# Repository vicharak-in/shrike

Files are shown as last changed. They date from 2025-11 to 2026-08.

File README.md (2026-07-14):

# Shrike 



Shrike is a family of low cost affordable FPGA development board along with a host microcontroller. 
Currently the family features these two members -: 

1. Shrike-lite (FPGA with RP2040) 
2. Shrike      (FPGA with RP2350)
3. Shrike-fi   (FPGA with ESP32-S3) 

And a lot version under development.

We usually work on very complex FPGA-based projects built around [Vaaman](https://vicharak.in/vaaman) and its upcoming series. However, Shrike is a passion project at Vicharak, driven by our love for engineering across both embedded microcontrollers and FPGAs.

Our goal is to make FPGAs accessible to everyone by offering robust toolchains, high-quality hardware, and strong ecosystem support. We’re committed to keeping the hardware prices extremely low, and every piece of software for Shrike will be completely open-source.

We at vicharak have kept in mind need of a learner, maker and a hobbyist while designing this art. This dev board will be your stepping stone in the field of FPGA, reconfigurable and heterogenous computing.

We invite contributors from all over the world to join us in this mission. Together, let’s make FPGA technology truly accessible to all. 

### Get the Hardware 

Shrike-lite the RP2040 version of the family is available at our store for worldwide shipping and the Shrike RP2350 version will be available on the crowdsupply soon. You can follow the links below to get both.

#### 1. [Shrike-lite](https://store.vicharak.in/?product=shrike&post_type=product&name=shrike&v=13b5bfe96f3e)

#### 2. [Shrike](https://www.crowdsupply.com/vicharak/shrike)

#### 3. [Shrike-fi](https://store.vicharak.in/?product=v002743)

### Board level Block Diagram

<div align="center">

shrike

</div>

### Key Features : 

| **Feature** | **Shrike** | **Shrike-lite** |**Shrike-fi** |
|:---:|:---:|:---:|:---:|
| FPGA | 1120 × 5-input LUTs | 1120 × 5-input LUTs | 1120 × 5-input LUTs|
| MCU | RP2350 | RP2040 | ESP32-S3 |
| PMOD Compatible Connector | ✅ | ✅ | ✅ |
| Breadboard Compatible | ✅ | ✅ | ✅ |
| FPGA ↔ MCU IO Interface | ✅ | ✅ | ✅ |  
| Flash (QSPI) | 4 MB | 4 MB | 8 MB |
| User LEDs | 2 | 2 | 2 |
| USB Type-C (Power & Programming) | ✅ | ✅ | ✅ |
| WiFi | ❌ | ❌ | ✅ |
| BLE | ❌ | ❌ | ✅ |
| Optional Add-on Features |
| PSRAM (QSPI) ( Optional ) | ❌ | ❌ | Upto 8 MB |
| BMS On Board ( Optional ) | ❌ | ❌ | ✅ | 

#### **Note**

The optional add on for the Shrike-fi are not soldered in the base version , board version with these part soldered will be launched at later date.
However you can solder them yourself in the base version as well read more [here](https://vicharak-in.github.io/shrike/hardware_overview.html#shrike-hardware-overview).

### Check out 
 1. [Documentation](https://vicharak-in.github.io/shrike/index.html)
 2. [Pin_outs](https://vicharak-in.github.io/shrike/shrike_pinouts.html)
 3. [FPGA_CPU_Interconnect](https://vicharak-in.github.io/shrike/shrike_pinouts.html#fpga-rp2040-communication-pin-outs)

## Shrike Projects

Want to see what people have built with Shrike , or show off your own build?

Check out **[shrike_projects](https://github.com/vicharak-in/shrike_projects)**.

The [`examples/`](examples/) folder here is focused on *teaching* , one
concept per example. Built something cool with your Shrike? Add it to the
projects repo , creative scope is unlimited.

Not sure which repo your contribution belongs in? See the
[classification criteria](EXAMPLE_OR_PROJECT.md).

## 📫 Join our communities at :
  
   [](https://discord.com/invite/EhQy97CQ9G)  &nbsp; [](https://x.com/Vicharak_In)  &nbsp; [](https://discuss.vicharak.in/)  &nbsp; [](https://www.linkedin.com/company/vicharak-in)  &nbsp; [](https://www.reddit.com/r/Vicharak/)  &nbsp;

### Note
 
We are building a ecosystem for learners , makers and hobbyist around shrike and the projects that will follow in future, thus we request you contribution in the same. Join our communities across all the platforms, pitch and showcase your ideas with Shrike. 

Thank You 

## Contribution Guideline  

Your contribution to the Shrike project are always welcome.
To contribute fork the project test your changes and create a PR. Few things in to keep in mind for better contribution. 
Please read the Contribution [Guide](./CONTRIBUTING.md) to know them.

### What to contribute ? 

You can contribute the project's and example's that you have designed on Shrike or any utils that you might have designed.

We also have live bounty from time to time check it [here](./bounty.md) 

## LICENSE 

### Software

This project’s software is licensed under the GNU General Public License v2.0 (GPL-2.0).
See the [LICENSE](./LICENSE.md)for details.

### Hardware

This project’s hardware designs (HDL/RTL, schematics, PCB files, constraints, etc.) are licensed under the CERN Open Hardware License v1.2.
See [LICENSE_HW](./LICENSE_HW.md) for details.

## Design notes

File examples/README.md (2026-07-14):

# Shrike Examples — Difficulty Reference

🟢 Beginner &nbsp;&nbsp; 🟡 Intermediate &nbsp;&nbsp; 🔴 Advanced

| # | Example | Folder Name | Category | Difficulty | Why |
|---|---|---|---|---|-----|
| 1 | LED Blink | `led_blink` | Getting Started | 🟢 Beginner | Single output signal, no state |
| 2 | Breathing LED | `breathing_led` | Getting Started | 🟢 Beginner | Simple PWM counter, single module |
| 3 | Button Debouncer | `button_debouncer` | Getting Started | 🟢 Beginner | Basic FSM, introduces synchronous logic |
| 4 | LED PMOD | `pmod_led_blink` | GPIO & I/O | 🟢 Beginner | Direct pin drive, PMOD pinout awareness |
| 5 | Logic Gates | `logic_gates` | Digital Logic | 🟢 Beginner | Pure combinational, no clock needed |
| 6 | 4-Bit Counter | `counter_4bit` | Signal & Timing | 🟢 Beginner | Sequential logic, introduces registers |
| 7 | PMOD Patterns | `pmod_patterns` | GPIO & I/O | 🟡 Intermediate | Sequenced output, simple state machine |
| 8 | GPIO Extender 8-Pin | `gpio_extender_8pin` | GPIO & I/O | 🟡 Intermediate | FPGA-to-RP2040 IO bridge, bus awareness |
| 9 | GPIO Extender 14-Pin | `gpio_extender_14pin` | GPIO & I/O | 🟡 Intermediate | FPGA-to-RP2040 IO bridge, wider bus |
| 10 | I2C LED | `i2c_led` | Communication Protocols | 🟡 Intermediate | I2C state machine, clock stretching awareness |
| 11 | SPI Loopback LED | `spi_loopback_led` | Communication Protocols | 🟡 Intermediate | SPI shift register, MISO/MOSI routing |
| 12 | UART LED | `uart_led` | Communication Protocols | 🟡 Intermediate | UART RX framing, baud clock generation |
| 13 | Morse Blink | `morse_blink` | Communication Protocols | 🟡 Intermediate | UART input, timing/state machine, serial-to-LED translation |
| 14 | UART ALU | `uart_alu` | Communication Protocols | 🟡 Intermediate | UART + datapath, multi-module design |
| 15 | PLL Oscillator | `pll_oscillator` | Signal & Timing | 🟡 Intermediate | PLL primitive instantiation, clock domain |
| 16 | PWM 4-Channel | `pwm_4ch` | Signal & Timing | 🟡 Intermediate | Multi-channel counter, duty cycle control |
| 17 | Ultrasonic Sensor | `ultrasonic_sensor` | Sensors & Peripherals | 🟡 Intermediate | Pulse timing, echo measurement FSM |
| 18 | WS2812 LED | `ws2812_led` | Sensors & Peripherals | 🟡 Intermediate | Precise bit-bang timing, serial protocol |
| 19 | Quadrature Decoder | `quadrature_decoder` | Sensors & Peripherals | 🟡 Intermediate | Quadrature decoding, direction detection, signed position/speed tracking |
| 20 | Protocol Translator | `protocol_translator` | Communication Protocols | 🟡 Intermediate | UART, SPI, and I2C protocol conversion through bridge logic |
| 21 | Stack Processor | `stack_processor` | Processors & CPUs | 🔴 Advanced | Custom ISA, stack-based execution, SPI host |
| 22 | Vector-4 CPU | `vector4_cpu` | Processors & CPUs | 🔴 Advanced | Full 4-bit SAP CPU: ALU, PC, registers, decode |
| 23 | Vector-8 CPU | `vector8_cpu` | Processors & CPUs | 🔴 Advanced | Full 8-bit SAP CPU: wider datapath, more opcodes |
| 24 | PicoRV32 RISC-V | `shrike_picorv32` | Processors & CPUs | 🔴 Advanced | Full RV32I soft CPU, runtime-programmable over SPI; fits the 1K-LUT fabric |

---

## Summary by Difficulty

| Difficulty | Count | Examples |
|---|---|---|
| 🟢 Beginner | 6 | `led_blink`, `breathing_led`, `button_debouncer`, `pmod_led_blink`, `logic_gates`, `counter_4bit` |
| 🟡 Intermediate | 14 | `pmod_patterns`, `gpio_extender_8pin`, `gpio_extender_14pin`, `i2c_led`, `spi_loopback_led`, `uart_led`, `morse_blink`, `uart_alu`, `pll_oscillator`, `pwm_4ch`, `ultrasonic_sensor`, `ws2812_led`, `quadrature_decoder`,`protocol_translator` |
| 🔴 Advanced | 4 |  `stack_processor`, `vector4_cpu`, `vector8_cpu`, `shrike_picorv32` |

---

---

## Looking for the bigger projects?

Application projects built on Shrike (Wi-Fi screen mirror, crypto mining,
spell autocorrector, seven-segment clock, and more) now live in their own
repo — moved with their **full commit history and contributor credit**:

**➡️ https://github.com/vicharak-in/shrike_projects**

This folder contains the curated *teaching examples*. Want a guided path
through them? See the Shrike FPGA Course.

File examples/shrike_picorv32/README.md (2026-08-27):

# shrike_picorv32

**Difficulty:** Advanced
**Uses MCU:** Yes
**External Hardware:** None

## Overview

This example runs Claire Wolf's [PicoRV32](https://github.com/YosysHQ/picorv32)
**RV32I** CPU on the SLG47910 ForgeFPGA of a Shrike-lite board, and makes it
**runtime-programmable**: the host MCU streams a program into the FPGA over SPI
and starts the CPU — no re-synthesis, no new bitstream. Flash the bitstream once,
then load and run any number of programs.

The full 32-register RV32I core fits the 1K-LUT-class fabric with both its
register file and a 32-word instruction memory in on-die BRAM, rewritten at
runtime over SPI. It ships a conformance suite — themed, self-checking programs
that together cover the complete RV32I base ISA — each reporting PASS/FAIL on two
GPIO pins the MCU reads back.

## Expected Output

```
Flashing PicoRV32 bitstream to FPGA...
[shrike_flash] FPGA programming done.
regalu: testing add sub sll srl sra and or xor slt sltu
result = 3 -> PASS  (verified: add sub sll srl sra and or xor slt sltu)
```

## Compatibility

| Board | MCU | Status |
|---|---|---|
| Shrike-lite | RP2040 | Tested and working |
| Shrike | RP2350 | Untested |
| Shrike-fi | ESP32-S3 | Untested |

> The FPGA bitstream is the same across all boards; only the MCU firmware pin
> map differs.

## Hardware Setup

No external hardware required. SPI and the two result pins are already wired
between the FPGA and the RP2040 on the Shrike-lite PCB:

| FPGA pin | Signal | RP2040 pin | Direction |
|---|---|---|---|
| GPIO3  | `spi_sck` | GPIO2  | MCU → FPGA |
| GPIO4  | `spi_ss_n` | GPIO1  | MCU → FPGA |
| GPIO5  | `spi_mosi` | GPIO3  | MCU → FPGA |
| GPIO17 | `result_bit0` | GPIO15 | FPGA → MCU |
| GPIO18 | `result_bit1` | GPIO14 | FPGA → MCU |

The FPGA never drives MISO — results come back on the two GPIO result pins — so
the CPU is reset and run entirely via SPI commands.

## How It Works

```
MCU --SPI--> spi_target --> bootloader --> instruction RAM (BRAM4..7, 32 words)
picorv32 <--mem bus--> instruction RAM      (fetch, 1-cycle wait)
picorv32 <--mem bus--> register file (BRAM0..3, 32 regs)
picorv32 --store 0x4xxxxxxx--> result latch --> GPIO17/18 --> RP2040
```

The MCU streams a program into the 32-word instruction RAM over SPI while the CPU
is held in reset, then releases it to run. Both the register file (BRAM0-3) and
the instruction RAM (BRAM4-7) live in on-die BRAM instead of fabric flip-flops,
which is what lets the full 32-register core fit. A store to any `0x4xxxxxxx`
address latches the low 2 bits onto the result pins (it clears on every reload).
Because the SLG47910 BRAM read is synchronous, the core carries a 1-cycle
read-latency fix (`CF1`) so register and instruction reads return valid data.

Sources: `picorv32.v` (core + `SHRIKE PATCH` size optimisations),
`shrike_picorv32_top.v` (top + SPI bootloader + result latch),
`picorv32_imem_bram.v` (instruction RAM), `picorv32_regs_bram.v` (register file).

## Quick Start (Pre-Built Bitstream)

Copy the bitstream to the board's filesystem and run the driver — with Thonny or
`mpremote`, whichever you prefer (the driver flashes the bitstream into the FPGA
itself at runtime, so the `.bin` just needs to be on the board).

**Thonny (GUI):** use the file panel to copy `bitstream/shrike_picorv32.bin` to
the board, then open `firmware/micropython/shrike_picorv32.py` and Run it.

**mpremote (CLI):** `pip install mpremote` (auto-detects the board):
```bash
mpremote fs cp bitstream/shrike_picorv32.bin :shrike_picorv32.bin
mpremote run firmware/micropython/shrike_picorv32.py
```

Either way, observe `result = 3 -> PASS` over USB serial. To run another part of
the suite, uncomment a different `ACTIVE = ...` line and re-run.

## Running & Editing Programs

Edit `shrike_picorv32.py` and re-run it (in Thonny, or `mpremote run` — which
executes your local copy, so no re-copy needed). Uncomment a different
`ACTIVE = ...` line to switch tests, or add your own program to `TESTS` (below).
To run standalone at boot (no host attached), save the file on the board as
`main.py`.

## Build From Source

### Step 1 — Open in Go Configure

Launch Go Configure Software Hub and open the included `shrike_picorv32.ffpga`
(target chip **SLG47910 (BB)**). It lists every source in order and holds the
complete pinout. From scratch, add the sources with the top module last:
`picorv32_regs_bram.v`, `picorv32.v`, `picorv32_imem_bram.v`, `spi_target.v`,
`shrike_picorv32_top.v`.

### Step 2 — Enable BRAM

The register file uses BRAM0-3 and the instruction RAM uses BRAM4-7, so enable
**both** BRAM banks (North = BRAM0-3, South = BRAM4-7). The BRAM ports and bank
clock feeds must also be pinned — the committed `.ffpga` holds all of these.

### Step 3 — Clock + generate

The fabric runs from the PLL at 25 MHz (the `pll_*` pins program it from fabric
logic, per Renesas AN-003; dividers give `50 MHz × 21 / (1×7×6) = 25 MHz`). Click
**Synthesize** then **Generate Bitstream**, and copy the produced
`FPGA_bitstream_MCU.bin` to `bitstream/shrike_picorv32.bin`.

## The RV32I Conformance Suite

`firmware/micropython/shrike_picorv32.py` holds several themed, self-checking
≤32-word programs in a `TESTS` dictionary. Together they cover the complete RV32I
base ISA — all 37 instructions:

| Program (`ACTIVE`) | Instructions tested |
|---|---|
| `regalu` | add sub sll srl sra and or xor slt sltu |
| `immalu` | addi slli srli srai andi ori xori slti sltiu lui auipc |
| `branch` | beq bne blt bge bltu bgeu (taken **and** not-taken) |
| `jumps`  | jal jalr (transfer **and** link register) |
| `loads`  | lw lh lhu lb lbu (sign/zero-extension) |
| `store_sw` / `store_sh` / `store_sb` | sw / sh / sb |

Pick one with an `ACTIVE = ...` line and run. A pass latches **3** (both bits);
`1` = ran but wrong value, `0` = never reached the store (trap/hang). Each program
was validated so injecting a fault into any instruction it tests makes it stop
returning 3, so a pass confirms those instructions are correct.

To run your own program, add a `name: (description, [words])` entry to `TESTS`,
point `ACTIVE` at it, and re-run — no re-synthesis. Programs are capped at **32
words** (`PC_W = 7` in `picorv32.v`, an area optimisation matching the instruction
RAM depth). The 2 result bits give a readable range of 0-3.

## PicoRV32 Configuration

Locked parameters in `shrike_picorv32_top.v` for a minimal full-RV32I build:

| Parameter | Value | Reason |
|---|---|---|
| `ENABLE_REGS_16_31` | 1 | full RV32I — all 32 registers |
| `ENABLE_REGS_DUALPORT` | 0 | single read port — matches the BRAM regfile |
| `BARREL_SHIFTER` | 0 | serial shift — avoids a 32-bit mux tree |
| `COMPRESSED_ISA` | 0 | no RVC decoder |
| `CATCH_MISALIGN` / `CATCH_ILLINSN` | 0 | no trap logic |
| `ENABLE_MUL` / `DIV` / `IRQ` / `COUNTERS` | 0 | no M-ext / IRQ / CSR counters |

The core in `picorv32.v` also carries the `SHRIKE PATCH` size optimisations (BRAM
register file, shared-adder datapath, 7-bit PC, narrowed memory interface) plus
two correctness fixes (`CF1` read-latency wait-state, `CF2` ECALL/EBREAK halt);
`grep "SHRIKE PATCH"` / `grep "CORRECTNESS FIX"` finds every site.

## Licence

PicoRV32 retains its original ISC licence (header preserved in `picorv32.v`). All
Shrike-specific additions (the `SHRIKE PATCH` optimisations, BRAM register file,
instruction RAM, SPI bootloader, top wrapper, firmware, docs) are GPL-2.0 to match
the rest of this repo.

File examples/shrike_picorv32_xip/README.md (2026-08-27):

# shrike_picorv32_xip

**Difficulty:** Advanced
**Uses MCU:** Yes
**External Hardware:** None

## Overview

A [PicoRV32](https://github.com/YosysHQ/picorv32) **RV32I** CPU on the SLG47910
ForgeFPGA that **executes in place from 64 KB of RAM** — enough to run real
compiled C programs, not just short instruction sequences. The FPGA is the SPI
*master* and fetches every instruction over SPI from a RAM emulated by the
board's own RP2040, so the program is never copied into the FPGA; it runs from
where it lives (**XIP** = eXecute In Place).

This is the large-program companion to the [`shrike_picorv32`](../shrike_picorv32)
example. That one loads ≤32-instruction programs into on-chip BRAM; this one
removes that ceiling — write a C program, run one command, watch it execute on
the FPGA.

## Compatibility

| Board | Firmware | Status |
|---|---|---|
| Shrike-Lite (RP2040) | `firmware/rp2040/` | ✅ Tested |
| Shrike (RP2350) | `firmware/rp2040/` | ⬜ Untested |
| Shrike-fi (ESP32-S3) | — | ⬜ Not supported |

> The FPGA bitstream is the same across boards. The host firmware is **not**
> MicroPython: the RAM emulator is PIO + chained DMA + a dedicated core, so it
> ships as a pico-sdk C program (with a pre-built `.uf2`). ESP32-S3 has no
> equivalent PIO and is not supported.

## Hardware Setup

No external hardware required. The FPGA↔RP2040 SPI bus is already wired on the
board. Note the roles are reversed from most examples: here the **FPGA drives
SCK/CS/MOSI** (it is the master) and the RP2040 answers on MISO with RAM data.

## Quick Start (Pre-Built Bitstream)

The RP2040 both hosts the RAM and configures the FPGA, so setup is a one-time
firmware flash — the FPGA bitstream is embedded in it.

> **This replaces MicroPython** on the RP2040 (unlike other examples, which run
> *on* MicroPython). The board's flash is a single UF2 slot, so this firmware
> takes it over while the example runs. Restoring MicroPython is a normal
> reflash — see below.

1. Put the board in BOOTSEL (hold BOOTSEL, tap RESET) so `RPI-RP2` appears.
2. Copy `firmware/rp2040/shrike_xip.uf2` onto it. The board reboots and
   configures the FPGA automatically.
3. Run a program:
   ```bash
   cd programs
   ./run.py demo.c
   ```
   `run.py` compiles the C, loads it into the emulated RAM, releases the CPU,
   and prints the program's output. See [`programs/README.md`](programs/README.md).

Expected result: the demo prints its self-checks and ends with `ALL OK`.

### Restoring MicroPython

To go back to the stock environment (to run the MicroPython examples again),
put the board in BOOTSEL and copy the standard Shrike MicroPython UF2 onto it —
download the one for your board from the Shrike
[Releases](https://github.com/vicharak-in/shrike/releases/) (also kept in this
repo under `archive/firmware/`). That's the whole process; it overwrites this
firmware and MicroPython is back at the next boot.

## Build From Source

### FPGA (Verilog)
1. Open `shrike_picorv32_xip.ffpga` in Go Configure Software Hub.
2. Synthesize → Generate Bitstream.
3. Copy the produced `FPGA_bitstream_MCU.bin` to
   `bitstream/shrike_picorv32_xip.bin`.

The project runs the fabric from the PLL at 25 MHz (the `pll_*` pins program it
from fabric logic, per Renesas AN-003), and pins all BRAM ports and result
signals — the committed `.ffpga` holds the complete, correct pinout.

### Firmware (pico-sdk C)
Only needed if you change the host code; the pre-built `shrike_xip.uf2` is
committed. With [pico-sdk](https://github.com/raspberrypi/pico-sdk) installed:
```bash
cd firmware/rp2040
mkdir build && cd build
cmake .. && cmake --build .
```
`shrike_xip.uf2` is produced; drag it onto the board in BOOTSEL. CMake embeds
`bitstream/shrike_picorv32_xip.bin` into the firmware automatically.

## How It Works

```
RP2040 (SPI-RAM emulator, 64 KB)  <--SPI-->  FPGA
   PIO + DMA answer read/write frames         spi_xip_master  (SPI master)
                                                    |  picorv32 mem bus
                                              picorv32  (RV32I, PC_W=16)
                                              register file in BRAM0-3
```

- **`spi_xip_master.v`** bridges PicoRV32's memory bus to a SPI master. Every
  instruction fetch and data access becomes a SPI transaction to the external
  RAM (mode 0, command `0x03` read / `0x02` write, 16-bit address). The CPU
  runs slower than from local memory but is limited only by the 64 KB space.
- **`picorv32.v`** is the same core as the `shrike_picorv32` example (register
  file in BRAM0-3, shared-adder datapath) with the program counter widened to
  16 bits (`PC_W = 16`) so it can address the full 64 KB.
- **The RP2040** (`firmware/rp2040/`) plays two roles: at boot it configures the
  FPGA from the embedded bitstream, then it emulates the 64 KB SPI RAM
  (`sram.c` / `sram.pio`, vendored from
  [MichaelBell/spi-ram-emu](https://github.com/MichaelBell/spi-ram-emu)) and
  relays the program's console output to USB. A program signals completion by
  storing to a status word; the CPU's console is bytes stored to `0xF000`.

There is no address decode in the FPGA — the SPI master *is* the bus, and
`mem_addr[15:0]` maps straight to the 64 KB RAM.

## Expected Output

```
XIP compiled-C demo
fib(18)      = 2584
primes<512   = 97
sorted       = yes
checksum     = 167433
chk/7, chk%7 = 23919, 0
ALL OK
```

The demo (`programs/demo.c`) exercises recursion (a real call stack), arrays and
structs in RAM, insertion sort, and software multiply/divide — GCC-compiled code,
not hand-written vectors — in ~2 KB of the 64 KB space.

## Licence

PicoRV32 retains its original ISC licence and the RAM emulator (`sram.c` /
`sram.pio`) its BSD-3 licence (headers preserved in each file). All
Shrike-specific additions (the `SHRIKE PATCH` optimisations, the SPI XIP master,
top wrapper, host firmware, and docs) are GPL-2.0 to match the rest of this repo.

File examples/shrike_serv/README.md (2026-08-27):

# shrike_serv

**Difficulty:** Advanced
**Uses MCU:** Yes
**External Hardware:** None

---

## Overview

This example runs Olof Kindgren's [SERV](https://github.com/olofk/serv) — the
award-winning **bit-serial RV32I** soft CPU, "the world's smallest RISC-V" — on
the SLG47910 ForgeFPGA of a Shrike-lite board, and makes it
**runtime-programmable**: the host MCU streams an RV32I program into the FPGA
over SPI and starts the CPU — **no re-synthesis, no new bitstream**. Flash the
bitstream once, then load and run any number of programs.

SERV runs one bit per clock, so it is slow (~40–80 cycles per instruction) but
tiny. Its register file sits in fabric distributed RAM, which leaves all 8 BRAM
slices free for one unified **4 KB** memory — enough to run real programs, not
just hand-written snippets. The whole example — CPU, memory, and a UART monitor —
fits in **138 of the 140 CLBs**.

**One bitstream, three things to do** — the same bitstream runs whatever you load:

1. **The rv32ui conformance suite** — the official RISC-V per-instruction tests,
   run on silicon (**41/41**), proving the complete RV32I base ISA works.
   → [Quick Start](#quick-start-pre-built-bitstream)
2. **Your own compiled C** — write C, `programs/run.py` builds it and runs it on
   the CPU. → [Writing Your Own Programs (C)](#writing-your-own-programs-c)
3. **An interactive `serv>` monitor** — a shell you drive from your terminal over
   the board's UART: `fib`, `primes`, `calc`, `peek`/`poke` memory, `led`, a
   guessing game, and more. → [Interactive Monitor](#interactive-monitor)

## Expected Output

```
Flashing SERV bitstream to FPGA...
[shrike_flash] FPGA programming done.
  PASS  add
  PASS  addi
  ...
  PASS  xor
  PASS  xori
-------------------------------------------
SERV rv32ui on hardware: PASS=41 FAIL=0 DEAD=0 / 41
ALL RV32UI TESTS PASSED ON HARDWARE
```

---

## Compatibility

| Board | MCU | Status |
|---|---|---|
| Shrike-lite | RP2040 | Tested and working |
| Shrike | RP2350 | Untested |
| Shrike-fi | ESP32-S3 | Untested |

> The FPGA bitstream is the same across all boards; only the MCU firmware pin
> map differs.

---

## Hardware Setup

No external hardware required. Everything is already wired between the FPGA and
the RP2040 on the Shrike-lite PCB:

| FPGA pin | Signal | RP2040 pin | Direction |
|---|---|---|---|
| GPIO3  | `spi_sck` | GPIO2  | MCU → FPGA (program load) |
| GPIO5  | `spi_mosi` | GPIO3  | MCU → FPGA (program load) |
| GPIO4  | `spi_ss` / `uart_tx` | GPIO1  | shared: SPI select while loading, then UART TX (FPGA → MCU) |
| GPIO6  | `uart_rx` | GPIO0  | MCU → FPGA (UART, RP2040 UART0 TX) |
| GPIO17 | `result_bit0` | GPIO15 | FPGA → MCU (suite / C flow) |
| GPIO18 | `result_bit1` | GPIO14 | FPGA → MCU (suite / C flow) |
| GPIO16 | `led` | — | on-board FPGA LED |

The SPI pins match the `shrike_picorv32` example. **Pin sharing (GPIO4):**
program-load needs an SPI chip-select and the interactive monitor needs a UART
TX; they never happen at once (the CPU is held in reset during load). So GPIO4 is
the SPI select while loading, then becomes the UART TX once the core runs
(`o_uart_tx_oe = cpu_run`). The RP2040 mirrors this: GPIO1 is the SPI CS during
load, then its UART0 RX during a monitor session. Both idle high, so the handover
has no bus contention. The conformance suite and C flow simply never use the
UART; the monitor never uses the result pins.

---

## How It Works

```
MCU --SPI--> bootloader --> 4 KB memory (all 8 BRAM slices)
SERV <--wb_mem--> memory            (fetch + load/store)
SERV <--wb_ext--> MMIO              (result latch, UART, LED)  -> GPIO / RP2040
SERV <--dist RAM--> register file
```

The MCU streams a program into the unified 4 KB BRAM over SPI while the CPU is held
in reset, then releases the core to run it. SERV keeps its register file in
distributed RAM, which frees all 8 BRAM slices for that one memory. A small block
of memory-mapped registers at `0x4000_0000` carries the pass/fail result latch (the
suite and C flow report through it, read back on GPIO), a UART (the monitor), and
the LED.

Sources: `shrike_serv_top.v` (top + SPI bootloader + MMIO), `serv_mem_bram.v`
(the 4 KB memory), `serv_rf_ram.v` (register file), `uart_tx.v` / `uart_rx.v`, and
the vendored SERV core (`serv_*.v`, `servile*.v`).

---

## Quick Start (Pre-Built Bitstream)

Copy the bitstream and tests to the board, then run the driver — with Thonny or
`mpremote`, whichever you prefer (the driver flashes the bitstream into the FPGA
itself, so the `.bin` just needs to be on the board).

**Thonny (GUI):** use the file panel to copy `bitstream/shrike_serv.bin`,
`firmware/micropython/shrike_serv.py`, and the `firmware/micropython/serv_tests/`
folder to the board, then open `shrike_serv.py` and Run it.

**mpremote (CLI):** `pip install mpremote` (auto-detects the board):
```bash
mpremote fs cp bitstream/shrike_serv.bin :shrike_serv.bin
mpremote fs cp -r firmware/micropython/serv_tests :
mpremote run firmware/micropython/shrike_serv.py
```

Either way, observe `SERV rv32ui on hardware: PASS=41 FAIL=0 DEAD=0 / 41`. For a
single test, `import shrike_serv` and call `run_test("serv_tests/add.bin")`
(returns `3` for PASS).

---

## Running & Editing the Suite

`shrike_serv.bin`, `shrike_serv.py`, and the `serv_tests/` folder live on the board
filesystem — copy them there once (Thonny's file panel, or `mpremote fs cp`).
Running `shrike_serv.py` flashes the bitstream and sweeps all 41 tests. For a
single test, `import shrike_serv` and call `run_test("serv_tests/add.bin")` (it
returns `3` for PASS). To run at boot with no host attached, copy `shrike_serv.py`
to the board as `main.py`.

---

## The RV32I Conformance Suite

`firmware/micropython/serv_tests/` holds 41 program images — the official
[`riscv-tests`](https://github.com/riscv-software-src/riscv-tests) `rv32ui`
suite, one test per instruction, built for RV32I (`-march=rv32i`) and linked to
this SoC's 4 KB memory map. **Together they cover the complete RV32I base ISA:**

| Group | Tests |
|---|---|
| Register-register ALU | `add` `sub` `and` `or` `xor` `sll` `srl` `sra` `slt` `sltu` |
| Register-immediate ALU | `addi` `andi` `ori` `xori` `slli` `srli` `srai` `slti` `sltiu` |
| Upper immediate | `lui` `auipc` |
| Branches | `beq` `bne` `blt` `bge` `bltu` `bgeu` |
| Jumps | `jal` `jalr` |
| Loads | `lb` `lbu` `lh` `lhu` `lw` |
| Stores | `sb` `sh` `sw` |
| Memory ordering | `ld_st` `st_ld` `fence_i` |
| Sanity | `simple` |

Each upstream test is self-checking: it computes known values, compares against
expected results, and branches to a fail path on any mismatch. This example
replaces the tests' trap-based reporting with a tiny memory-mapped convention —
`RVTEST_PASS` stores `1` to `0x40000000`, `RVTEST_FAIL` stores a non-`1` value —
so the verdict appears on the 2-bit GPIO result latch (**3 = PASS, 1 = FAIL,
0 = DEAD**) with no trap handler or data RAM needed. The test *bodies* are the
unmodified upstream vectors.

---

## Writing Your Own Programs (C)

The 4 KB memory is large enough to run compiled C, so `programs/` provides an
edit-compile-run loop on top of the same bitstream — **no re-synthesis**. Write a
normal C program with `int main(void)` (return `0` for PASS) and:

```bash
cd programs
./run.py demo.c                 # compile, load onto the board, run, report PASS/FAIL
./run.py demo.c --compile-only  # just build the .bin (no board needed)
```

`crt0.S` turns `main()`'s return value into the 2-bit result latch the board
reads back, so structure the program so a wrong answer changes the return value.
The bundled `demo.c` is a self-check covering recursion, an in-place sort, a
prime sieve, and libgcc multiply/divide. See `programs/README.md` for the full
flow, the 4 KB budget, and toolchain requirements.

---

## Interactive Monitor

A `serv>` shell on the CPU that you drive from your terminal. From this example's
directory (`examples/shrike_serv`):

```bash
python3 programs/serv_shell.py
```

Type commands, the CPU answers:

```
serv> fib 20
6765
serv> primes 100
25
serv> calc 6*7
42
serv> led on
led on
serv> guess
1..100, blank to give up
? 50
lower
? 42
correct!
```

UP/DOWN recall recent commands. Exit with `quit`, Ctrl-D, or Ctrl-C. Full command
list: **[programs/COMMANDS.md](programs/COMMANDS.md)**.

Needs Python 3 + `pyserial` (`pip install pyserial`), and a riscv gcc the first
run. To add your own command, edit `programs/monitor.c` and rerun
`programs/run.py monitor.c --shell`.

---

## Build From Source

### Step 1 — Open in Go Configure

Launch Go Configure Software Hub, **New Project**, target chip **SLG47910 (BB)**
— or open the included `shrike_serv.ffpga` directly to skip manual setup. The
project file lists every source in the correct order and holds the complete
pinout; opening it is the reliable path.

If rebuilding from scratch, add the Verilog sources with the top module **last**:
the vendored SERV core (`serv_*.v` and `servile*.v`), then this example's
`serv_mem_bram.v`, `spi_target.v`, `uart_tx.v`, `uart_rx.v`, and finally
`shrike_serv_top.v`.

### Step 2 — Enable BRAM

The unified memory uses all eight BRAM slices, so enable **both** BRAM banks
(North = BRAM0-3, South = BRAM4-7) in the project's BRAM configuration. Enabling
the banks is necessary but **not sufficient** — the BRAM ports and bank clock
feeds must also be pinned (Step 3).

### Step 3 — Pin assignment

Opening the included `shrike_serv.ffpga` gives the complete, correct pinout; this
step describes it for a from-scratch build.

The user-facing pins:

| Signal | Resource |
|---|---|
| `clk` | `PLL_CLK` |
| `clk_en` | `OSC_EN`  |
| `spi_sck`  | `GPIO3` |
| `i_spi_ss` / `o_uart_tx` / `o_uart_tx_oe` (shared pad) | `GPIO4` |
| `spi_mosi` | `GPIO5` |
| `i_uart_rx` | `GPIO6`  |
| `o_led` (+`_oe`) | `GPIO16` |
| `result_bit0` / `result_bit1` (+`_en`) | `GPIO17` / `GPIO18` |

`i_spi_ss`, `o_uart_tx`, and `o_uart_tx_oe` are three ports on the **same** GPIO4
pad (SPI select in while loading, UART TX out while running). Also pin every
`BRAMx_*` port and both bank clock feeds
(`REF_BRAM(0..3)/(4..7)_WRITE_CLK` and `_READ_CLK` → `clk`) so the block RAM is
wired and clocked, and the `pll_*` control pins (27) that program the PLL. The
committed `.ffpga` holds all of these; use it as the reference.

### Step 3b — Clock the fabric at 25 MHz

The fabric runs from the PLL at 25 MHz. The PLL is enabled and programmed from
fabric logic (`pll_en`, `pll_refdiv`, `pll_fbdiv`, `pll_postdiv1`,
`pll_postdiv2` — see `shrike_serv_top.v` and Renesas AN-003); the dividers give
`50 MHz × 21 / (1×7×6) = 25 MHz`.

### Step 4 — Synthesize and generate bitstream

Click **Synthesize** then **Generate Bitstream**. Copy the produced
`FPGA_bitstream_MCU.bin` to `bitstream/shrike_serv.bin`.

---

## SERV Configuration

SERV is instantiated through its `servile` convenience wrapper (core + bus
arbiter + address mux + register-file interface) in `shrike_serv_top.v`:

| Parameter | Value | Reason |
|---|---|---|
| `width` | 1 | **Bit-serial** — one bit per clock, the smallest datapath |
| `with_csr`  | 1 | CSRs present (needed by the `riscv-tests` env) |
| `with_mdu`  | 0 | no M extension (no hardware multiply/divide) |
| `with_c` | 0 | no compressed (RVC) decoder |
| `reset_pc`  | 0 | execution starts at address 0 |
| `sim` | 0 | hardware build — no simulation-only MMIO |

The register file (`serv_rf_ram.v`) is mapped to fabric distributed RAM; the
unified BRAM memory (`serv_mem_bram.v`), the SPI bootloader, the result latch, and
the memory-mapped UART/LED/cycle-counter (`shrike_serv_top.v`) are this example's
additions. The UART is a pair of minimal fixed-8N1 cores (`uart_tx.v` /
`uart_rx.v`) kept small to fit alongside the CPU. The SERV core files are the
unmodified upstream sources with their ISC headers preserved.

---

## Licence

SERV retains its original ISC licence (`ffpga/src/serv_LICENSE`, and the headers
preserved at the top of each `serv_*.v` / `servile*.v` file). All Shrike-specific
additions (the unified BRAM memory, SPI bootloader, top wrapper, firmware, docs)
are GPL-2.0 to match the rest of this repo.

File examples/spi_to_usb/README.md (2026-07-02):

# spi_to_usb

**Difficulty:** Intermediate

**Uses MCU:** Yes

**External Hardware:** Arduino Uno (external SPI master)

## Overview

This example turns the Shrike board into an **SPI-to-USB bridge**. The Arduino Uno acts as an external SPI master, sending bytes to the FPGA. The FPGA captures these bytes as an SPI target and forwards them over a second SPI link to the RP2040, which then sends them to the PC over USB serial.

You will learn how to interface the FPGA with an external SPI master and pass data through the internal RP2040 link to a host PC.

## Compatibility

| Board | Firmware | Status |
| --- | --- | --- |
| Shrike-Lite (RP2040) | `firmware/micropython/` | ✅ Tested |
| Shrike (RP2350) | `firmware/micropython/` | ⚪ Untested |
| Shrike-fi (ESP32-S3) | `firmware/micropython/` | ⚪ Untested |

> FPGA bitstream is the same across all boards.

## Hardware Setup

An Arduino Uno is used as the external SPI master. The Uno is a 5 V device, so the signals driving the FPGA (`ext_sck`, `ext_mosi`, `ext_ss_n`) must be level-shifted from 5 V down to 3.3 V using resistor dividers.

### FPGA Connections (link to RP2040 — FPGA is slave)

| FPGA GPIO Pin | Signal Name | Direction | Description |
| --- | --- | --- | --- |
| 3 | `spi_sck` | Input | SPI clock |
| 4 | `spi_ss_n`  | Input | Chip select (active low) |
| 5 | `spi_mosi`  | Input | MOSI (receive) |
| 6 | `spi_miso`  | Output | MISO (transmit) |
| 16 | `led` | Output | LED (shows last byte) |

### FPGA Connections (link to Arduino — FPGA is slave)

Note: FPGA_IO8 (FPGA GPIO8) is a PMOD Connector Pin
| FPGA GPIO Pin | Signal Name | Direction | Description |
| --- | --- | --- | --- |
| 0 | `ext_sck` | Input | SPI clock from master (via divider) |
| 1 | `ext_mosi` | Input | Master output (via divider) |
| 7 | `ext_ss_n` | Input | Chip select (via divider) |
| 8 | `ext_miso` | Output | Master input (no divider needed) |

### RP2040 Connections

| RP2040 Pin | Signal Name | Direction | Description |
| --- | --- | --- | --- |
| 2 | SCK | Output | SPI clock |
| 1 | CS | Output | Chip select |
| 3 | MOSI | Output | Master output |
| 0 | MISO | Input | Master input  |

### Arduino Uno Connections (external master)

| Arduino Pin | Signal Name | Direction | Connects to FPGA |
| --- | --- | --- | --- |
| D13 | SCK | Output | `ext_sck` (GPIO 0)  |
| D11 | MOSI | Output | `ext_mosi` (GPIO 1) |
| D12 | MISO | Input | `ext_miso` (GPIO 8) |
| D10 | SS | Output | `ext_ss_n` (GPIO 7) |
| GND | GND | — | Common ground |

### Level Shifting

The Arduino Uno drives SCK, MOSI, and SS at 5 V. Use a resistor divider (e.g. 1.8 kΩ series / 3.3 kΩ to ground) on each of these lines before they reach the 3.3 V FPGA inputs. The FPGA output (`ext_miso`) at 3.3 V is read fine by the Uno.

## Quick Start (Pre-Built Bitstream)

1. Connect the Shrike board via USB.
2. Open `firmware/arduino-ide/spi_to_usb.ino` in the Arduino IDE, upload it to the Uno, and open its Serial Monitor at 115200 baud.
3. Open `firmware/micropython/spi_to_usb.py` in Thonny and run it on the RP2040. This will automatically flash `bitstream/spi_to_usb.bin`.
4. Expected result: the bytes sent from the Arduino appear on the Thonny console, confirming the data path: Arduino → FPGA → RP2040 → PC.

## Build From Source

### FPGA (Verilog)

1. Open the project in Go Configure Software Hub.
2. Ensure `top_arduino_master.v` and `spi_target.v` from `ffpga/src/` are included.
3. Configure the I/O mapping as listed in the tables above.
4. Generate the bitstream.

## How It Works

The data path is: **Arduino (SPI master) → FPGA → RP2040 → PC USB**.

1. **`top_arduino_master.v`**: Contains two `spi_target` instances. One receives bytes from the Arduino, the other serves the last received byte to the RP2040.
2. **`spi_target.v`**: A robust SPI slave implementation that synchronizes asynchronous SPI signals (SCK, SS) into the system clock domain.

## Expected Output

- The Arduino Serial Monitor will show the sent bytes.
- The Thonny console connected to the RP2040 will show the received bytes matching the sent bytes.

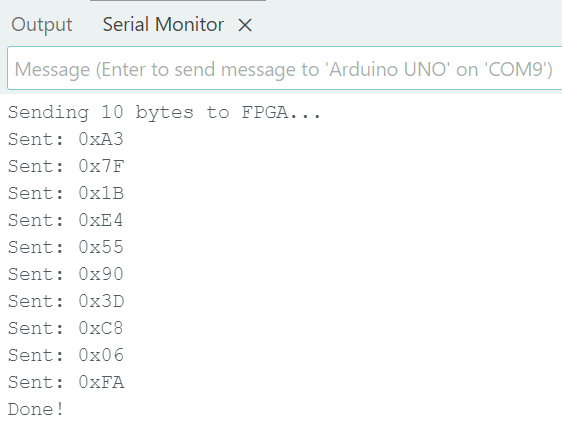
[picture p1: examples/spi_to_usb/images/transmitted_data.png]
Transmitted data


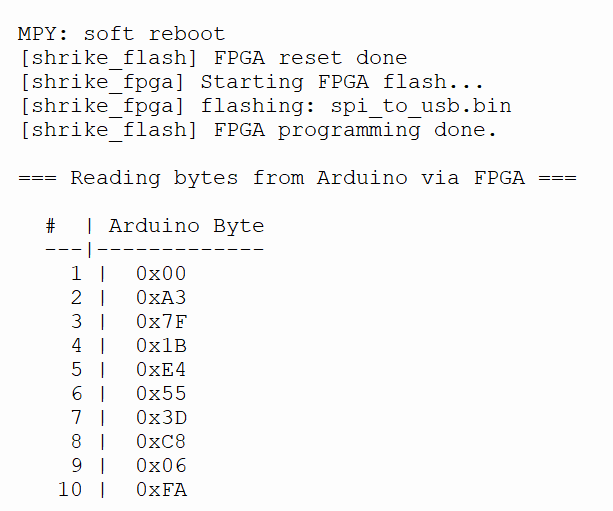
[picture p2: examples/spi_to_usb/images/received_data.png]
Received data


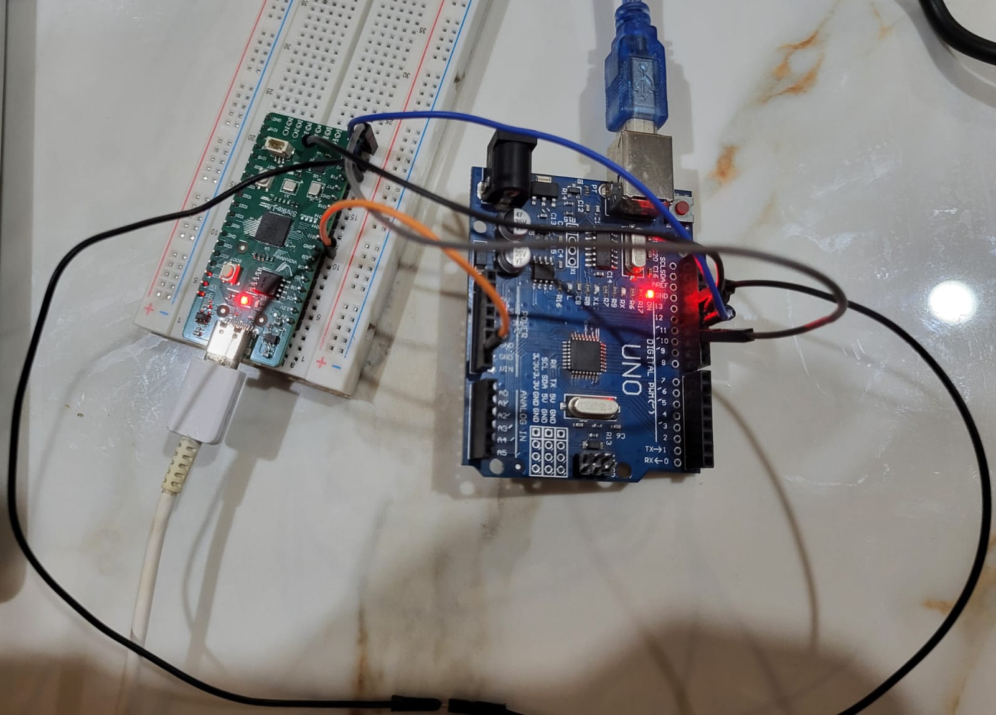
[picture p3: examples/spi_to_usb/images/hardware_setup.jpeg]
Hardware setup


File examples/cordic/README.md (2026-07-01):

# cordic_coprocessor
**Difficulty:** Advanced
**Uses MCU:** Yes
**External Hardware:** None

## Overview
A 4-mode fixed-point cordic implemented on the shrike lite. The RP2040 sends a single 8-bit SPI command and reads back the result on the next transaction. Three modes use a CORDIC circular rotation engine for sine, cosine, and tangent. The fourth mode is a shift-and-add integer multiplier. All arithmetic runs in Q1.6 fixed-point, valid for angles from 0 to 45 degrees.

## Compatibility
| Board | Firmware | Status |
| --- | --- | --- |
| Shrike-Lite (RP2040) | `firmware/micropython/` | ✅ Tested |
| Shrike (RP2350) | `firmware/micropython/` | ⬜ Untested |
| Shrike-fi (ESP32-S3) | `firmware/micropython/` | ⬜ Untested |

> FPGA bitstream is the same across all boards.

## Hardware Setup
No external hardware required.

### FPGA

| FPGA GPIO Pin | Signal | Direction | Description |
| --- | --- | --- | --- |
| 3 | spi_sck  | Input | SPI clock |
| 4 | spi_ss_n | Input | Chip select |
| 5 | spi_mosi | Input | MOSI |
| 6 | spi_miso | Output | MISO |
| 18 | rst_n | Input | Reset |

---

### RP2040

| RP2040 Pin | Signal | Direction | Description |
| --- | --- | --- | --- |
| 2 | SCK | Output | SPI clock |
| 1 | CS | Output | Chip select |
| 3 | MOSI | Output | Master output |
| 0 | MISO | Input | Master input  |
| 14 | Reset  | Output | Reset |

> Ensure pin mapping in FPGA constraints matches firmware configuration.

---

## Quick Start (Pre-Built Bitstream)
1. Connect Shrike Lite via USB
2. Upload `bitstream/cordic_coprocessor.bin` using ShrikeFlash
3. Run `test_cordic.py` on the RP2040
4. Enter a mode (`cos`, `sin`, `tan`, `mul`) and provide the operand

---

## Build From Source

### FPGA (Verilog)
1. Open project in Go Configure Software Hub
2. Add modules: `top`, `cordic_circular`, `cordic_divide`, `cordic_multiply`, `spi_target`
3. Configure I/O mapping
4. Generate bitstream

### Firmware (MicroPython)
1. Use SPI to send instruction bytes
2. Observe returned values

---

## How It Works

### Packet Format
The RP2040 sends one 8-bit command byte. The top 2 bits select the mode, the lower 6 bits carry the operand.

```
[ 7:6 ]  mode select
[ 5:0 ]  operand

Trig  : bits[5:0] = angle in Q1.6  (valid range: 0 to 45 degrees)
MUL   : bits[5:3] = operand A (3-bit signed), bits[2:0] = operand B (3-bit signed)
```

### Modes
| Mode | Operation | Engine |
| ---- | --- | --- |
| 00 | Cosine | CORDIC circular rotation |
| 01 | Sine | CORDIC circular rotation |
| 10 | Multiply  | Shift-and-add (3-bit operands)  |
| 11 | Tangent | Cascaded sin/cos divider |

### Module Breakdown

#### `top`
Decodes the incoming SPI byte, generates a one-cycle start strobe, routes the operand to the correct engine, and muxes the result back to the SPI TX register.

#### `cordic_circular`
CORDIC rotation mode over 7 iterations. Computes sin and cos simultaneously. Accumulators are extended to 12-bit internally to prevent overflow. Angle input uses zero-padding on the top 2 bits — sign extension caused angles above 30° to be misinterpreted as negative during intermediate subtractions.

#### `cordic_divide`
CORDIC linear vectoring mode. Used for tangent by dividing the sine output by the cosine output. Triggered automatically by `circ_done` when mode 11 is active.

#### `cordic_multiply`
Shift-and-add multiplier over 3 iterations. Handles 3-bit signed operands packed into the lower 6 bits of the command byte.

#### `spi_target`
Configurable SPI peripheral (CPOL, CPHA, width, bit order). Synchronizes SCK and SS into the system clock domain with a 3-stage pipeline before processing.

---

### Output

```
CORDIC Coprocessor  |  angle range: 0 to 45 deg                                 
                                                                                
  cos  sin  tan  mul  exit                                                      
                                                                                
> cos                                                                           
angle (deg) > 20                                                                
  fpga 0.9063  ref 0.9397  err 0.033443                                         
> sin                                                                           
angle (deg) > 30                                                                
  fpga 0.5000  ref 0.5000  err 0.000000                                         
> mul                                                                           
a (3-bit signed, -4 to 3) > -3                                                  
b (3-bit signed, -4 to 3) > 2                                                   
  fpga -6.0000  ref -6.0000  err 0.000000                                       
> 
```

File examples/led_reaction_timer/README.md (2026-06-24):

# LED Reaction Timer

**Difficulty:** Beginner  
**Uses MCU:** Yes  
**External Hardware:** None

## Overview

A reaction-time trainer that lights an LED after a pseudo-random delay of 0 to N seconds.
Press Enter on your terminal the moment the LED fires and your reaction time is printed in milliseconds.
Uses PRNG seeding using lfsr and counters.
No other external hardware is used other than the onboard led.

> **Note:** This is a PRNG (Pseudo-Random Number Generator) based design.

## Compatibility

| Board | Firmware | Status |
|---|---|---|
| Shrike-Lite (RP2040) | `firmware/micropython/` | ✅ Tested |
| Shrike (RP2350) | `firmware/arduino-ide/` | ⬜ Untested |
| Shrike-fi (ESP32-S3) | `firmware/arduino-ide/` | ⬜ Untested |

> FPGA bitstream is the same across all boards.

## Hardware Setup
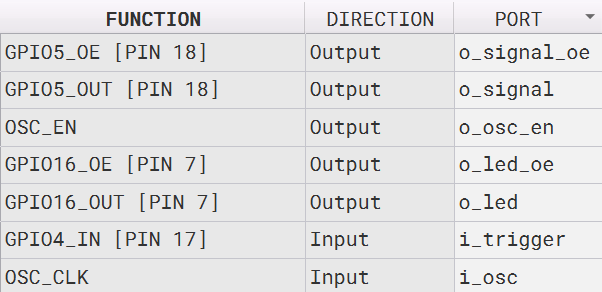
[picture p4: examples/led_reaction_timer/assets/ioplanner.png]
IOPLANNING


**No external hardware required. Uses the on-board LED**

## Quick Start (Pre-Built Bitstream)

1. Connect your Shrike board via USB
2. Upload `bitstream/led_reaction_timer.bin` using ShrikeFlash
3. Expected result: Watch the onboard LED and press Enter the moment the LED lights up. The terminal prints your reaction time in milliseconds.

## Build From Source

### FPGA (Verilog)
1. Open `lfsr.ffpga` in Go Configure Software Hub (GCSH)
2. Synthesize → Generate Bitstream
3. Output `.bin` will appear in `ffpga/build/` 

## How It Works

- The FPGA runs a **32-bit free-running counter** that increments every clock cycle.
- On a rising edge from the MCU trigger pin, the counter value seeds a **32-bit LFSR** (taps: 31, 21, 1, 0).
> An LFSR work by shifting bits down a line, taking specific bit positions (called taps), XORing them together, and giving feedback to the first bit
- When `i_trigger` is pressed, a rising-edge detector captures the counter's exact state.
- The LFSR output modulo 275,000,000 gives a pseudo-random delay in the range **0–5.5 seconds**.
- The MCU pulses the trigger pin to start each round, waits for the LED signal pin to go high, then timestamps the user's Enter keypress and prints the reaction time in milliseconds.  
- To change the maximum random delay interval from 0 to N *(max ~10s for current RTL)*, you need to modify the modulo threshold value in the RTL. The value is calculated based on your clock frequency using this formula:

Value = Desired Max Delay (seconds) × Clock Frequency (Hz)

- Example: 0 to 3-second interval on the 50MHz clock
1. **Calculate the cycles:** 3 seconds × 50,000,000 Hz = 150,000,000 clock cycles.
2. **Update the RTL:** Since 150,000,000 easily fits inside the 29-bit limit, you change the threshold value directly in the code:

```verilog
// Change 275_000_000 to 150_000_000
r_delay <= r_lfsr[28:0] % 29'd150_000_000;
```

## Expected Output

```bash
Get ready...

Press Enter to REACT:

Reaction time: 312 ms
```
Thonny Shell:

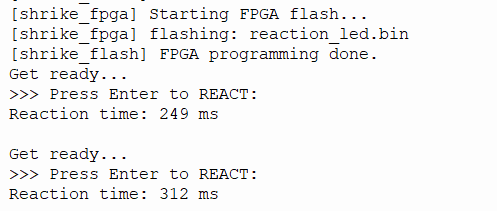
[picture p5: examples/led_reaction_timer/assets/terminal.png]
Terminal


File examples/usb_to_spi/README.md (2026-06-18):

# usb_to_spi

**Difficulty:** Intermediate

**Uses MCU:** Yes

**External Hardware:** Arduino Uno (external SPI slave)

## Overview

This example turns the Shrike board into a **USB-to-SPI bridge**. Bytes typed on
the PC travel over USB to the RP2040, which forwards them over SPI to the FPGA.
The FPGA receives each byte as an SPI *target*, then re-transmits it as an SPI
*master* on a second set of GPIO pins to an external SPI slave (an Arduino Uno).
The slave's reply travels back through the same path to the PC.

You will learn how to bridge two SPI buses inside the FPGA: acting as a **slave**
to the RP2040 on the fixed programming link, and as a **master** to an external
device on free GPIOs.

## Compatibility

| Board | Firmware | Status |
| --- | --- | --- |
| Shrike-Lite (RP2040) | `firmware/micropython/` | ✅ Tested  |
| Shrike (RP2350) | `firmware/micropython/` | ⚪ Untested |
| Shrike-fi (ESP32-S3) | `firmware/micropython/` | ⚪ Untested |

> FPGA bitstream is the same across all boards.

## Hardware Setup

An Arduino Uno is used as the external SPI slave. The Uno is a 5 V device, so the
FPGA's `m_miso` input must be level-shifted from 5 V down to 3.3 V.

### FPGA Connections (link to RP2040 — FPGA is slave)

| FPGA GPIO Pin | Signal Name | Direction | Description |
| --- | --- | --- | --- |
| 3 | `spi_sck` | Input | SPI clock |
| 4 | `spi_ss_n`  | Input | Chip select (active low) |
| 5 | `spi_mosi`  | Input | MOSI (receive) |
| 6 | `spi_miso`  | Output | MISO (transmit) |
| 16 | `led` | Output | LED (shows last byte) |

### FPGA Connections (link to Arduino — FPGA is master)
Here, GPIO8 is a PMOD Connector Pin.
| FPGA GPIO Pin | Signal Name | Direction | Description |
| --- | --- | --- | --- |
| 0 | `m_sck` | Output | SPI clock to slave |
| 1 | `m_mosi` | Output | Master output to slave |
| 7 | `m_ss_n` | Output | Chip select (active low) |
| 8 | `m_miso` | Input | Master input (via divider) |

### RP2040 Connections

| RP2040 Pin | Signal Name | Direction | Description |
| --- | --- | --- | --- |
| 2 | SCK | Output | SPI clock |
| 1 | CS | Output | Chip select |
| 3 | MOSI | Output | Master output |
| 0 | MISO | Input | Master input  |

### Arduino Uno Connections (external slave)

| Arduino Pin | Signal Name | Direction | Connects to FPGA |
| --- | --- | --- | --- |
| D13 | SCK | Input | `m_sck` (GPIO 0) |
| D11 | MOSI | Input | `m_mosi` (GPIO 1) |
| D12 | MISO | Output | `m_miso` (GPIO 8, divider) |
| D10 | SS | Input | `m_ss_n` (GPIO 7) |
| GND | GND | — | Common ground |

### Level Shifting

The Arduino Uno drives MISO at 5 V. Use a resistor divider (e.g. 1.8 kΩ / 3.3 kΩ)
on D12 before it reaches the FPGA `m_miso` pin (GPIO 8) to keep it at 3.3 V.
The FPGA outputs (`m_sck`, `m_mosi`, `m_ss_n`) at 3.3 V are read fine by the Uno.

## Quick Start (Pre-Built Bitstream)

1. Connect the Shrike board via USB.
2. Upload `bitstream/usb_to_spi.bin` to the board using ShrikeFlash.
3. Open `firmware/arduino-ide/usb_to_spi.ino` in the Arduino IDE and upload it to
   the Uno, then open its Serial Monitor at 115200 baud.
4. Open `firmware/micropython/usb_to_spi.py` in Thonny and run it on the RP2040.
5. On the PC, run `firmware/micropython/host.py` (set `PORT` to the RP2040's COM
   port first).
6. Expected result: the bytes sent from the PC appear on the Arduino Serial
   Monitor, confirming the FPGA mastered the SPI bus to the external slave.

> No Arduino on hand? Jumper FPGA GPIO 1 (`m_mosi`) to GPIO 8 (`m_miso`) and run
> `firmware/micropython/loopback_test.py` to verify the master path by loopback.

## Build From Source

### FPGA (Verilog)

1. Open the project in Go Configure Software Hub.
2. Add `top.v`, `spi_target.v`, and `spi_master.v` from `ffpga/src/`.
3. Configure the I/O mapping as listed in the tables above.
4. Generate the bitstream.

### Firmware (MicroPython + Arduino)

1. Open `firmware/micropython/usb_to_spi.py` in Thonny, adjust the pins in
   `CONFIG` if needed, and run it.
2. Open `firmware/arduino-ide/usb_to_spi.ino` in the Arduino IDE and upload it to
   the Uno.

## How It Works

The data path is: **PC USB → RP2040 (SPI master) → FPGA → external slave**, with
the reply returning along the same route. The FPGA forwards each byte and returns
the slave's previous reply, so responses are one transfer behind (send a trailing
dummy byte to flush the last reply).

### 1. `top` Module

* Instantiates `spi_target` (slave to the RP2040) and `spi_master` (master to the
  external slave).
* On each received byte, starts a master transfer to forward it and latches the
  slave's reply to return on the next transfer.
* Generates an internal power-on reset (no external reset pin).
* Mirrors the low bit of the last byte on the LED.

### 2. `spi_target` Module

* Implements the SPI slave: receives on `spi_mosi`, transmits on `spi_miso`.
* Synchronizes `spi_sck` and `spi_ss_n` into the system clock domain.
* Strobes `o_rx_data_valid` for one cycle per received byte.

### 3. `spi_master` Module

* Implements the SPI master: generates `m_sck`, `m_ss_n`, and `m_mosi`.
* Samples a synchronized `m_miso` (2-flop synchronizer) for reliable reads.
* `CLK_DIV` sets the SCK rate from the system clock.

## Top Module Interface

| Signal | Direction | Description |
| --- | --- | --- |
| `clk` | In | System clock (internal oscillator) |
| `clk_en` | Out | Clock enable (always 1) |
| `spi_ss_n` | In | SPI select from RP2040 (active low) |
| `spi_sck` | In | SPI clock from RP2040 |
| `spi_mosi` | In | Input from RP2040 |
| `spi_miso` | Out | Output to RP2040 |
| `m_ss_n` | Out | Chip select to external slave |
| `m_sck` | Out | SPI clock to external slave |
| `m_mosi` | Out | Output to external slave |
| `m_miso` | In | Input from external slave |
| `led` | Out | LED output |

## Expected Output

* Bytes sent from the PC appear on the Arduino Serial Monitor as `Received: 0xNN`.
  This is the observed result and confirms the path PC → RP2040 → FPGA → Arduino,
  with the FPGA acting as SPI master.
* The Arduino also echoes each byte back on MISO. By design this reply propagates
  back through the FPGA to the RP2040 and on to the PC, one transfer behind. The
  return path is demonstrated separately by the `loopback_test.py` jumper test.

This confirms:

* The RP2040 ↔ FPGA SPI link works (FPGA as slave).
* The FPGA ↔ Arduino SPI link works (FPGA as master) — seen on the Serial Monitor.

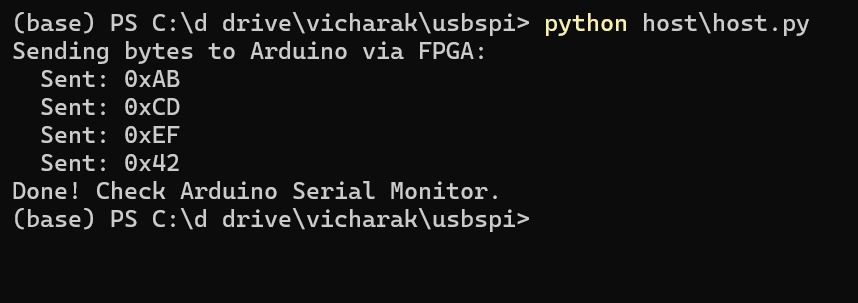
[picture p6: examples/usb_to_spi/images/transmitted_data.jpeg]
Transmitted data


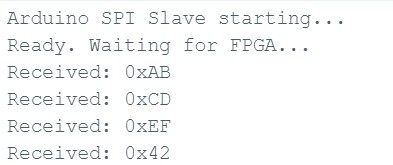
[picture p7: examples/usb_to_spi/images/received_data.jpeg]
Received data


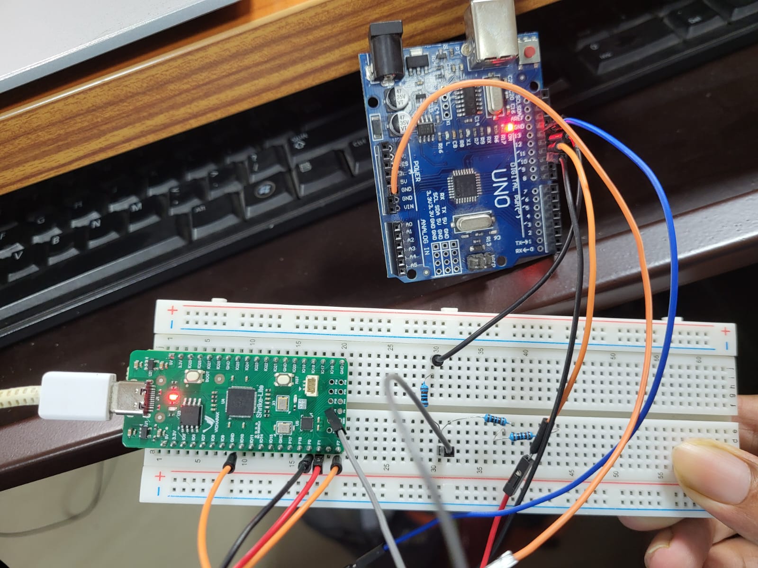
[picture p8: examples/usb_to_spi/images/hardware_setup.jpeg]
Hardware setup


## Notes

* SPI operates in full-duplex mode (simultaneous read/write).
* The bridge is store-and-forward, so replies are one transfer behind.
* The Arduino Uno is 5 V — level-shift the MISO line into the 3.3 V FPGA.

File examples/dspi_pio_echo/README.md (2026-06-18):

# DSPI PIO Echo

**Difficulty:**  
**Uses MCU:** Yes  
**External Hardware:** None  

## Overview

This example demonstrates a custom 10 MHz Dual-SPI (DSPI) protocol implementation on the Shrike platform, utilizing two data lines simultaneously to double standard SPI throughput. It uses the RP2040's Programmable I/O (PIO) to act as the DSPI master, and an oversampled target state machine on the ForgeFPGA that echoes data and generates periodic asynchronous heartbeat alerts.

The project includes two firmware implementations: a flat "logic analyzer" script to view raw clock-by-clock bit transmissions, and a fully encapsulated, object-oriented MicroPython library (`dspi_bus.py`) designed to be dropped into larger projects.

## Compatibility

| Board | Firmware | Status |
|---|---|---|
| Shrike-Lite (RP2040) | `firmware/micropython/` | ✅ Tested |
| Shrike (RP2350) | `firmware/micropython/` | ✅ Tested |
| Shrike-fi (ESP32-S3) | `firmware/micropython/` | ⬜ Untested |

> FPGA bitstream is the same across all boards.

## Hardware Setup

No external hardware required. The configuration utilizes the internal routing between the MCU and the FPGA.

**FPGA Connections:**
* **Pin 3:** `spi_sck` (Input) - SPI clock
* **Pin 4:** `spi_ss_in` (Input) - Chip select (active low)
* **Pin 18:** `dual_io[0]` (Inout) - DSPI Data Line 0
* **Pin 17:** `dual_io[1]` (Inout) - DSPI Data Line 1
* **Pin 16:** `led` (Output) - Status LED (Blinks based on internal heartbeat)

**RP2040 / RP2350 Connections:**
* **GPIO 2:** `SCK` (Output) - SPI clock
* **GPIO 1:** `CS` (Output) - Chip select
* **GPIO 14:** `DSPI_D0` (Inout) - PIO Data Line 0
* **GPIO 15:** `DSPI_D1` (Inout) - PIO Data Line 1

*(Note: The RP2040 PIO requires data pins to be contiguous in the silicon. GPIO 14 and 15 form a contiguous block mapped to the FPGA interconnects).*

## Quick Start (Pre-Built Bitstream)

1. Connect your Shrike board via USB.
2. Upload `bitstream/dspi_pio_echo.bin` using ShrikeFlash.
3. To view raw bit transmissions, run `firmware/micropython/dspi_pio_echo.py` on the MCU.
4. Open the serial monitor and type characters.
5. **Expected result:** The MCU will transmit the characters, and the terminal will print the clock-by-clock dual-bit transmission alongside periodic `0xFF` async alerts.

## Build From Source

### FPGA (Verilog)
1. Open `ffpga/dspi_pio_echo.ffpga` in Go Configure Software Hub.
2. Click Synthesize → Generate Bitstream.
3. Output will be in `ffpga/build/`.

### Firmware (MicroPython)
1. Open `firmware/micropython/` in Thonny.
2. Ensure you have flashed the compiled bitstream.
3. Run either `dspi_pio_echo.py` (for the analyzer view) or `main.py` (to test the OOP library).

## How It Works

This project bypasses standard SPI hardware limits by utilizing the **RP2040 PIO State Machine** (`@rp2.asm_pio`). The PIO uses `out(pins, 2)` and `in_(pins, 2)` instructions to shift two bits per clock cycle. On the FPGA side, a 3-stage synchronizer (`sck_sync`, `cs_sync`) driven by the ForgeFPGA's internal 50 MHz clock oversamples the 10 MHz SPI clock to safely shift data in and out, while toggling a bus turnaround phase to prevent short circuits on the bidirectional lines.

### Using the `DSPI` Library in Your Projects
If you want to use this high-speed bus in your own code, upload `dspi_bus.py` to your MCU. You can initialize the bus and trigger a standard data transfer using the `transfer()` method, which automatically handles strings, bytearrays, and integer lists:

```python
from dspi_bus import DSPI

# Initialize the bus on default pins
fpga_bus = DSPI()

# Send data and receive the echo
rx_data = fpga_bus.transfer("hello")
print([hex(b) for b in rx_data])

# Check for async alerts from the FPGA
if fpga_bus.has_alert():
    print("FPGA requested attention!")

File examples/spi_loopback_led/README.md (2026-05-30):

# spi_loopback_led

**Difficulty:** Intermediate

**Uses MCU:** Yes

**External Hardware:** None

## Overview

This example demonstrates controlling the onboard LED on Shrike using SPI commands from the RP2040 (or any SPI master). It also implements a loopback mechanism where data sent from the MCU to the FPGA is returned back to the MCU.

You will learn how to implement an SPI target (slave) in FPGA and perform bidirectional communication using SPI.

## Compatibility

| Board | Firmware | Status |
| --- | --- | --- |
| Shrike-Lite (RP2040) | `firmware/micropython/` | ✅ Tested |
| Shrike (RP2350) | `firmware/micropython/` | ✅ Tested |
| Shrike-fi (ESP32-S3) | `firmware/micropython/` | ✅ Tested |

> FPGA bitstream is the same across all boards.

## Hardware Setup

No external hardware required.

### FPGA Connections

| FPGA GPIO Pin | Signal Name | Direction | Description |
| --- | --- | --- | --- |
| 3 | `spi_sck` | Input | SPI clock |
| 4 | `spi_ss_n`  | Input | Chip select (active low) |
| 5 | `spi_mosi`  | Input | MOSI (receive) |
| 6 | `spi_miso`  | Output | MISO (transmit) |
| 18 | `rst_n` | Input | Reset (active low) |
| 16 | `led` | Output | LED state |

### RP2040 Connections

| RP2040 Pin | Signal Name | Direction | Description |
| --- | --- | --- | --- |
| 2 | SCK | Output | SPI clock |
| 1 | CS | Output | Chip select |
| 3 | MOSI | Output | Master output |
| 0 | MISO | Input | Master input |
| 14 | Reset | Output | Reset signal (active low) |

### ESP32 S3 Connections

| ESP32 Pin | Signal Name | Direction | Description |
| --- | --- | --- | --- |
| 12 | SCK | Output | SPI clock |
| 10 | CS | Output | Chip select |
| 11 | MOSI | Output | Master output |
| 13 | MISO | Input | Master input |
| 14 | Reset | Output | Reset signal (active low) |

> Ensure pin mapping in FPGA constraints matches firmware configuration.

---

## Quick Start (Pre-Built Bitstream)

1. Connect Shrike board via USB
2. Upload `bitstream/spi_loopback_led.bin` using ShrikeFlash
3. Run `spi_led.py` on RP2040
4. Expected result:

   * Sending `0xAB` → LED turns ON
   * Sending `0xFF` → LED turns OFF
   * Data sent is looped back to MCU

---

## Build From Source

### FPGA (Verilog)

1. Open project in Go Configure Software Hub
2. Paste Verilog for `top` and `spi_target` modules
3. Configure I/O mapping
4. Generate bitstream

### Firmware (MicroPython)

1. Open `spi_led.py` in Thonny
2. Configure SPI pins
3. Run script to send/receive data

---

## How It Works

The design consists of two main modules:

### 1. `top` Module

* Controls LED based on received SPI data
* Implements loopback functionality
* Instantiates SPI target module

Behavior:

* `0xAB` → LED ON
* `0xFF` → LED OFF
* Transmits previously received byte back via SPI

---

### 2. `spi_target` Module

* Implements SPI slave (target) logic
* Handles:

  * Data reception via MOSI
  * Data transmission via MISO
  * Clock synchronization using `spi_sck`
  * Chip select handling using `spi_ss_n`

---

## Top Module Interface

| Signal | Direction | Description |
| --- | --- | --- |
| `clk` | In | System clock (50 MHz typical) |
| `clk_en` | Out | Clock enable (always 1) |
| `rst_n` | In | Reset (active low) |
| `led` | Out | LED output |
| `spi_ss_n` | In | SPI select (active low) |
| `spi_sck`  | In | SPI clock |
| `spi_mosi` | In | Input from controller |
| `spi_miso` | Out | Output to controller |

---

## Expected Output

* Sending `0xAB` → LED turns ON
* Sending `0xFF` → LED turns OFF
* Data sent from RP2040 is echoed back (loopback)

This confirms:

* SPI communication is working
* FPGA correctly processes and returns data

---

## Notes

* SPI operates in full-duplex mode (simultaneous read/write)
* Loopback helps verify communication integrity
* Ensure correct reset handling before communication

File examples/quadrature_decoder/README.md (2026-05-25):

# quadrature_decoder

**Difficulty:** Intermediate

**Uses MCU:** Yes

**External Hardware:** Incremental Quadrature Encoder (Optional)

---

## Overview
A quadrature decoder is used to determine the `position`, `direction` and `speed` of rotational motion from incremental rotary encoders. Quadrature encoders generate two digital signals `(A and B)` that are phase shifted by 90 degrees. By observing the sequence of transitions between these two signals, the FPGA can identify whether the shaft is rotating in the forward or reverse direction while also counting encoder steps.

This project implements a fully digital quadrature decoder inside the FPGA on the Shrike-Lite board. The FPGA continuously monitors encoder transitions, updates the position count, calculates rotational speed over a configurable time window, and computes the angular position based on encoder counts per revolution (CPR). The processed data is packetized and transmitted to the RP2040 over UART, where it is decoded and displayed on the serial monitor.

#### The FPGA:

* Decodes quadrature encoder A/B signals
* Detects rotation direction
* Calculates position count
* Calculates rotational speed
* Tracks angular position
* Sends decoded data to RP2040 using UART packets

#### The RP2040 firmware:

* Receives UART packets from FPGA
* Decodes signed and unsigned data
* Converts encoder counts to degrees
* Prints readable logs over Serial Monitor

> The project also includes an optional internal encoder signal generator implemented on the RP2040 side. This allows users to test the FPGA design even without a physical rotary encoder connected to the board.
---

## Compatibility

| Board | Firmware | Status |
| --- | --- | --- |
| Shrike-Lite (RP2040) | `firmware/arduino-ide/` | ✅ Tested |
| Shrike (RP2350) | `firmware/arduino-ide/` | ⬜ Untested |
| Shrike-fi (ESP32-S3) | `firmware/arduino-ide/` | ⬜ Untested |

> FPGA bitstream is the same across all boards.

---

## Hardware Setup

### Block Diagram

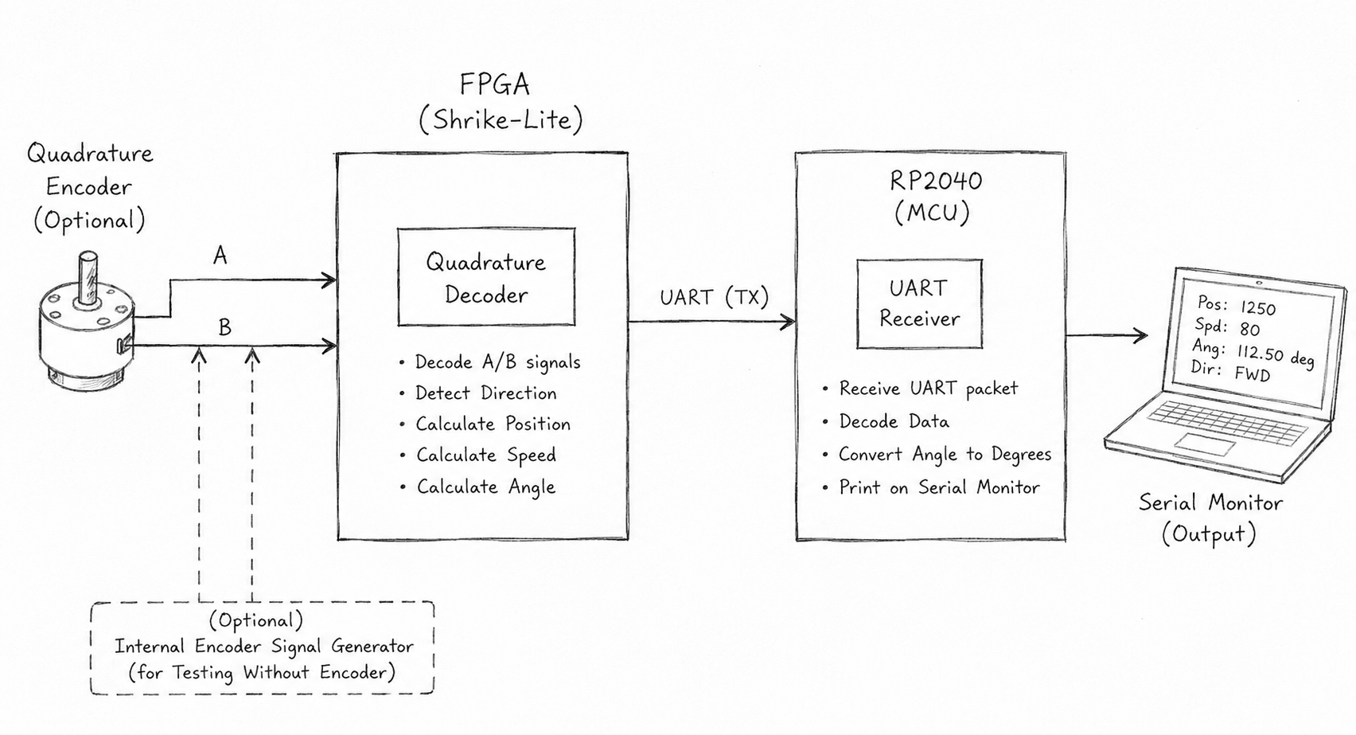
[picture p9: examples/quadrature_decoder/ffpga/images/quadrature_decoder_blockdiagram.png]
ShrikeLite Quadrature Decoder block diagram Block diagram


---

## Pin Usage

### 1. External Encoder Connection

| FPGA Pin | Signal Name | Direction | Description |
| --- | --- | --- | --- |
| F1 | enc_a | Input | Encoder Channel A |
| F2 | enc_b | Input | Encoder Channel B |
| F4 | uart_tx | Output | UART output from FPGA |

---

### 2. MCU Interconnect

| Pin | Signal Name | Direction | Description |
| --- | --- | --- | --- |
| GPIO1 | UART_RX | input | FPGA UART Tx to RP2040 UART RX  |

> GPIO4 (F4 - Tx) pin of FPGA is internally connected with GPIO(Rx) pin of RP2040 through UART. Make sure this mapping should be correct while defining. 

---

## Quick Start (Pre-Built Bitstream)

1. Connect encoder to FPGA inputs
2. Upload `bitstream/quadrature_decoder.bin` using ShrikeFlash
3. Upload Arduino firmware
4. Open Serial Monitor
5. Rotate encoder and observe logs over serial monitor

---

## Build From Source

### FPGA (Verilog)

1. Open project in Go Configure Software Hub
2. Add all Verilog modules
3. Configure parameters
4. Generate bitstream

### Firmware (Arduino)

1. Open `quadrature_decoder.ino`
2. Upload to RP2040
3. Open Serial Monitor

---

## How It Works

### FPGA Modules

### 1. `quad_dec`

Responsible for:

* Synchronizing encoder inputs
* Detecting quadrature transitions
* Determining rotation direction
* Updating position count
* Calculating rotational speed
* Tracking angular count

---

### 2. `uart_tx`

Responsible for:

* UART serial transmission
* Sending bytes serially (LSB first)
* Generating UART start and stop bits

---

### 3. `uart_packetizer`

Responsible for:

* Packing FPGA data into UART frames
* Sending:
  * Position
  * Speed
  * Angle
  * Direction

Packet format:

```text
[AA][pos MSB][pos LSB][spd MSB][spd LSB][ang MSB][ang LSB][dir]
```

Direction encoding:

```text
dir[0] = 1 → Forward
dir[0] = 0 → Reverse
```

---

### 4. `top`

Top-level integration module that:

* Instantiates:
  * `quad_dec`
  * `uart_tx`
  * `uart_packetizer`
* Connects encoder inputs
* Routes UART output
* Interfaces FPGA with RP2040

---

## Features

* Full quadrature decoding
* Direction detection
* Signed position tracking
* Signed speed calculation
* Angle calculation using CPR
* UART packet communication
* Configurable update interval
* Optional internal encoder signal generator
* Works without physical encoder for testing

---

## UART Packet Format

The FPGA sends UART packets in the following format:

| Byte Index | Data | Description |
| --- | --- | --- |
| 0 | `0xAA` | Header |
| 1 | Position MSB | Signed position |
| 2 | Position LSB | Signed position |
| 3 | Speed MSB | Signed speed |
| 4 | Speed LSB | Signed speed |
| 5 | Angle MSB | Encoder angle count |
| 6 | Angle LSB | Encoder angle count |
| 7 | Direction | `1=FWD`, `0=REV` |

---

## Position, Speed and Angle Explanation

### Position

Position represents the accumulated encoder counts.

* Forward rotation increases count
* Reverse rotation decreases count

Example:

```text
0 → 1 → 2 → 3 → ...
```

Reverse:

```text
3 → 2 → 1 → 0 → -1 ...
```

Position is stored as signed 16-bit data.

---

### Speed

Speed is calculated based on encoder steps detected within a configurable update window.

Units:

```text
counts/sec
```

Examples:

| Speed Value | Meaning |
| --- | --- |
| `+10` | Forward rotation |
| `-10` | Reverse rotation |
| `0` | Encoder stopped/ Same position |

---

### Angle

Angle is derived using encoder CPR (Counts Per Revolution).

Formula:

```text
Angle (degrees) = (encoder_count × 360) / CPR
```

For this project:

```text
CPR = 4000
```

Meaning:

* 4000 counts = 360°
* 2000 counts = 180°
* 1000 counts = 90°

---

## Top Module Interface

| Signal | Direction | Description |
| --- | --- | --- |
| `clk` | In | System clock (50 MHz) |
| `enc_a` | In | Encoder channel A |
| `enc_b` | In | Encoder channel B |
| `uart_tx`  | Out | UART transmit output  |
| `uart_tx_en`  | Out | Always High  |
| `clk_en`  | Out | Always High  |

---

## Parameters Used

### `WIDTH`

```verilog
parameter WIDTH = 16
```

Bit width for position, speed and angle.

---

### `CLK_FREQ`

```verilog
parameter CLK_FREQ = 50_000_000
```

System clock frequency.

---

### `UPDATE_MS`

```verilog
parameter UPDATE_MS = 500
```

Speed update interval in milliseconds.

---

### `CPR`

```verilog
parameter CPR = 4000
```

Counts per revolution.

For quadrature decoding:

```text
CPR = Encoder_PPR × 4
```

Example:

```text
1000 PPR encoder → 4000 CPR
```

---

## Firmware Overview

### `quadrature_decoder.ino`

Responsible for:

* Flashing FPGA bitstream
* Receiving UART packets
* Decoding signed/unsigned data
* Converting counts to degrees
* Printing readable serial logs

---

## Internal Encoder Test Mode

The firmware supports optional internal encoder signal generation.

Enable:

```cpp
#define USE_INTERNAL_ENCODER_TEST 1
```

Disable:

```cpp
#define USE_INTERNAL_ENCODER_TEST 0
```

When enabled:

* RP2040 GPIO17 → Encoder A
* RP2040 GPIO18 → Encoder B

The firmware generates quadrature patterns automatically.

---

## Quadrature Patterns

### Forward Rotation

```text
00 → 01 → 11 → 10 → repeat
```

### Reverse Rotation

```text
00 → 10 → 11 → 01 → repeat
```

The FPGA determines direction by observing transition order.

---

## Quick Steps (Arduino IDE)

1. Connect Shrike board via USB
2. Open Arduino IDE
3. Open `quadrature_decoder.ino`
4. Copy FPGA bitstream into `data/`
5. Upload filesystem using LittleFS uploader
6. Upload Arduino sketch
7. Open Serial Monitor at `115200`
8. Rotate encoder and observe logs

---

## Output over Serial Monitor

* Position changes continuously with rotation
* Speed indicates movement direction and rate
* Angle tracks shaft position
* Direction displays Forward/Reverse

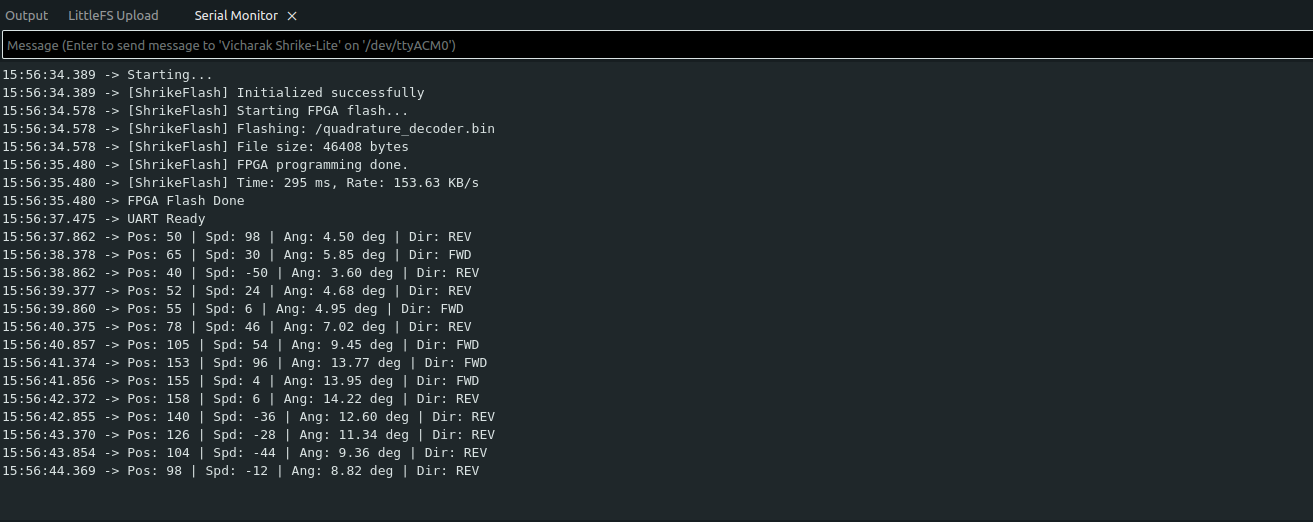
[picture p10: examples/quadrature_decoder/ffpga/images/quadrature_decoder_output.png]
ShrikeLite Quadrature Decoder output output diagram


---

## Notes

* UART transmission uses:
  * 115200 baud
  * 8 data bits
  * No parity
  * 1 stop bit

* FPGA sends UART bits LSB first internally
* Packet bytes are transmitted MSB first

* Position and speed are signed values
* Angle is unsigned

  ---

  ## References

* [Incremental Encoder - Wikipedia](https://en.wikipedia.org/wiki/Incremental_encoder)

* [Infineon Quadrature Decoder Documentation](https://www.infineon.com/assets/row/public/documents/cross-divisions/396/infineon-quadrature-decoder-quaddec-component-quaddec-v2.30-software-module-datasheets-en.pd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)

* [FPGA4Fun - Quadrature Decoder](https://www.fpga4fun.com/QuadratureDecoder.html)

* [ Shrike pinouts]( https://github.com/vicharak-in/shrike/blob/main/docs/shrike_pinouts.md
)

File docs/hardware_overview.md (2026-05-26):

(hardware_overview)=

# Shrike - Hardware Overview

Shrike is a family low-cost, low-power, and easy-to-use FPGA development board that combines both the Renesas FPGA and microcontroller. It is designed for hobbyists, students, and professionals to explore and prototype FPGA-based designs with ease.

The board features a variety of peripherals to support various applications. Some of the key features include:

::::{tab-set}
:::{tab-item} Shrike/Shrike-lite

## Hardware Features

- Renesas FPGA with 1120 5 Input LUT's  
- MCU - RP2350/RP2040  
- PMOD Connector  
- Reset Button  
- Boot Select Button  
- USB Type C for Power & Programming  
- MCU User LED  
- FPGA User LED  
- 23 MCU GPIO  
- 14 FPGA GPIO's  
- 6 Bit FPGA MCU Link  
- Bread Board Compatible  

---

## GPIO's

The Shrike Packed with User IO's I have 23 MCU IO's and 14 FPGA IO's all of which are 3.3V compatible.

The Board also has Header for 3.3V and 5V Power Rails for powering external peripherals.

---

## PMOD Connector

The Shrike Board has a PMOD connector for connecting to various peripherals, the PMOD connector is 3.3 V Compatible

> **Note:** All the pins on shrike are 3.3 V compatible supplying anything more than that will result in damage to IC's on board which are beyond repair.

---

## Type C Port

The Board has a USB type C connector for both programming and power.  
Connect the board to a host PC using a type c cable and you are good to go.

---

## User LED's

The board has two user LED's one for the RP2350/RP2040 and one for the FPGA. The LED's are connected to GPIO pins of the respective chips.  
The RP2350/RP2040 LED is connected to GPIO 04 and the FPGA LED is connected to GPIO 16.

The LED's are active high meaning that when the GPIO pin is set to high the LED will turn on and when the GPIO pin is set to low the LED will turn off.

---

## FLASH

The Shrike Dev Board features a 32Mb/4MB QSPI based Flash memory which is connected to RP2350/RP2040. The part number for which is W25Q32JV. This flash is used to store the fpga bitstream and RP2350/RP2040 firmware.

---

## Programming

Both the IC on the board have separate programming models. The RP2040 can be programmed using MicroPython, Arduino or RPi's C SDK whereas the FPGA needs to be programmed using Verilog in the Renesas Go Configure hub.

---

## Powering the Board

The board can be powered using one of these two methods:

1. The USB Type C port  
2. Header 1 marked 5V and any of the GND pins on the board  

> **Note:** The board can be powered using the USB Type C port or the header marked 5V. Do not power the board using both methods at the same time as this will damage the board.

The voltage on the Type C and header both should be 5V only. The board has a voltage regulator that converts the 5V to 3.3V for the RP2350/RP2040 and the FPGA.

The voltage on the PMOD connector is 3.3V.

:::

:::{tab-item} Shrike-fi

## Hardware Features

- Renesas FPGA with 1120 5 Input LUT's  
- MCU - ESP32S3  
- PMOD Connector  
- Reset Button  
- Boot Select Button  
- USB Type C for Power & Programming  
- MCU User LED  
- FPGA User LED  
- 24 MCU GPIO  
- 14 FPGA GPIO's  
- 4 Bit FPGA MCU Link  
- Bread Board Compatible  

---

## GPIO's

The Shrike-fi Packed with User IO's I have 24 MCU IO's and 14 FPGA IO's all of which are 3.3V compatible.

The Board also has Header for 3.3V and 5V Power Rails for powering external peripherals.

---

## PMOD Connector

The Shrike-fi Board has a PMOD connector for connecting to various peripherals, the PMOD connector is 3.3 V Compatible

> **Note:** All the pins on Shrike-fi are 3.3 V compatible supplying anything more than that will result in damage to IC's on board which are beyond repair.

---

## Type C Port

The Board has two USB type C connector for programming and power.  
Connect the board to a host PC using a type c cable and you are good to go.

---

## User LED's

The board has two user LED's one for the ESP32S3 and one for the FPGA. The LED's are connected to GPIO pins of the respective chips.  
The ESP32S3 LED is connected to GPIO 21 and the FPGA LED is connected to GPIO 16.

The LED's are active high meaning that when the GPIO pin is set to high the LED will turn on and when the GPIO pin is set to low the LED will turn off.

---

## WiFi and BLE

The Shrike-fi dev board with ESP32S3 supports 2.4 GHz, 802.11 b/g/n Wi-Fi 4 and Bluetooth 5 (LE).
These are on-chip features of ESP32S3.

## FLASH

The Shrike Dev Board features a 32Mb/4MB QSPI based Flash memory which is connected to ESP32S3. The part number for which is W25Q32JV. This flash is used to store the fpga bitstream and firmware.

The board also has optional 8MB PSRAM in the ESP32S3.

---

##  Optional Add-On

The Shrike-fi Dev also has two optional add on's hardware features. 

### 1. PSRAM

Shrike-fi can be equipped with an optional 8 MB PSRAM. Depending on the variant purchased, the PSRAM may come pre-soldered or left unpopulated. If you choose to buy without it soldered, you can add it later. The part number is **LY68L6400SLIT**, and the designator is **U10**.

### 2. Batter Management System  

Shrike-fi features an onboard battery management and charging circuit. However, in the base version, these parts are designated as do not place (DNP). A future version with these components pre-soldered will be available soon.

In the meantime, we are providing the necessary details for all the parts if you wish to solder them yourself. 

The complete BOM for the BMS and charging circuit is available in the table below. 

| Designator | Description | Value | Manufacturer Part Number | Case/Package | Quantity | Type |
|---|---|---|---|---|---|---|
| C9 | 100nF, 10V, X7R, ±10%, 0402, MLCC | 100nF | CC0402KRX7R6BB104 |0402 | 1 | Capacitor  |
| C10, C11, C12 | 10uF, 10V, X5R, ±10%, 0603, MLCC | 10uF | CL10A106KP8NNNC | 0603 | 3 | Capacitor  |
| D9 | LED ORANGE 0603 | ORANGE LED| XL-1608UOC-06 |0603 | 1 | LED |
| D10 | GREEN LED (LED) | GREEN LED | XL-1608UGC-04 |0603 | 1 | LED |
| J3 | 2P 1x2P 2.5mm 2.2A 1 Right Angle Through Hole ,P=2.5mm Headers| — | XY-XHB2.54-2A21 |  TH, P=2.5mm |  1 | Connector  |
| R5 | Resistor - 100 ohm, 1%, 0402 | 100R | RC0402FR-07100RL |0402 | 1 | Resistor |
| R6, R7, R11, R12 | Resistor - 1 kohm, 1%, 0402 | 1K | RC0402FR-071KL |0402 | 4 | Resistor |
| R8 | 402Ohm, ±1%, 62.5mW, 0402, Chip Resistor | 402R | 0402WGF4020TCE |0402 | 1 | Resistor |
| R9 | Resistor - 0 ohm, 1%, 0402 | 0R | RC0402FR-070RL |0402 | 1 | Resistor |
| R10 | 0Ohm,125mW, ±1%, 0805, Resistor | 0R | 0805W8F0000T5E | 0805 | 1 | Resistor |
| U2 | Lithium Battery protection IC, SOT23-6 (4911) (DW01A) (C436931) | DW01A | DW01A |SOT23-6 | 1 | IC |
| U3 | POWER SWITCH IC [TPS2113ADRBR] (C354512) | — | TPS2113ADRBR | VSON-8 | 1 | IC |
| U4 | Lithium Battery Charger, 1A, 5V, (3656) [TP4056] (SOP8) | — | TP4056 | SOP8 | 1 | IC |
| U5 | Dual N-Channel -20V 6A 1V @ 250uA [FS8205A] | — | FS8205A | TSSOP-8 | 1 | IC |

---

#### Part Designators 

The complete out and pcb file's aren't open for Shrike-fi yet they will be open mid june. However to solder the above mentionded parts you can use this part Designators file available [here](./images/Shrike_fi_designator.pdf).

---

> **Note:** Both of these add-ons are not placed in the base version of Shrike-fi. We will launch a board with these components pre-soldered soon. In the meantime, you can solder them yourself if you want these features.

---

## Programming

Both the IC on the board have separate programming models. The ESP32S3 can be programmed using MicroPython, Arduino or ESP-SDK whereas the FPGA needs to be programmed using Verilog in the Renesas Go Configure hub.

---

## Powering the Board

The board can be powered using one of these two methods:

1. The USB Type C port  
2. Header 1 marked 5V and any of the GND pins on the board  

> **Note:** The board can be powered using the USB Type C port or the header marked 5V. Do not power the board using both methods at the same time as this will damage the board.

The voltage on the Type C and header both should be 5V only. The board has a voltage regulator that converts the 5V to 3.3V for the ESP32S3 and the FPGA.

The voltage on the PMOD connector is 3.3V.

:::
::::

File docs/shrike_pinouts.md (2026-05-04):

(shrike_pinouts)=

# Shrike Dev Board Pin Outs 

::::{tab-set}
:::{tab-item} Shrike/Shrike-lite

<div align="center">

 shrike

</div>

## FPGA RP2040/RP2350 Communication Pin-outs

To make communication between RP2040/RP2350 and FPGA simple we have connected a 6 bit IO bus on the PCB . 
Its actually a 8 bit bus however 2 pin are always pre-occupied with EN and PWR pins these are used to reset and control the initialization of FPGA.

Out of remaining 6 pins, 4 pins are dual purpose which works both as configuration pins ( to program the fpga) and then IO bus. This pins are completely internally routed however test pads are available in the top of the board in case need arises to probe them. 

The remaining 2 pins  FPGA PIN 17 , 18 are both internally connected and routed to IO header , mode of can be configuration by soldering/de-soldering the 0ohm resistor on board (check schematic for details).

In default these resistor are placed and thus these pins are connected to respective RP2040/RP2350 IO (see table below) internally. Thus in this case it is recommended to NOT use them as IO on header even tho they are present. Same goes for RP2040 pin number 14 , 15.

### User LED's 

The Shrike/Shrike-lite has two user LED's one each for FPGA and MCU. The Pin Number for the same are

 * MCU LED - RP2040/RP2350 - GPIO04
 * FPGA                      GPIO16

### FPGA CPU Interconnect Pin-outs 

<div align="center">

| FPGA PIN | RP2350/RP2040 PIN | RP2350/RP2040 | FPGA |
|---|---|---|---|
| EN | 13 | GPIO | EN (Enable) |
| PWR | 12 | GPIO | PWR |
| 3 | 2 | GPIO | SPI_SCLK |
| 4 | 1 | UART RX / GPIO | SPI_SS |
| 5 | 3 | GPIO | SPI_SI (MOSI) |
| 6 | 0 | UART TX / GPIO | SPI_SO (MISO) / CONFIG |
| 18 | 14 | GPIO / I2C 1 SDA | GPIO |
| 17 | 15 | GPIO / I2C 1 SCL | GPIO |
 
</div>

:::

:::{tab-item} Shrike-fi

<div align="center">

 shrike fi pinouts

</div>

## FPGA ESP32 Communication Pin-outs

To make communication between ESP32 and FPGA simple we have connected a 4 bit IO bus on the PCB . 
Its actually a 6 bit bus however 2 pin are always pre-occupied with EN and PWR pins these are used to reset and control the initialization of FPGA.

These 4 pins are dual purpose which works both as configuration pins ( to program the fpga) and then IO bus. This pins are completely internally routed however test pads are available in the top of the board in case need arises to probe them. 

### User LED's 

The Shrike-fi has two user LED's one each for FPGA and MCU. The Pin Number for the same are

 * MCU LED - ESP32S3 - GPIO21
 * FPGA                GPIO16

### FPGA CPU Interconnect Pin-outs 

<div align="center">

| FPGA PIN | ESP32 PIN | ESP32 | FPGA |
|---|---|---|---|
| EN | 9 | GPIO | EN (Enable) |
| PWR | 8 | GPIO | PWR |
| 3 | 12 | GPIO | SPI_SCLK |
| 4 | 10 | GPIO | SPI_SS |
| 5 | 11 | GPIO | SPI_SI (MOSI) |
| 6 | 13 | GPIO | SPI_SO (MISO) / CONFIG |
 
</div>

:::
::::

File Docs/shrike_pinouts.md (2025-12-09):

(shrike_pinouts)=

# Shrike Dev Board Pin Outs 

<div align="center">

 shrike

</div>

## FPGA RP2040 Communication Pin-outs

### FPGA CPU Interconnect Pin-outs 

<div align="center">

| FPGA PIN | RP 2040 PIN | RP2040 | FPGA |
|---|---|---|---|
| EN | 13 | GPIO | EN (Enable) |
| PWR | 12 | GPIO | PWR |
| 3 | 2 | GPIO | SPI_SCLK |
| 4 | 1 | UART RX / GPIO | SPI_SS |
| 5 | 3 | GPIO | SPI_SI (MOSI) |
| 6 | 0 | UART TX / GPIO | SPI_SO (MISO) / CONFIG |
| 18 | 14 | GPIO / I2C 1 SDA | GPIO |
| 17 | 15 | GPIO / I2C 1 SDA | GPIO |
 
</div>

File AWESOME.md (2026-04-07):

# Awesome Shrike 

A curated collection of press coverage, tutorials, blog posts, community projects, and resources for the [Shrike](https://github.com/vicharak-in/shrike) family of FPGA development boards by [Vicharak](https://vicharak.in).

Know something that should be here? [Open a PR](../../pulls) or [post in Discussions](../../discussions)!

---

## Contents

- [Press & Media](#press--media)
- [Blog Posts](#blog-posts)
- [Tutorials](#tutorials)
- [Community Projects](#community-projects)
- [Forum Discussions](#forum-discussions)
- [Ecosystem & Integrations](#ecosystem--integrations)
- [Where to Buy](#where-to-buy)
- [Related Repositories](#related-repositories)
- [Learning Resources](#learning-resources)

---

## Press & Media

| Source | Title | Date | Language |
|---|---|---|---|
| [CNX Software](https://www.cnx-software.com/2025/10/16/4-shrike-lite-fpga-board-renesas-forgefpga-raspberry-pi-rp2040-mcu/) | $4 Shrike-lite FPGA board combines 1120 LUTs ForgeFPGA with RP2040 MCU | Oct 2025 | EN |
| [Hackster.io](https://www.hackster.io/news/the-shrike-lite-combines-an-fpga-and-rp2040-for-just-4-3a399884ec6c) | The SHRIKE-lite Combines an FPGA and RP2040 for Just $4 | Oct 2025 | EN |
| [Hackster.io](https://www.hackster.io/news/vicharak-sets-the-shrike-aflight-promises-low-cost-fpga-development-on-a-renesas-forgefpga-ce431aa2e34e) | Vicharak Sets the Shrike Aflight — Low-Cost FPGA Development on ForgeFPGA | May 2025 | EN |
| [Circuit Digest](https://circuitdigest.com/interview/vicharak-fpga-boards-start-349-rupees-scales-with-skill) | Vicharak's FPGA Boards Start at 349 Rupees and Scale as You Skill Up | Dec 2025 | EN |
| [All About Industries (DE)](https://www.all-about-industries.com/shrike-lite-combines-raspberry-mcu-rp2040-with-renesas-fpga-for-4-us-dollars-a-28e23d6c76f1ce643a01209bd1f3fa76/) | Shrike-Lite: FPGA and a Microcontroller for Only Four US Dollars | Oct 2025 | EN/DE |
| [YourStory](https://yourstory.com/2024/12/tech30-surat-startup-vicharak-pioneering-india-hardware-revolution) | Surat-based Vicharak is Pioneering India's Hardware Revolution | Dec 2024 | EN |

## Blog Posts

Official blog posts from the Vicharak team:

| Title | Author | Date |
|---|---|---|
| [Understanding FPGA Internal Architecture: With Shrike](https://blog.vicharak.in/understanding-fpga-internal-architecture/) | Deepak Sharda | Feb 2026 |
| [Why We Built Shrike Lite: Breaking the Microcontroller Ceiling](https://blog.vicharak.in/why-we-built-shrike-lite-breaking-the-microcontroller-ceiling/) | Vicharak Team | Jan 2026 |
| [Driving WS2812 (NeoPixel) LEDs with the Shrike Lite FPGA Board](https://blog.vicharak.in/driving-ws2812-neopixel-leds-with-the-shrike-lite-fpga-board-a-deep-technical-walkthrough/) | Vicharak Team | Jan 2026 |

## Tutorials

Hands-on guides by the community and third parties:

| Source | Title | Date | Language |
|---|---|---|---|
| [CIRCUITSTATE](https://www.circuitstate.com/tutorials/getting-started-with-vicharak-shrike-lite-rp2040-slg47910-fpga-development-board/) | Getting Started with Vicharak Shrike-Lite RP2040 + SLG47910 FPGA Development Board | Jan 2026 | EN |

> **Want to add your tutorial?** We'd love to feature it. Write about your experience with Shrike and [open a PR](../../pulls) to add it here.

## Community Projects

Projects built by the community using Shrike:

| Project | Author | Description | Language |
|---|---|---|---|
| [shrike_flash Starter](https://github.com/stonedev-app/shrike_flash) | [@stonedev-app](https://github.com/stonedev-app) | LED blink starter project with full Japanese documentation | JP |

> **Built something with Shrike?** Share it in [Discussions → Show & Tell](../../discussions) or [open a PR](../../pulls) to add it here!

## Forum Discussions

Community discussions and debates about Shrike:

| Forum | Thread | Date |
|---|---|---|
| [Raspberry Pi Forums](https://forums.raspberrypi.com/viewtopic.php?t=392925) | $4 RP2040 and FPGA board | Oct 2025 |

## Ecosystem & Integrations

Shrike's presence in the broader open-source ecosystem:

| Platform | Description | Link |
|---|---|---|
| Zephyr RTOS | Community Added not maintained by team for now| [Docs](https://docs.zephyrproject.org/latest/boards/vicharak/shrike_lite/doc/index.html) · [Source](https://github.com/zephyrproject-rtos/zephyr/blob/main/boards/vicharak/shrike_lite/doc/index.rst) |
| Crowd Supply | Shrike (RP2350) crowdfunding campaign page | [Campaign](https://www.crowdsupply.com/vicharak/shrike) |
| Arduino Library Manager | ShrikeFlash — FPGA bitstream flashing library | [GitHub](https://github.com/vicharak-in/shrike_flash) |

## Where to Buy

| Store | Board | Region |
|---|---|---|
| [Vicharak Store](https://store.vicharak.in/?product=shrike) | Shrike-Lite (RP2040) | Worldwide |
| [Crowd Supply](https://www.crowdsupply.com/vicharak/shrike) | Shrike (RP2350) | Worldwide (coming soon) |
| [Robu.in](https://robu.in/product/vicharak-shrike-lite-open-source-mcu-fpga-development-board/) | Shrike-Lite (RP2040) | India |
| [Fab.to" Lab](https://www.fabtolab.com/vicharak-shrike-lite-fpga-1120-5-input-luts-rp2040-arm-cortex-m0-microcontroller) | Shrike-Lite (RP2040) | India |

## Related Repositories

| Repository | Description |
|---|---|
| [vicharak-in/shrike](https://github.com/vicharak-in/shrike) | Main monorepo — examples, docs, hardware, tools |
| [vicharak-in/shrike_arduino](https://github.com/vicharak-in/shrike_arduino) | ShrikeFlash Arduino library for FPGA bitstream flashing |
| [vicharak-in/shrike-lite](https://github.com/vicharak-in/shrike-lite) | Legacy repo (merged into main shrike repo) |
| [vicharak-in/shrike_fpga](https://github.com/vicharak-in/shrike_fpga) | Legacy repo — archived, merged into main shrike repo |

## Learning Resources

Useful references for getting into FPGA development with Shrike:

| Resource | Description |
|---|---|
| [Shrike Documentation](https://vicharak-in.github.io/shrike/) | Official docs — getting started, pinouts, examples, style guide |
| [Renesas SLG47910 Datasheet](https://www.renesas.com/en/products/slg47910#overview) | ForgeFPGA datasheet — LUT architecture, GPIO, PLL, timing |
| [Go Configure Software Hub](https://www.renesas.com/en/software-tool/go-configure-software-hub) | FPGA synthesis tool from Renesas (free) |
| [RP2040 Getting Started](https://www.raspberrypi.com/documentation/microcontrollers/pico-series.html) | Raspberry Pi Pico / RP2040 documentation |
| [Platform-Agnostic Firmware Guide](docs/platform_agnostic_guide.md) | How to write firmware that runs on all Shrike boards |

---

## Social

Follow Shrike development and join the community:

- [Discord](https://discord.com/invite/EhQy97CQ9G)
- [Twitter/X — @Vicharak_In](https://x.com/Vicharak_In)
- [LinkedIn — Vicharak](https://www.linkedin.com/company/vicharak-in)
- [Reddit — r/Vicharak](https://www.reddit.com/r/Vicharak/)
- [Forum — discuss.vicharak.in](https://discuss.vicharak.in/)

---

*This list is maintained by the Shrike community team. Last updated: April 2026.*

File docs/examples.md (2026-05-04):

(examples)=

# Shrike Examples

🟢 Beginner &nbsp;&nbsp; 🟡 Intermediate &nbsp;&nbsp; 🔴 Advanced

| # | Example | Folder Name | Category | Difficulty | Why |
|---|---|---|---|---|-----|
| 1 | [LED Blink](https://github.com/vicharak-in/shrike/tree/main/examples/led_blink) | `led_blink` | Getting Started | 🟢 Beginner | Single output signal, no state |
| 2 | [Breathing LED](https://github.com/vicharak-in/shrike/tree/main/examples/breathing_led) | `breathing_led` | Getting Started | 🟢 Beginner | Simple PWM counter, single module |
| 3 | [Button Debouncer](https://github.com/vicharak-in/shrike/tree/main/examples/button_debouncer) | `button_debouncer` | Getting Started | 🟢 Beginner | Basic FSM, introduces synchronous logic |
| 4 | [LED PMOD](https://github.com/vicharak-in/shrike/tree/main/examples/pmod_led_blink) | `pmod_led_blink` | GPIO & I/O | 🟢 Beginner | Direct pin drive, PMOD pinout awareness |
| 5 | [Logic Gates](https://github.com/vicharak-in/shrike/tree/main/examples/logic_gates) | `logic_gates` | Digital Logic | 🟢 Beginner | Pure combinational, no clock needed |
| 6 | [4-Bit Counter](https://github.com/vicharak-in/shrike/tree/main/examples/counter_4bit) | `counter_4bit` | Signal & Timing | 🟢 Beginner | Sequential logic, introduces registers |
| 7 | [PMOD Patterns](https://github.com/vicharak-in/shrike/tree/main/examples/pmod_patterns) | `pmod_patterns` | GPIO & I/O | 🟡 Intermediate | Sequenced output, simple state machine |
| 8 | [GPIO Extender 8-Pin](https://github.com/vicharak-in/shrike/tree/main/examples/gpio_extender_8pin) | `gpio_extender_8pin` | GPIO & I/O | 🟡 Intermediate | FPGA-to-RP2040 IO bridge, bus awareness |
| 9 | [GPIO Extender 14-Pin](https://github.com/vicharak-in/shrike/tree/main/examples/gpio_extender_14pin) | `gpio_extender_14pin` | GPIO & I/O | 🟡 Intermediate | FPGA-to-RP2040 IO bridge, wider bus |
| 10 | [I2C LED](https://github.com/vicharak-in/shrike/tree/main/examples/i2c_led) | `i2c_led` | Communication Protocols | 🟡 Intermediate | I2C state machine, clock stretching awareness |
| 11 | [SPI Loopback LED](https://github.com/vicharak-in/shrike/tree/main/examples/spi_loopback_led) | `spi_loopback_led` | Communication Protocols | 🟡 Intermediate | SPI shift register, MISO/MOSI routing |
| 12 | [UART LED](https://github.com/vicharak-in/shrike/tree/main/examples/uart_led) | `uart_led` | Communication Protocols | 🟡 Intermediate | UART RX framing, baud clock generation |
| 13 | [Morse Blink](https://github.com/vicharak-in/shrike/tree/main/examples/morse_blink) | `morse_blink` | Communication Protocols | 🟡 Intermediate | UART input, timing/state machine, serial-to-LED translation |
| 14 | [UART ALU](https://github.com/vicharak-in/shrike/tree/main/examples/uart_alu) | `uart_alu` | Communication Protocols | 🟡 Intermediate | UART + datapath, multi-module design |
| 15 | [PLL Oscillator](https://github.com/vicharak-in/shrike/tree/main/examples/pll_oscillator) | `pll_oscillator` | Signal & Timing | 🟡 Intermediate | PLL primitive instantiation, clock domain |
| 16 | [PWM 4-Channel](https://github.com/vicharak-in/shrike/tree/main/examples/pwm_4ch) | `pwm_4ch` | Signal & Timing | 🟡 Intermediate | Multi-channel counter, duty cycle control |
| 17 | [7-Segment Display Clock](https://github.com/vicharak-in/shrike/tree/main/examples/seven_seg_clock) | `seven_seg_clock` | Signal & Timing | 🟡 Intermediate | BCD conversion, multiplexed display drive |
| 18 | [Ultrasonic Sensor](https://github.com/vicharak-in/shrike/tree/main/examples/ultrasonic_sensor) | `ultrasonic_sensor` | Sensors & Peripherals | 🟡 Intermediate | Pulse timing, echo measurement FSM |
| 19 | [WS2812 LED](https://github.com/vicharak-in/shrike/tree/main/examples/ws2812_led) | `ws2812_led` | Sensors & Peripherals | 🟡 Intermediate | Precise bit-bang timing, serial protocol |
| 20 | [ASK Modulator](https://github.com/vicharak-in/shrike/tree/main/examples/ask_modulator) | `ask_modulator` | Signal & Timing | 🔴 Advanced | RF modulation concepts, carrier + data mixing |
| 21 | [Stack Processor](https://github.com/vicharak-in/shrike/tree/main/examples/stack_processor) | `stack_processor` | Processors & CPUs | 🔴 Advanced | Custom ISA, stack-based execution, SPI host |
| 22 | [Vector-4 CPU](https://github.com/vicharak-in/shrike/tree/main/examples/vector4_cpu) | `vector4_cpu` | Processors & CPUs | 🔴 Advanced | Full 4-bit SAP CPU: ALU, PC, registers, decode |
| 23 | [Vector-8 CPU](https://github.com/vicharak-in/shrike/tree/main/examples/vector8_cpu) | `vector8_cpu` | Processors & CPUs | 🔴 Advanced | Full 8-bit SAP CPU: wider datapath, more opcodes |

---

## Summary by Difficulty

| Difficulty | Count | Examples |
|---|---|---|
| 🟢 Beginner | 6 | [`led_blink`](https://github.com/vicharak-in/shrike/tree/main/examples/led_blink), [`breathing_led`](https://github.com/vicharak-in/shrike/tree/main/examples/breathing_led), [`button_debouncer`](https://github.com/vicharak-in/shrike/tree/main/examples/button_debouncer), [`pmod_led_blink`](https://github.com/vicharak-in/shrike/tree/main/examples/pmod_led_blink), [`logic_gates`](https://github.com/vicharak-in/shrike/tree/main/examples/logic_gates), [`counter_4bit`](https://github.com/vicharak-in/shrike/tree/main/examples/counter_4bit) |
| 🟡 Intermediate | 13 | [`pmod_patterns`](https://github.com/vicharak-in/shrike/tree/main/examples/pmod_patterns), [`gpio_extender_8pin`](https://github.com/vicharak-in/shrike/tree/main/examples/gpio_extender_8pin), [`gpio_extender_14pin`](https://github.com/vicharak-in/shrike/tree/main/examples/gpio_extender_14pin), [`i2c_led`](https://github.com/vicharak-in/shrike/tree/main/examples/i2c_led), [`spi_loopback_led`](https://github.com/vicharak-in/shrike/tree/main/examples/spi_loopback_led), [`uart_led`](https://github.com/vicharak-in/shrike/tree/main/examples/uart_led), [`morse_blink`](https://github.com/vicharak-in/shrike/tree/main/examples/morse_blink), [`uart_alu`](https://github.com/vicharak-in/shrike/tree/main/examples/uart_alu), [`pll_oscillator`](https://github.com/vicharak-in/shrike/tree/main/examples/pll_oscillator), [`pwm_4ch`](https://github.com/vicharak-in/shrike/tree/main/examples/pwm_4ch), [`seven_seg_clock`](https://github.com/vicharak-in/shrike/tree/main/examples/seven_seg_clock), [`ultrasonic_sensor`](https://github.com/vicharak-in/shrike/tree/main/examples/ultrasonic_sensor), [`ws2812_led`](https://github.com/vicharak-in/shrike/tree/main/examples/ws2812_led) |
| 🔴 Advanced | 4 | [`ask_modulator`](https://github.com/vicharak-in/shrike/tree/main/examples/ask_modulator), [`stack_processor`](https://github.com/vicharak-in/shrike/tree/main/examples/stack_processor), [`vector4_cpu`](https://github.com/vicharak-in/shrike/tree/main/examples/vector4_cpu), [`vector8_cpu`](https://github.com/vicharak-in/shrike/tree/main/examples/vector8_cpu) |

---

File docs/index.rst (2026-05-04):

.. _shrike-home:

..
   Vicharak master file, created by
   sphinx-quickstart on Tue May  9 19:32:34 2023.
   You can adapt this file completely to your liking, but it should at least
   contain the root `toctree` directive.

.. rst-class:: lead

##############################################
 Welcome to Shrike documentation!
##############################################

Shrike is a family of low cost affordable FPGA development board along with a host microcontroller. 
Currently the family features these three members -: 

1. Shrike-lite (FPGA with RP2040) 
2. Shrike      (FPGA with RP2350)
3. Shrike-fi   (FPGA with ESP32-S3)
 
And a lot version under development.

We at vicharak have kept in mind need of a learner, maker and a hobbyist while designing this art. This dev board will be your stepping stone in the field of FPGA , reconfigurable and heterogenous computing.



.. toctree::
   :glob:
   :caption: Contents
   :titlesonly:

   Introduction <introduction>
   Hardware Overview <hardware_overview>
   Getting Started <getting_started> 
   Tools Setup <tools_setup_guide>
   Generating Bitstream <generating_your_first_bitstream>
   Verilog Style Guide <verilog_style_guide>      
   Shrike Pinouts <shrike_pinouts>
   Shrike CLI Guide <shrike_cli_guide>
   Examples <examples>
   Reading List <reading_list>

.. note::

   We welcome contributions and bug reports through our `GitHub
   repository <https://github.com/vicharak-in/shrike>`_.

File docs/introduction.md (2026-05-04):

(introduction)=

# Introduction to Shrike Project 

Hello! So you’ve got the **Shrike** - nice!

Before we explain how programming works on Shrike, it’s important to understand what Shrike actually is and how it differs from all kind of other embedded development boards. 

These points will give you the right foundation, especially if you are new to electronics or computing systems. If you already know the basics of microcontroller, FPGAs, and embedded systems, you can skip this introduction and jump directly into the programming section.

Shrike is special because it combines two worlds on a single board: 
 
&emsp;**A Microcontroller (MCU)** — Raspberry Pi’s RP2350/RP2040 (Shrike & Shrike-lite) or ESP32-S3 (Shrike-fi) 

&emsp;**An FPGA (Field-Programmable Gate Array)**

You can write software for the micro-controller and create digital circuits on the FPGA, and then let them work together to build powerful and fun projects. If you’re curious to learn more about FPGAs, you can read about them from resources listed [here](./reading_list.md).

In Shrike, the micro-controller is connected to the FPGA through an SPI bus. The SPI bus is used for two main purposes:

&emsp;1. **Configuring the FPGA** - loading the bitstream into the FPGA via the RP2040/RP2350.

&emsp;2. **Communication** - between the microcontroller and the FPGA.

While your program is running on the micro-controller, you can configure the FPGA at any time to perform specific tasks. Not only that, once the FPGA is programmed, it can also communicate with the MCU back and forth.

The beauty of this setup is that you can reprogram the FPGA an unlimited number of times, and that’s exactly where reconfigurable computing comes to life.

As discussed earlier, we’ll need to learn how compilation works for both systems: the FPGA and the micro-controller .

The binary files that the FPGA understands are called **bitstreams**.  

Follow the guide here to learn how to generate a bitstream for the FPGA: 
 [Generating Your First Bitstream](https://vicharak-in.github.io/shrike/generating_your_first_bitstream.html)

Once you have the bitstream, you’re ready to load it into the FPGA through a microcontroller program.

We’ll start with a simple blink-LED example to say hello to the world of hardware.  

Along the way, we’ll also set up the required software and toolchain.

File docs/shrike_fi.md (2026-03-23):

# Setting Up the Shrike-fi board

To flash the firmware 

1. Get the esptools ( install from pip)
2. `python -m esptool erase_flash`
3. `python -m esptool --chip esp32s3 -b 460800 --before default_reset --after hard_reset write_flash --flash_mode dio --flash_size 4MB --flash_freq 80m 0x0 firmware.bin`

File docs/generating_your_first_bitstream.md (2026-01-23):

(generating_your_first_bitstream)=

# Shrike FPGA Bitstream Generation Guide 

Bitstream is a firmware that is used to programme the FPGA and map our design to it. Shrike uses a Renesas Forge FPGA SLGV SLG47910 1K Luts FPGA.The datasheet fr which can be found [here](https://www.renesas.com/en/products/slg47910) .

For generating the bitstream for shrike we will use these steps. 

  1. Setup 
  2. Design & Synthesis 
  3. IO Mapping and Placement and Routing (PNR)

I am here assuming that you have installed all the tools required if not check tools_setup_guide [HERE](./tools_setup_guide.md).

We will create a LED Blinking Project for this guide and we will start by launching the Go Configure Software Hub.  

### 1. Setup  

1. Launch the GO Configure Software Hub and move to the Forge FPGA tab under the Develop Tab. 

<div align="center">

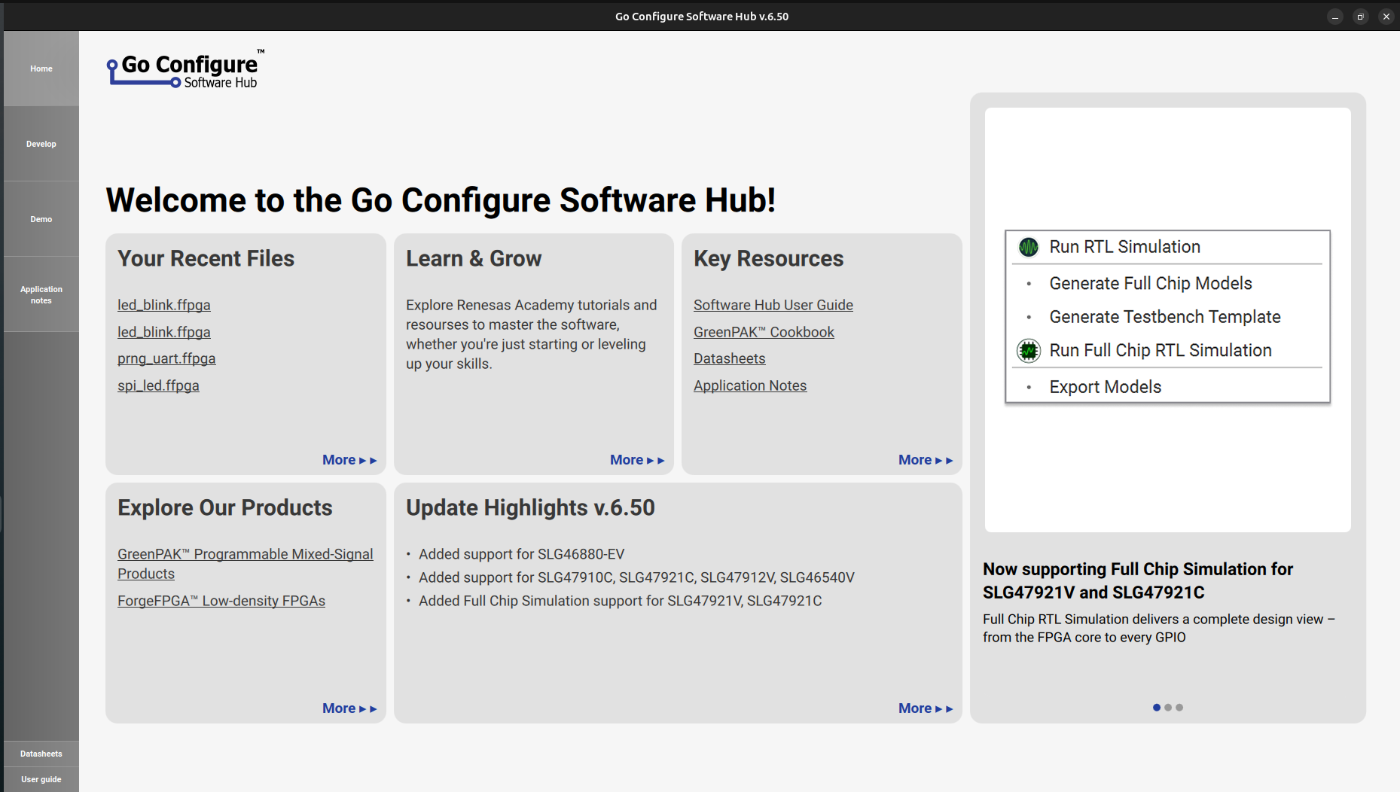
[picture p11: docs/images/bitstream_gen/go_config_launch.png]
Go Configure Software Hub
 

</div>

2. Double click on the FPGA (SLG47910 (BB)) in our case.
NOTE: You can also just open the led blink project available in the Projects section of github that can be done from the open option in the bottom right corner and then navigate to the ffpga file of that project. 

<div align="center">

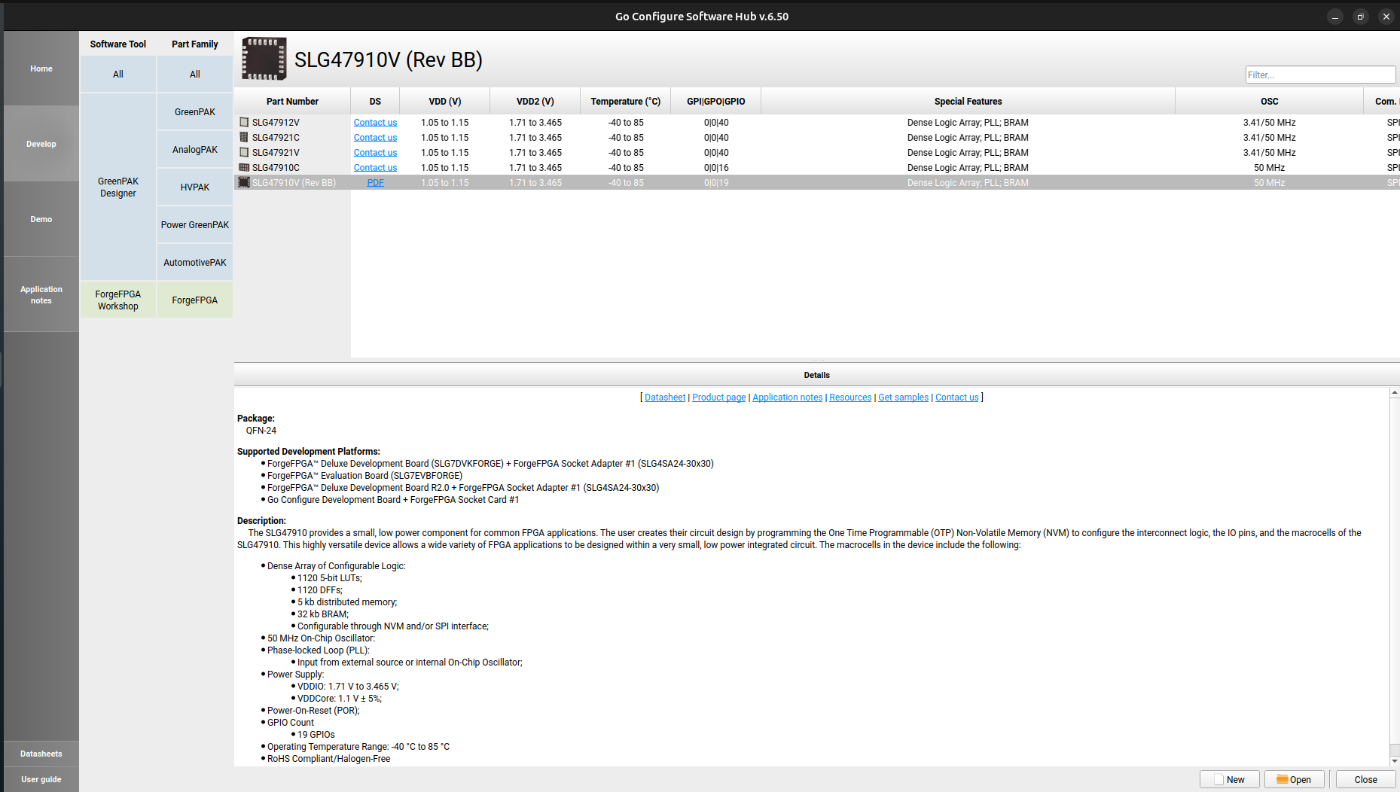
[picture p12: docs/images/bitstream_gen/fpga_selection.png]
 

</div>

3. Now select the project name and project location of your choice. 

<div align="center">

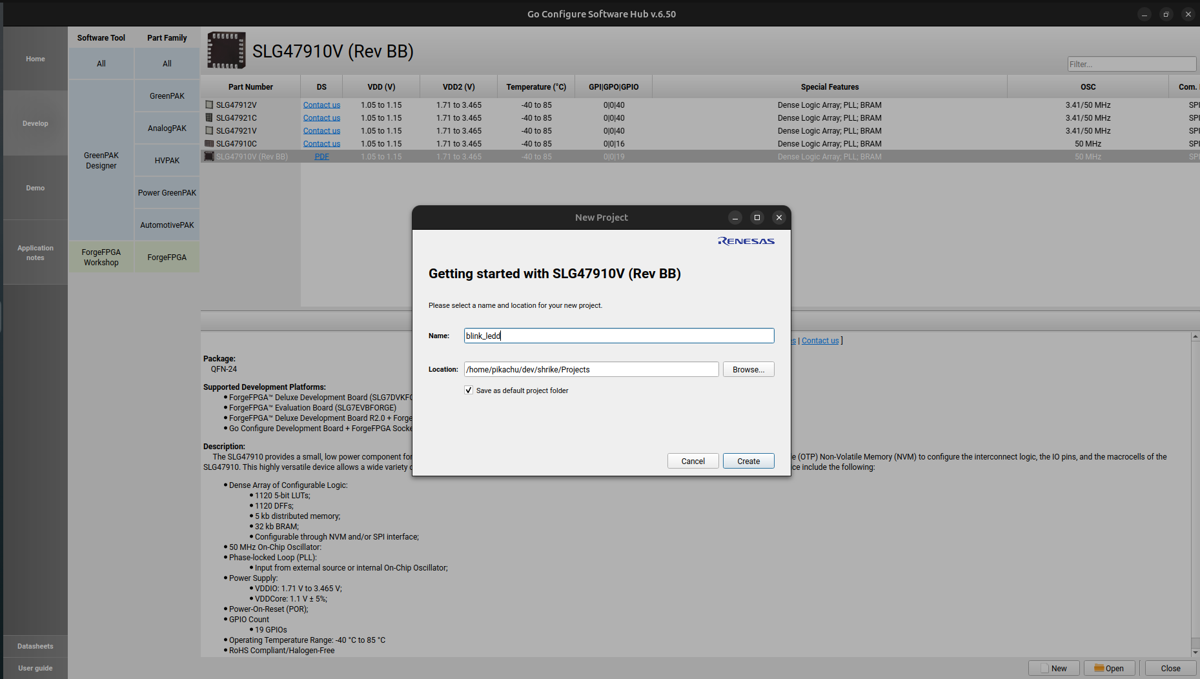
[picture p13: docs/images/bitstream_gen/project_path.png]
 

</div>

4. Now you will see the "Project setting" window select the first values in each box by clicking the arrow beside it.
It should look like this.

<div align="center">

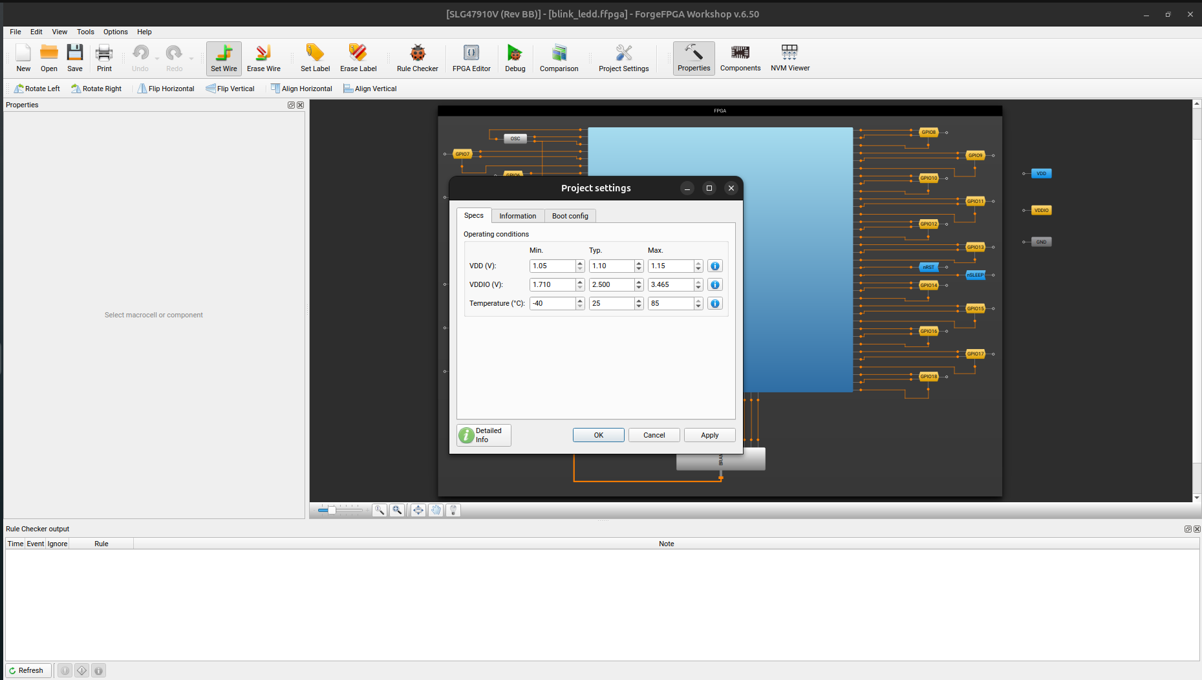
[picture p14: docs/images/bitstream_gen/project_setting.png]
 

</div>

5. Double click on the light blue square (FPGA Core) in and you should see this window. Now you are done with setup lets design our blink led hardware.    

<div align="center">

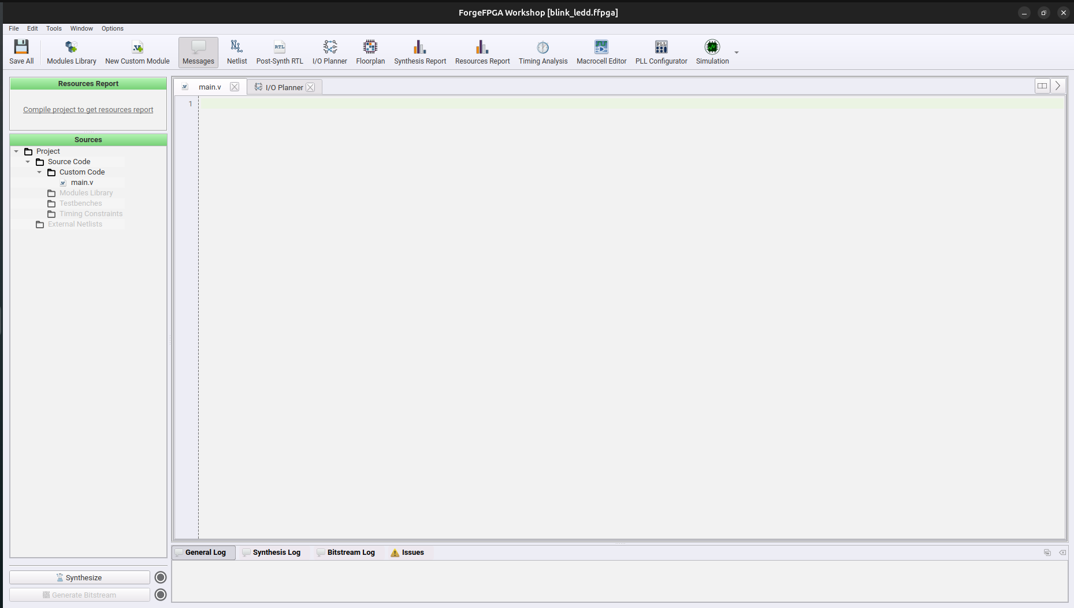
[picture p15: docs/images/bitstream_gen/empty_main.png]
 

</div>

Check out this short video guide.

:::{raw} html
<div align="center">
  <video width="90%" controls>
    <source src="bitstream_gen/go_config_launch.webm" type="video/webm">
    Your browser does not support the video tag.
  </video>
</div>
:::

### 2. Design 

Now we will how we can design a led_blink hardware. 

So as of now we are aware that we need a led that should be blinked so lets declare that in verilog. 

```
module led_blink (output led,
                  output led_en);
endmodule
```

Now every output requires a output enable for forge FPGA thus we will define a led_en pin as well and we will keep it high ( value = 1) by default so that led signal ( IO) is always a output from the board.

We need to figure out a way to so how are we going to blink ( toggle ) this led , for convenience lets assume we want to blink it every second . So this tell's us that we need some kind of clock to check the time and how much time has passed. 

We have a clock on out FPGA it is a pulsating signal that creates a 50Mhz square wave, we have to use this to calculate one second to do so we can simply add a counter that counts till 50_000_000 cycles as that how much we will require to reach one second at a 50 Mhz frequency. 

Thus now we will create a hardware that blinks a led whenever its counter reaches 50_000_000 and the verilog for this will look like this 

```
(* top *) module blink(
  (* iopad_external_pin, clkbuf_inhibit *) input clk,
  (* iopad_external_pin *) output LED,
  (* iopad_external_pin *) output LED_en,
  (* iopad_external_pin *) output clk_en
  );

  reg [31:0] counter;
  reg LED_status;

  assign LED_en = 1'b1;
  assign clk_en = 1'b1;
  
  always @ (posedge clk) begin
    counter <= counter + 1'b1;
    if (counter == 50_000_000) begin
      LED_status <= !LED_status;
      counter <= 32'b0;
    end
  end

  assign LED = LED_status;

endmodule 

```

There are a lot other ways to blink an led as well and you can always use those however before writing verilog for shrike please checkout [Style Guide](./verilog_style_guide.md) for reference .

However here we are assuming that you are using the code mentioned above . Get this code in the main.v in the software.

<div align="center">

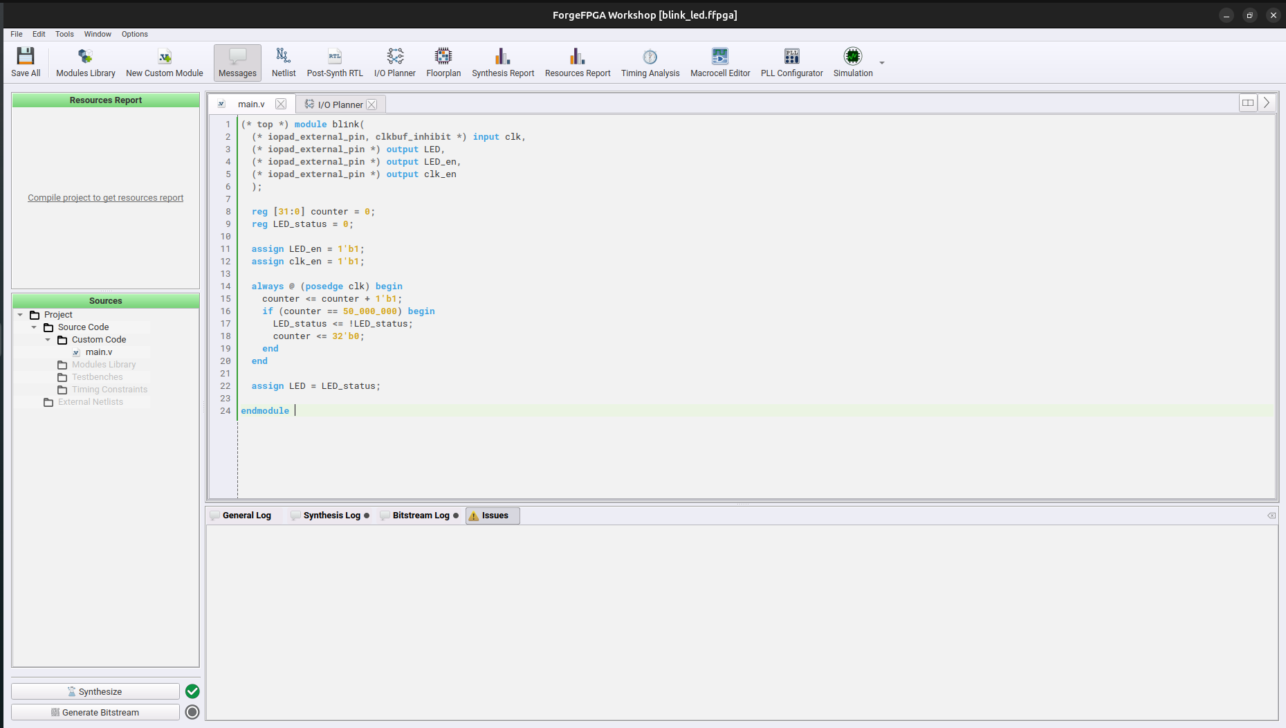
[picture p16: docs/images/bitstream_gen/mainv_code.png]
 

</div>

Now the next step will be to synthesize the verilog for doing so click the button in the bottom left corner. It should take a minute and then you will a green tick beside it that should tell you that synthesis has happens without any error. 

Now we will move to IO planning and bitstream generation.
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

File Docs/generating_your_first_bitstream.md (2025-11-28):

(generating_your_first_bitstream)=

# Shrike FPGA Bitstream Generation Guide 

Bitstream is a firmware that is used to programme the FPGA and map our design to it. Shrike uses a Renesas Forge FPGA SLGV SLG47910 1K Luts FPGA.The datasheet fr which can be found [here](https://www.renesas.com/en/products/slg47910) .

For generating the bitstream for shrike we will use these steps. 

  1. Setup 
  2. Design & Synthesis 
  3. IO Mapping and Placement and Routing (PNR)

I am here assuming that you have installed all the tools required if not check tools_setup_guide [HERE](./tools_setup_guide.md).

We will create a LED Blinking Project for this guide and we will start by launching the Go Configure Software Hub.  

### 1. Setup  

1. Launch the GO Configure Software Hub and move to the Forge FPGA tab under the Develop Tab. 

<div align="center">

 Go Configure Software Hub

</div>

2. Double click on the FPGA (SLG47910 (BB)) in our case.
NOTE: You can also just open the led blink project available in the Projects section of github that can be done from the open option in the bottom right corner and then navigate to the ffpga file of that project. 

<div align="center">

 shrike

</div>

3. Now select the project name and project location of your choice. 

<div align="center">

 shrike

</div>

4. Now you will see the "Project setting" window select the first values in each box by clicking the arrow beside it.
It should look like this.

<div align="center">

 shrike

</div>
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

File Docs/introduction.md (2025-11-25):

(introduction)=

# Introduction to Shrike Project 

Hello! So you’ve got the **Shrike-lite FPGA** - nice!

Before we explain how programming works on Shrike-lite, it’s important to understand what Shrike-lite actually is and how it differs from all kind of other embedded development boards.
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

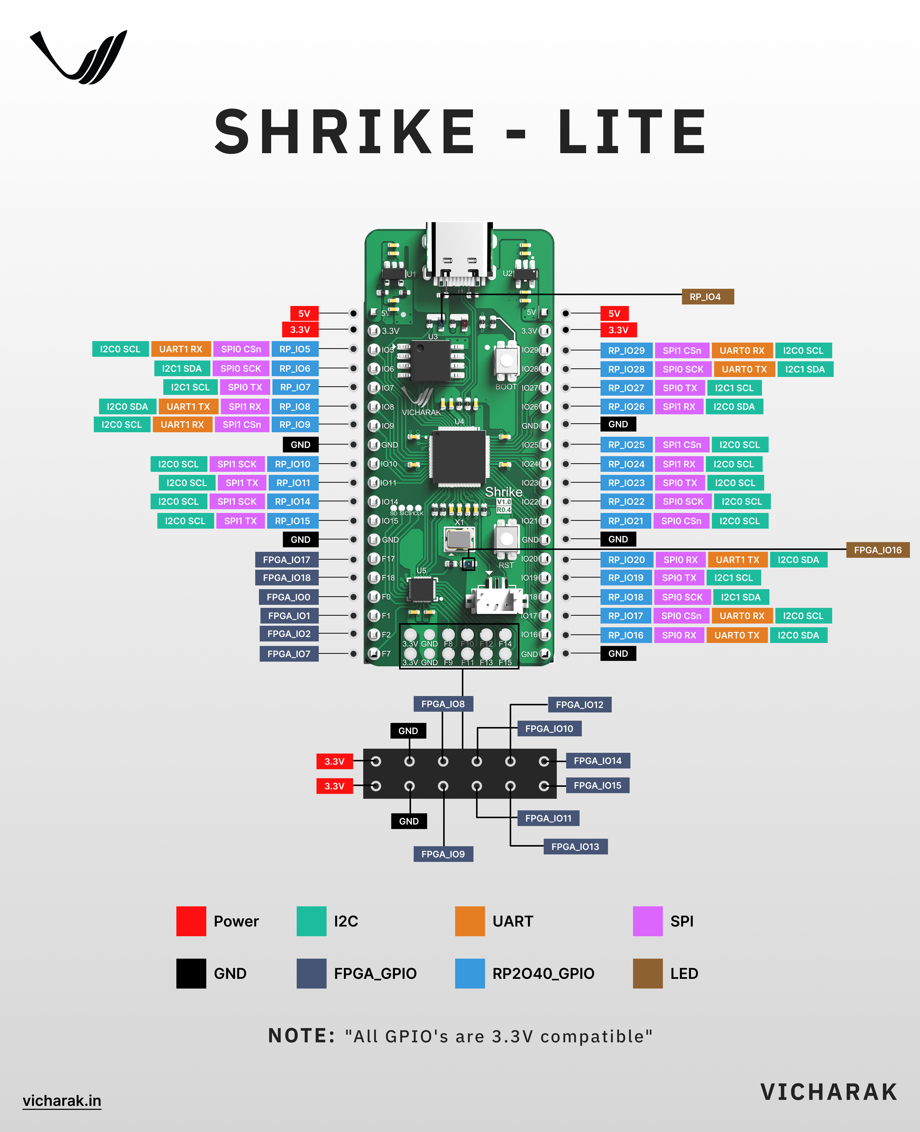
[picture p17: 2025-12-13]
docs/images/shrike_pinouts.png

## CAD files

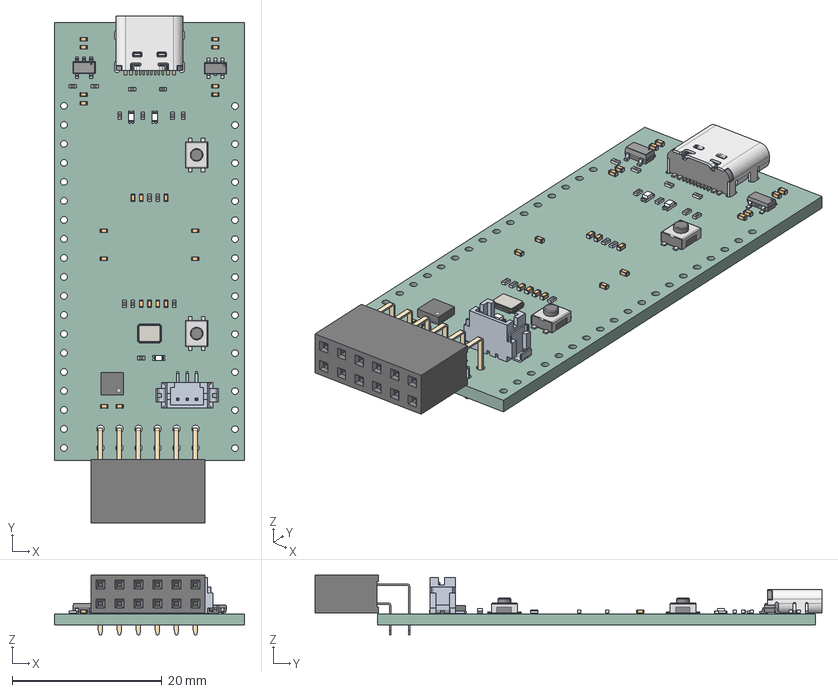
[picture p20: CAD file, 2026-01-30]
hardware/shrike-lite/kicad/v1_r0.4/Shrike-lite.step
25.4 x 67.8 x 7.98 mm
kicad_embedded_BCDEFA549BD92648B89B079BD65F0360 x 3
kicad_embedded_4BF2C315065B03F2EDB6664BF6E06EBC x 14
PinsArrayL
PinsArrayR
Shrike-lite 1.18.1
kicad_embedded_23D3BBCB113E4F12280F49A9A7372AAE
kicad_embedded_5DA03CE9F3160850AF560ED0F9C2898B
kicad_embedded_72BB9CE2D1522D823768491D5397E6AB x 2
kicad_embedded_29C47ED5F14A361E81E1A38E2F171F89
kicad_embedded_BBED6F8B535C06F9EA1D5AD73DD78B29
ConPins
PcbPins
Mold
Frame
Shrike-lite_PCB

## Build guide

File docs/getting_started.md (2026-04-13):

(getting_started)=

# Getting Started

In this getting started guide we will see how to blink an led on shrike both on fpga and MCU.

You can program the microcontroller on Shrike using three methods:<br>

&emsp;**1. Arduino (C/C++)**  
&emsp;**2. MicroPython**
&emsp;**3. Circuit-Python**

All are beginner-friendly, and you can switch between them anytime.  

Let's follow the steps and get Shrike up and running!

:::::::{tab-set}

::::::{tab-item} ArduinoIDE

# Shrike with ArduinoIDE

If you already know Arduino and love working with the Arduino IDE, you can continue using it with Shrike. You do not have to switch to MicroPython unless you want to.

We will follow these steps to setup our arduino IDE for shrike. If you don't have arduino IDE already ,you can download it from [here](https://www.arduino.cc/en/software/) or if you are using linux(ubuntu)then just run 
```
sudo apt install arduino
```

### Step 1. Adding the board support for Shrike

The Shrike has a on board RP2040/RP2350/ESP32-S3 has a host controller the Arduino IDE doesn't native support them however we can add the board support for the same.

It is quit straight forward we need to add this URL in the addition board URL section of arduino IDE which you can find in File->Preferences.

:::::{tab-set}

::::{tab-item} Shrike/Shrike-lite
:sync: Shrike/Shrike-lite

```
https://github.com/earlephilhower/arduino-pico/releases/download/global/package_rp2040_index.json
``` 

::::

::::{tab-item} Shrike-fi
:sync: Shrike-fi

```
https://raw.githubusercontent.com/espressif/arduino-esp32/gh-pages/package_esp32_index.json
``` 

::::

:::::

If you already have another board URL just add a "," between the two URL's.

<div align="center">

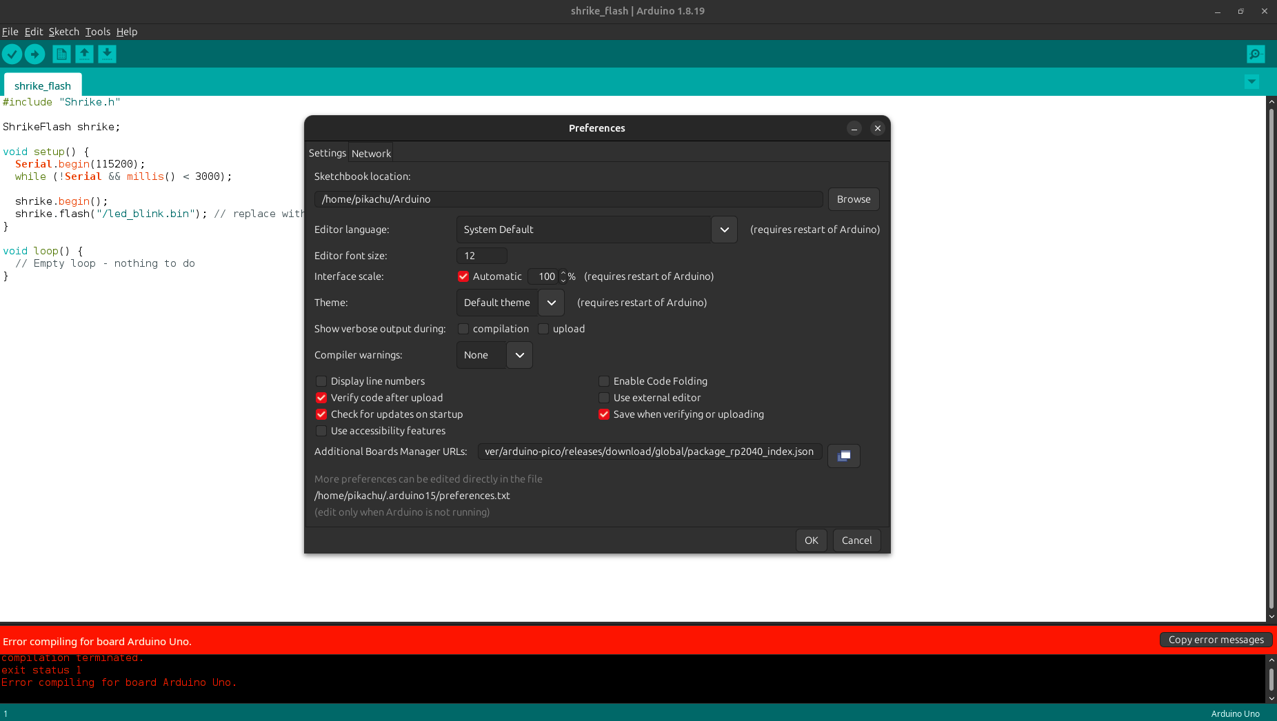
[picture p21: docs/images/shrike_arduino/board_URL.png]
ADD BOARD URL
 

</div>

These board support had been created by [earlephilhower](https://github.com/earlephilhower) and you can check out github [repository](https://github.com/earlephilhower/arduino-pico) for more details.

After adding the URL go to Tools->Boards->Board Manager in the Arduino IDE. 

:::::{tab-set}

::::{tab-item} Shrike/Shrike-lite
:sync: Shrike/Shrike-lite

Then search for pico and the board from Earle F. Philhower. 

<div align="center">

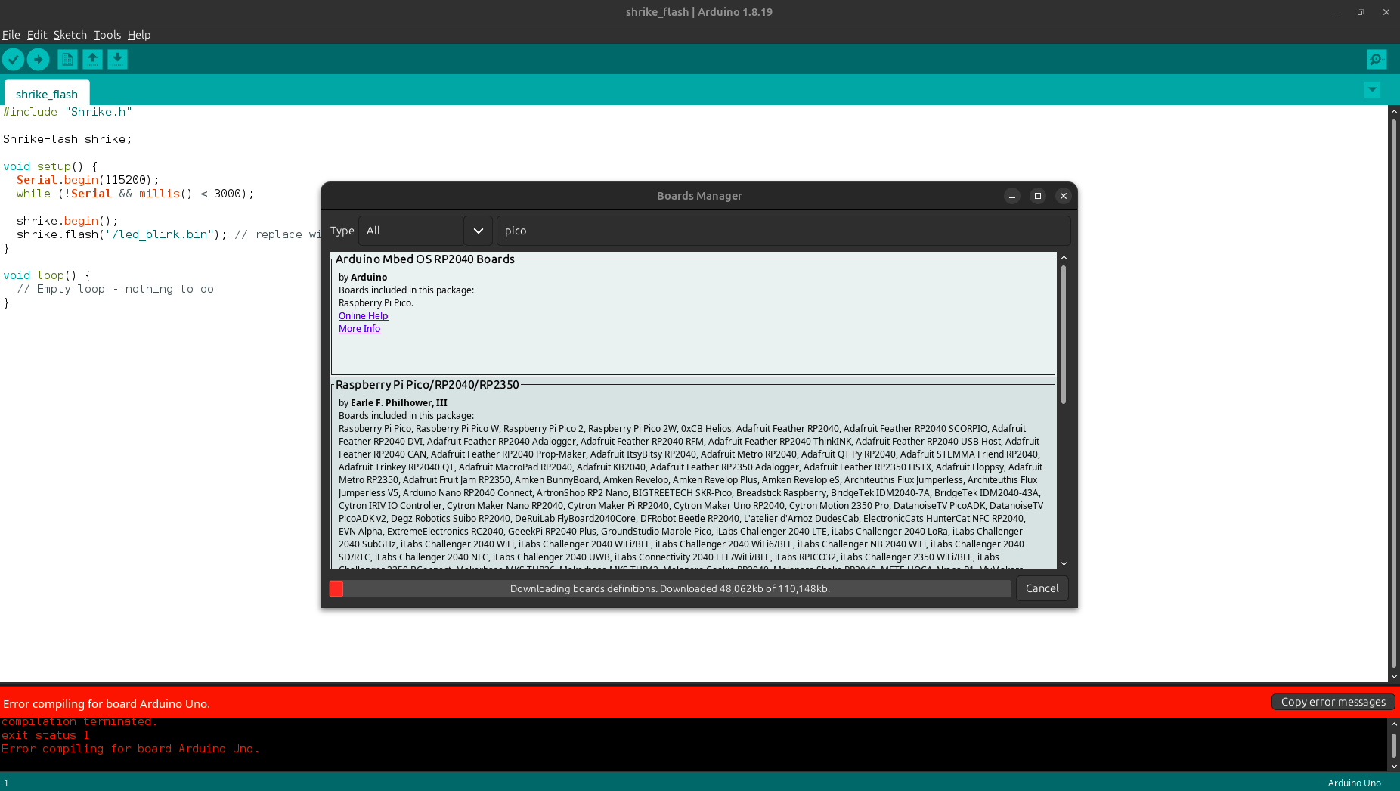
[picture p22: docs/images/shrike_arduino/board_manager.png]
ADD BOARD
 

</div>

::::

::::{tab-item} Shrike-fi
:sync: Shrike-fi

Then search for ESP32 by Espressif Systems.

<!-- TODO: Add board manager image for ESP32. -->

::::

:::::

Perfect we have successfully add the board support for the Shrike.

As we discussed earlier, in Shrike the micro-controller (RP/ESP32) is responsible for configuring the FPGA.  

To make this possible, we developed a simple mechanism: we store the FPGA bit-streams in the MCU's flash memory and retrieve them whenever we need to configure the FPGA. To do this we will need to use a file system called littleFS.

### Step 2. Adding the LittleFS Tool

The LittleFS library in Arduino allows you to store, load, and update the bitstream in the flash memory through the microcontroller.

We need to add a Little-FS utility to bind a bin file (FPGA bitstream with code for Shrike). We can find the utility [here](https://github.com/earlephilhower/arduino-littlefs-upload/releases) download the latest release ZIP. 

Now for setting up these tools for Arduino IDE version 2.x.x please follow [this](https://randomnerdtutorials.com/arduino-ide-2-install-esp32-littlefs/) guide and after proper setup please continue the below steps. 

This works for both the RP2040 and ESP32-S3 based boards. ( even tho name says esp32).

You will need to restart the Arduino IDE and you should see the Little FS tool like this in your Tools menu.

<!-- TODO: Update this image. -->

For more details on the LittleFS tool checkout this [repository](https://github.com/earlephilhower/arduino-littlefs-upload).

### Step 3. Installing the Shrike Library 

The Arduino library developed by Vicharak takes care of configuring the FPGA for you. You can install it directly from the Arduino IDE's Library Manager, just search for **"Shrike"** and install the **Shrike** library.

<!-- TODO: Update this image --> 

<div align="center">

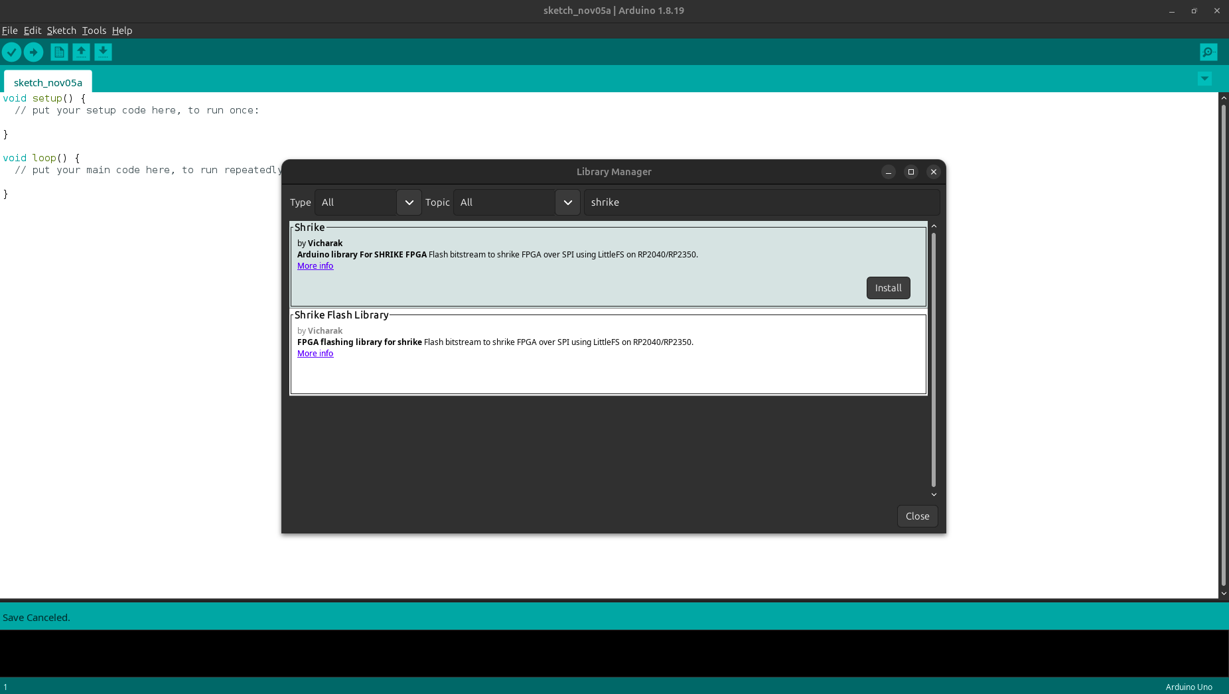
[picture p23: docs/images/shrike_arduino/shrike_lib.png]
ADD SHRIKE lib
 

</div>

We are almost done with the setup lets continue and blink en led on FPGA using the arduino IDE. 

### Step 4. Programming the FPGA from ArduinoIDE

Lets program out first bitstream to fpga using the arduino. We will be blinking an led.

Start Arduino IDE and look for Shrike -> shrike_flash in the example section of IDE and then save it with a name of your choice and at a location of your choice. This will create a folder with the name, now in the folder/dir create a subfolder by name `data` keep the case in mind. 

Any bitstream that needs to be uploaded to the board should be placed in the folder. 
We have already generated and hosted a bitstream to blink led [here](https://github.com/vicharak-in/shrike/blob/main/test/bitstreams/v1_4/led_blink.bin) save this bitstream to the data subfolder.

Checkout guide to learn how to generate your own fpga design [here](./generating_your_first_bitstream.md).

Once you have done this, open Arduino IDE and click on Compile. The compilation should complete without any errors. If you encounter any errors, don't worry,we have a Discord community. Hop in there and we'll help you out or you can always use claude or chatgpt.

If the compilation has been done without any error then it's time to connect the board in boot mode " PRESS THE BOOT BUTTON WHILE CONNECTING THE BOARD WITH PC" ( this should be done only the first time of setting up if arduino are if you have programmed the board with any other way last time).

:::::{tab-set}

::::{tab-item} Shrike/Shrike-lite
:sync: Shrike/Shrike-lite

In the tools section select the Board as VICHARAK Shrike Lite / VICHARAK Shrike based on your board version and flash size as 4MB Sketch:2MB and FS:2MB and CPU Speed as 125 Mhz. 

::::

::::{tab-item} Shrike-fi
:sync: Shrike-fi

In the tools section select the Board as Generic ESP32-S3 based on your board version and flash size as 8MB Sketch:4MB and FS:4MB . 

::::

:::::
Now you need to upload the file system to the board to do so press `ctrl+shift+p` you will see the drop down menu.

Search for Build LittleFS command and run it. 

After that in the same menu look for Upload LittleFS command and run that too. 

If both of these options are executed properly then then hit upload. 

You should see the beautiful blue led blinking on board.

Congratulation you have your arduino IDE and shrike ready to be programmed using the Arduino infrastructure. 

> Credit and Gratitude to [earlephilhower](https://github.com/earlephilhower/) for creating the board support for RP2040/RP2350 in ArduinoIDE and the little FS tool. 

<!-- 
For shrike Lite

:::::{tab-set}

::::{tab-item} Shrike/Shrike-lite
:sync: Shrike/Shrike-lite

Blehhhh Shrike-lite

::::

::::{tab-item} Shrike-fi
:sync: Shrike-fi

Blehh Shrike-fi

::::

:::::

-->

::::::

::::::{tab-item} Micro-python 

# Shrike with Micro-python 

We have created custom binary for shrike this contains a shrike.py library that has custom function to flash fpga and few other functions as well.

### 1. Uploading the shrike binary

:::::{tab-set}

::::{tab-item} Shrike/Shrike-lite
:sync: Shrike/Shrike-lite

1. Download the binary corresponding to your board version from the shrike's [Releases](https://github.com/vicharak-in/shrike/releases/)
2. Hold the boot button on the board and connect it the your pc now shrike will show up as as storage device.
3. Copy the downloaded uf2 in storage device you can simply drag and drop in mostly all the devices. 
4. After the successful copying the storage device should disappear.

Check the video tutorial on how to upload the uf2 Shrike dev board(its a generic board video and uf2 will differ in our case) [here](https://www.youtube.com/watch?v=os4mv_8jWfU).

Congratulations you have successfully uploaded the uf2. 

#### Shrike Mass Storage Device 

Onces that you have copied the uf2 to the Shrike.  The board will disconnect momentary and so up as both a mass storage device and tty/ACM device now the mass storage is the part where you would need to save you bitstream (read step 3). 

The default device ID for mass storage device is `5221-0000` this could be changed as per your choice. 
For windows simply right click and rename for changing the name in linux read [this](https://superuser.com/questions/223527/renaming-a-fat16-volume). 

::::

::::{tab-item} Shrike-fi
:sync: Shrike-fi

1. Download the binary corresponding to your board version from the shrike's [Releases](https://github.com/vicharak-in/shrike/releases/).

2. Install the ESP tools `pip install esptool`. 
    You might need to activate a python virtual environment. Check this guide to know how to do so. 

3. Then execute  this command `python -m esptool erase_flash`

4. And Flash the binary to ESP32-S3 using this command 

```
python -m esptool --chip esp32s3 -b 460800 --before default_reset --after hard_reset write_flash --flash_mode dio --flash_size 4MB --flash_freq 80m 0x0 firmware.bin
```

---

Congratulations you have successfully uploaded the binary. 

::::

:::::

### 2. Get the bitstream(.bin) for led blink 

To program a FPGA you will require  bitstream file this is much like a firmware for MCU's we will see how to generate these but for now we have uploaded the bitstream required for led_bin you can download them the corresponding to your board's version [here](https://github.com/vicharak-in/shrike/tree/main/test/bitstreams). 

Now that you have both uf2 and bin file settled up lets move forward and upload the bitstream to board.

### 3. Getting the Thonny IDE 

The bitstream can be uploaded on the shrike using one of these two ways 
   1. Using a GUI Based-IDE (Thonny)
   2. Using Command line interface (CLI)

In this guide we will use Thonny however guide to programme using CLI can be found [here](./shrike_cli_guide.md).

Now we will need to get thonny on our pc. Installation is quite straight forward You can download it from [here](https://thonny.org/). 

Now that we have got all the required tools set-ed up let blink some leds.

Open thonny and connect the board to the laptop (do not press boot button this time). And do these two things 
   1. Connect the board from the bottom right corner of Thonny IDE.
   2. Go to file view mode in the thonny to see the RP2350/RP2040 as a file system.

### 4. Flashing the bitstream 

You should in thonny see both the your pc and Shrike file's on the left windows now we have to transfer the led_blink.bin file to the Shrike. 
To do so find the file on your system then right click and upload.

Now we will have to flash this file to the fpga to do so we will use the function 

```
    shrike.flash("<your_bitstream_name>.bin")
```

:::{note}

For any custom project the bitstream file that you need to copy will be named as "FPGA_bitstream_MCU.bin" found in fpga -> build -> bitstream folder in your project directory.  
If you copy any other file present in the bitstream folder the fpga wont be programmed.
You are free to change the name of this file however you please.

:::

In thonny open a new python file and write this python script 

```
    import shrike
    shrike.flash("led_blink.bin")
```

Save this file to your board and run it. (to run this file on board boot up just name it as main.py)

::::::

::::::{tab-item} Circuit-Python 

# Shrike with Circuit Python

CircuitPython is a programming language designed by adafruit to simplify experimenting and learning to code on low-cost microcontroller boards. It build on a fork of Micropython , thus its seems very similar yet very different.

The way Circuit-Python works with Shrike is we have a custom circuit python build (binary). One must follow these steps to get started with the Circuit-Python on Shrike.

### 1. Uploading the Shrike binary

1. Download the binary corresponding to your board version from the shrike's [Release](https://github.com/vicharak-in/shrike/releases/).
2. Hold the boot button on the board and connect it the your pc now shrike will show up as as storage device.
3. Copy the downloaded uf2 in storage device you can simply drag and drop in mostly all the devices. 
4. After the successful copying the storage device should disappear.

Check the video tutorial on how to upload the uf2 Shrike dev board(its a generic board video and uf2 will differ in our case) [here](https://www.youtube.com/watch?v=os4mv_8jWfU).

Congratulations you have successfully uploaded the Circuit-Python uf2. 

### 2. Get the bitstream(.bin) for led blink 

To program a FPGA you will require  bitstream file this is much like a firmware for MCU's we will see how to generate these but for now we have uploaded the bitstream required for led_bin you can download them the corresponding to your board's version [here](https://github.com/vicharak-in/shrike/tree/main/test/bitstreams). 

Now that you have both uf2 and bin file settled up lets move forward and upload the bitstream to board.

The board will showing up as a storage device on the pc now copy the downloaded bitstream to the board. 

### 3. Getting the Thonny IDE 

Now we will need to get thonny on our pc. Installation is quite straight forward You can download it from [here](https://thonny.org/). 

Now that we have got all the required tools set-ed up let blink some leds.

Open thonny and connect the board to the laptop (do not press boot button this time). And connect the board from the bottom right corner of Thonny IDE.

### 4. Flashing the bitstream 

The custom binary of circuit-python contain a python library for flashing and resting  the fpga and a few other functions as well. 

So we will use this library to flash this bitstream file to the fpga, to do so we will use the function 

```
    shrike.flash("<your_bitstream_name>.bin")
```

If you are using the test bitstream provided by use it is named as led_blink.bin 

:::{note}

For any custom project the bitstream file that you need to copy will be named as "FPGA_bitstream_MCU.bin" found in fpga -> build -> bitstream folder in your project directory.  
If you copy any other file present in the bitstream folder the fpga wont be programmed.
You are free to change the name of this file however you please.

:::

In thonny open a new python file and write this python script 

```
    import shrike
    shrike.flash("led_blink.bin")
```

Save this file to your board and run it. (to run this file on board boot up just name it as main.py)

::::::

:::::::

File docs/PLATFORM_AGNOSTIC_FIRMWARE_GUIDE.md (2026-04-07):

# Writing Platform-Agnostic Firmware for Shrike

This guide explains how to write a single firmware source file that runs on all boards in the Shrike family — Shrike-Lite (RP2040), Shrike (RP2350), and Shrike-fi (ESP32-S3) — without maintaining separate codebases.

The FPGA side is identical across all boards (same SLG47910 ForgeFPGA, same bitstream). Only the host MCU changes. This guide covers how to handle those MCU differences cleanly.

---

## The Problem

Each board in the Shrike family uses a different host MCU:

| Board | MCU | Arduino Core | MicroPython Platform |
|---|-----|---|---|
| Shrike-Lite | RP2040 | `arduino-pico` (Earle Philhower) | `rp2` |
| Shrike | RP2350 | `arduino-pico` (Earle Philhower) | `rp2` |
| Shrike-fi | ESP32-S3 | `arduino-esp32` (Espressif) | `esp32` |

The differences typically fall into three categories:

1. **Pin assignments** — Different GPIOs for the FPGA interconnect, SPI, UART
2. **Peripheral initialization** — Different SPI class instances, UART ports
3. **Platform APIs** — Filesystem, Wi-Fi (ESP32 only), deep sleep, etc.

The goal is to isolate these differences into a small, clearly marked section at the top of each file, while keeping the core application logic shared.

---

## Arduino IDE — Using `#ifdef`

### How It Works

The Arduino build system defines architecture macros at compile time based on the selected board. These macros let you conditionally compile different code blocks.

| Board Selected | Macro Defined |
|---|---|
| Any RP2040 board | `ARDUINO_ARCH_RP2040` |
| Any RP2350 board | `ARDUINO_ARCH_RP2040` (same core) |
| Any ESP32 board | `ARDUINO_ARCH_ESP32` |

> **Note:** RP2350 uses the same `arduino-pico` core as RP2040 and defines the
> same `ARDUINO_ARCH_RP2040` macro. If you ever need to distinguish between
> RP2040 and RP2350 specifically, check for `PICO_RP2350` which is defined
> only on RP2350 builds.

### Pattern 1 — Pin Definition Block

The simplest and most common case. Put all pin definitions in a single block at the top.

```cpp
// =============================================================
// Platform Configuration
// =============================================================

#ifdef ARDUINO_ARCH_RP2040
  // Shrike-Lite (RP2040) / Shrike (RP2350)
  #define FPGA_SPI_SS    1
  #define FPGA_SPI_SCK   2
  #define FPGA_SPI_MOSI  3
  #define FPGA_SPI_MISO  0
  #define FPGA_EN        13
  #define FPGA_PWR       12

  #define UART_TX_PIN    0
  #define UART_RX_PIN    1

#elif defined(ARDUINO_ARCH_ESP32)
  // Shrike-fi (ESP32-S3)
  #define FPGA_SPI_SS    10
  #define FPGA_SPI_SCK   12
  #define FPGA_SPI_MOSI  11
  #define FPGA_SPI_MISO  13
  #define FPGA_EN        5
  #define FPGA_PWR       4

  #define UART_TX_PIN    17
  #define UART_RX_PIN    18

#else
  #error "Unsupported board. Please use RP2040, RP2350, or ESP32-S3."
#endif

// =============================================================
// Application Code (shared across all platforms)
// =============================================================

void setup() {
  Serial.begin(115200);
  pinMode(INTER_0, INPUT);
  // ... rest of setup
}

void loop() {
  int val = digitalRead(INTER_0);
  // ... rest of application logic
}
```

**Key points:**
- The `#else #error` block catches unsupported boards at compile time
- All platform-specific code is contained in ONE block
- Everything after the block is 100% shared

### Pattern 2 — SPI Instance Handling

RP2040 and ESP32 initialize SPI differently. RP2040's default `SPI` object works fine, but ESP32 needs an explicit HSPI instance to avoid conflicts with its internal flash.

```cpp
#include <SPI.h>
#include <ShrikeFlash.h>

#ifdef ARDUINO_ARCH_RP2040
  // Default SPI works on RP2040/RP2350
  ShrikeFlash fpga;

#elif defined(ARDUINO_ARCH_ESP32)
  // ESP32 needs a dedicated HSPI instance
  SPIClass _hspi(HSPI);
  ShrikeFlash fpga(FPGA_EN, FPGA_PWR, FPGA_SPI_SS,
                   FPGA_SPI_SCK, FPGA_SPI_MOSI, FPGA_SPI_MISO);
#endif

void setup() {
  Serial.begin(115200);

  #ifdef ARDUINO_ARCH_ESP32
    _hspi.begin(FPGA_SPI_SCK, FPGA_SPI_MISO, FPGA_SPI_MOSI, FPGA_SPI_SS);
    fpga.begin(&_hspi);
  #else
    fpga.begin();
  #endif

  fpga.flash("/bitstream.bin");
}
```

> **Why HSPI?** ESP32's default SPI bus (VSPI) is often shared with internal
> flash. Using HSPI avoids the mutex crash that occurs when ShrikeFlash
> tries to access SPI while FreeRTOS is managing the flash bus.
> This was a real bug that was fixed during the ESP32 port of ShrikeFlash.

### Pattern 3 — Distinguishing RP2040 from RP2350

For most Shrike examples, RP2040 and RP2350 are interchangeable. But if you need to detect the specific chip (for example, to use RP2350-only features like extra GPIO or security functions):

```cpp
#ifdef ARDUINO_ARCH_RP2040
  #ifdef PICO_RP2350
    // RP2350-specific code
    #define MCU_NAME "RP2350"
  #else
    // RP2040-specific code
    #define MCU_NAME "RP2040"
  #endif
#elif defined(ARDUINO_ARCH_ESP32)
  #define MCU_NAME "ESP32-S3"
#endif

void setup() {
  Serial.begin(115200);
  Serial.print("Running on: ");
  Serial.println(MCU_NAME);
}
```

### Pattern 4 — Feature Flags for Optional Capabilities

ESP32-S3 has Wi-Fi and Bluetooth. RP2040/RP2350 don't. Use feature flags instead of scattering `#ifdef` throughout your code:

```cpp
// Feature detection
#ifdef ARDUINO_ARCH_ESP32
  #define HAS_WIFI       1
  #define HAS_BLUETOOTH  1
#else
  #define HAS_WIFI       0
  #define HAS_BLUETOOTH  0
#endif

void setup() {
  Serial.begin(115200);

  #if HAS_WIFI
    WiFi.begin("ssid", "password");
    Serial.println("Wi-Fi connecting...");
  #else
    Serial.println("Wi-Fi not available on this board");
  #endif
}
```

**Why feature flags?** They self-document what each platform can do. A contributor reading the code sees `HAS_WIFI` and immediately understands the intent, rather than parsing `ARDUINO_ARCH_ESP32` and guessing why it's there.

### Pattern 5 — Platform Abstraction Header (Advanced)

For complex examples with many platform differences, extract everything into a shared header:

```
firmware/
├── arduino-ide/
│   ├── uart_sum.ino
│   └── shrike_platform.h
```

**shrike_platform.h:**
```cpp
#ifndef SHRIKE_PLATFORM_H
#define SHRIKE_PLATFORM_H

#ifdef ARDUINO_ARCH_RP2040
  #define PLATFORM_NAME     "RP2040"
  #define FPGA_SPI_SS       1
  #define FPGA_SPI_SCK      2
  #define FPGA_SPI_MOSI     3
  #define FPGA_SPI_MISO     0
  #define FPGA_EN           13
  #define FPGA_PWR          12
  #define HAS_WIFI          0
  #define HAS_BLUETOOTH     0

#elif defined(ARDUINO_ARCH_ESP32)
  #define PLATFORM_NAME     "ESP32-S3"
  #define FPGA_SPI_SS       10
  #define FPGA_SPI_SCK      12
  #define FPGA_SPI_MOSI     11
  #define FPGA_SPI_MISO     13
  #define FPGA_EN           5
  #define FPGA_PWR          4
  #define HAS_WIFI          1
  #define HAS_BLUETOOTH     1

#else
  #error "Unsupported board"
#endif

#endif // SHRIKE_PLATFORM_H
```

**uart_sum.ino:**
```cpp
#include "shrike_platform.h"
#include <ShrikeFlash.h>

// Clean application code — no #ifdefs needed here
void setup() {
  Serial.begin(115200);
  Serial.print("Shrike running on: ");
  Serial.println(PLATFORM_NAME);

  pinMode(INTER_0, OUTPUT);
  // ...
}
```

> **When to use this:** If your `#ifdef` block exceeds ~20 lines in the main
> sketch, extract it into a header. For simple examples (pin changes only),
> keep it inline — the header adds a file without adding clarity.

---

## MicroPython — Using `sys.platform`

### How It Works

MicroPython doesn't have a preprocessor. Instead, you detect the platform at runtime using `sys.platform`:

| Board | `sys.platform` |
|---|---|
| Shrike-Lite (RP2040) | `'rp2'` |
| Shrike (RP2350) | `'rp2'` |
| Shrike-fi (ESP32-S3) | `'esp32'` |

### Pattern 1 — Pin Configuration Dict

```python
import sys
from machine import Pin, UART, SPI

# =============================================================
# Platform Configuration
# =============================================================

if sys.platform == 'rp2':
    CONFIG = {
        'platform':      'RP2040/RP2350',
        'fpga_spi_ss':   1,
        'fpga_spi_sck':  2,
        'fpga_spi_mosi': 3,
        'fpga_spi_miso': 0,
        'fpga_en':       13,
        'fpga_pwr':      12,
        'uart_id':       0,
        'uart_tx':       0,
        'uart_rx':       1,
        'interconnect':  [6, 7, 8, 9, 10, 11],
    }

elif sys.platform == 'esp32':
    CONFIG = {
        'platform':      'ESP32-S3',
        'fpga_spi_ss':   10,
        'fpga_spi_sck':  12,
        'fpga_spi_mosi': 11,
        'fpga_spi_miso': 13,
        'fpga_en':       5,
        'fpga_pwr':      4,
        'uart_id':       1,
        'uart_tx':       17,
        'uart_rx':       18,
        'interconnect':  [35, 36, 37, 38, 39, 40],
    }

else:
    raise RuntimeError(f"Unsupported platform: {sys.platform}")

# =============================================================
# Application Code (shared)
# =============================================================

print(f"Running on {CONFIG['platform']}")

uart = UART(CONFIG['uart_id'],
            baudrate=115200,
            tx=Pin(CONFIG['uart_tx']),
            rx=Pin(CONFIG['uart_rx']))

inter_pins = [Pin(p, Pin.IN) for p in CONFIG['interconnect']]
```

**Why a dict?** Cleaner than loose variables. You can pass `CONFIG` to functions, print it for debugging, or serialize it. It also keeps the platform block visually contained.

### Pattern 2 — UART Initialization Differences

RP2040 and ESP32 handle UART slightly differently:

```python
import sys
from machine import UART, Pin

if sys.platform == 'rp2':
    # RP2040: UART 0 with explicit pin assignment
    uart = UART(0, baudrate=115200, tx=Pin(0), rx=Pin(1))

elif sys.platform == 'esp32':
    # ESP32: UART 1 (UART 0 is reserved for REPL)
    uart = UART(1, baudrate=115200, tx=Pin(17), rx=Pin(18))

# Shared logic — works with either uart object
def send_command(cmd):
    uart.write(cmd.encode())

def read_response():
    if uart.any():
        return uart.read()
    return None
```

> **ESP32 UART note:** UART 0 on ESP32 is typically connected to the USB-REPL.
> Always use UART 1 or UART 2 for FPGA communication on Shrike-fi.

### Pattern 3 — SPI for FPGA Bitstream Flashing

```python
import sys
from machine import SPI, Pin
import time

if sys.platform == 'rp2':
    spi = SPI(0,
              baudrate=8_000_000,
              polarity=0,
              phase=0,
              sck=Pin(2),
              mosi=Pin(3),
              miso=Pin(0))
    ss  = Pin(1, Pin.OUT, value=1)
    en  = Pin(13, Pin.OUT)
    pwr = Pin(12, Pin.OUT)

elif sys.platform == 'esp32':
    spi = SPI(1,
              baudrate=8_000_000,
              polarity=0,
              phase=0,
              sck=Pin(12),
              mosi=Pin(11),
              miso=Pin(13))
    ss  = Pin(10, Pin.OUT, value=1)
    en  = Pin(5, Pin.OUT)
    pwr = Pin(4, Pin.OUT)

# Shared flashing logic
def flash_fpga(filename):
    """Flash a bitstream to the FPGA via SPI."""
    pwr.value(0)
    time.sleep_ms(10)
    pwr.value(1)
    time.sleep_ms(10)

    with open(filename, 'rb') as f:
        data = f.read()

    ss.value(0)
    spi.write(data)
    ss.value(1)

    print(f"Flashed {len(data)} bytes from {filename}")
```

### Pattern 4 — Feature Detection at Runtime

For optional features like Wi-Fi on ESP32:

```python
import sys

def has_wifi():
    """Check if the current platform supports Wi-Fi."""
    try:
        import network
        return hasattr(network, 'WLAN')
    except ImportError:
        return False

# Usage
if has_wifi():
    import network
    wlan = network.WLAN(network.STA_IF)
    wlan.active(True)
    print("Wi-Fi available")
else:
    print("Wi-Fi not available on this board")
```

**Why `try/except` instead of `sys.platform`?** It's more Pythonic and future-proof. If a new board supports Wi-Fi, this code works automatically without adding another `elif`.

### Pattern 5 — Platform Config Module (Advanced)

For complex projects, extract the config into a shared module:

```
firmware/
└── micropython/
    ├── uart_sum.py
    └── shrike_config.py
```

**shrike_config.py:**
```python
"""
Platform configuration for the Shrike family.
Auto-detects the board and exports the correct pin mappings.
"""

import sys

_CONFIGS = {
    'rp2': {
        'platform':      'RP2040/RP2350',
        'spi_id':        0,
        'fpga_spi_ss':   1,
        'fpga_spi_sck':  2,
        'fpga_spi_mosi': 3,
        'fpga_spi_miso': 0,
        'fpga_en':       13,
        'fpga_pwr':      12,
        'uart_id':       0,
        'uart_tx':       0,
        'uart_rx':       1,
        'interconnect':  [6, 7, 8, 9, 10, 11],
    },
    'esp32': {
        'platform':      'ESP32-S3',
        'spi_id':        1,
        'fpga_spi_ss':   10,
        'fpga_spi_sck':  12,
        'fpga_spi_mosi': 11,
        'fpga_spi_miso': 13,
        'fpga_en':       5,
        'fpga_pwr':      4,
        'uart_id':       1,
        'uart_tx':       17,
        'uart_rx':       18,
        'interconnect':  [35, 36, 37, 38, 39, 40],
    },
}

if sys.platform not in _CONFIGS:
    raise RuntimeError(
        f"Unsupported platform: {sys.platform}. "
        f"Expected one of: {list(_CONFIGS.keys())}"
    )

board = _CONFIGS[sys.platform]
```

**uart_sum.py:**
```python
from shrike_config import board
from machine import UART, Pin

print(f"Running on {board['platform']}")

uart = UART(board['uart_id'],
            baudrate=115200,
            tx=Pin(board['uart_tx']),
            rx=Pin(board['uart_rx']))

# Clean application code — no platform checks needed
while True:
    if uart.any():
        data = uart.read()
        # process data ...
```

> **When to use this:** When multiple scripts in the same project all need
> platform config. For single-file examples, keep the config inline.

---

## Guidelines for Shrike Contributors

### When Writing a New Example

1. Start with the pin config block at the top (Pattern 1 for either language)
2. Keep all `#ifdef` / `sys.platform` checks in ONE place — don't scatter them
3. Use the `#else #error` / `raise RuntimeError` pattern to catch unsupported boards
4. Test on at least RP2040 + ESP32 before submitting (or note which boards are tested)
5. If the firmware is truly identical across boards (no pin differences), skip the platform block entirely

### When the Differences Are Too Large

Sometimes the firmware for RP2040 and ESP32 diverges significantly — different libraries, different APIs, different architecture. In that case, don't force a single file. Split into separate files:

```
firmware/
├── arduino-ide
│   ├── uart_sum_rp2040.ino
│   └── uart_sum_esp32.ino
└── micropython
    ├── uart_sum_rp2040.py
    └── uart_sum_esp32.py
```

**The rule of thumb:** If more than 40% of the code is inside `#ifdef` blocks, the "platform-agnostic" file is harder to read than two separate files. Split it.

### Decision Flowchart

```
Does the firmware differ between RP2040 and ESP32?
│
├── No  → Single file, no platform block needed
│
├── Only pin numbers differ
│   → Single file + Pattern 1 (pin config block)
│
├── Pin numbers + peripheral init differ
│   → Single file + Pattern 2 (pin config + init block)
│
├── Significant logic differences (>30% of code)
│   → Separate files per board
│
└── Shared config needed across multiple scripts
    → Extract into shrike_platform.h or shrike_config.py
```

---

## Quick Reference

### Arduino — Common Macros

| Macro | When Defined |
|---|---|
| `ARDUINO_ARCH_RP2040` | RP2040 and RP2350 (arduino-pico core) |
| `PICO_RP2350` | RP2350 only |
| `ARDUINO_ARCH_ESP32` | All ESP32 variants |
| `ARDUINO_ESP32S3_DEV` | ESP32-S3 specifically |

### MicroPython — Platform Strings

| String | When Returned by `sys.platform` |
|---|---|
| `'rp2'` | RP2040 and RP2350 |
| `'esp32'` | All ESP32 variants |

### Pin Mapping Reference

| Function | Shrike-Lite (RP2040) | Shrike (RP2350) | Shrike-fi (ESP32-S3) |
|---|---|---|---|
| SPI SS | 1 | 1 | 10 |
| SPI SCK | 2 | 2 | 12 |
| SPI MOSI | 3 | 3 | 11 |
| SPI MISO | 0 | 0 | 13 |
| FPGA EN | 13 | 13 | 5 |
| FPGA PWR | 12 | 12 | 4 |

---

## Summary

The Shrike family shares the same FPGA. The only firmware differences are pin mappings and peripheral initialization on the host MCU. By isolating these differences into a clearly marked configuration block at the top of each file, you get:

- **One file to maintain** instead of two or three
- **Consistent behavior** across the entire Shrike family
- **Easy onboarding** — contributors see the pattern once and can replicate it
- **Future-proof** — when Shrike-fi ships, existing examples just need a pin block added

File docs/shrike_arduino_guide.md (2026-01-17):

(shrike_arduino_guide)=

# Using Shrike With ArduinoIDE

If you are someone who is familiar with arduino and its infrastructure and don't want to move away to micro-python no worries we have got you cover.

These are the steps you can follow make arduino IDE usable with shrike.

Now before starting you should know that you will still need to use the Renesas Go configure software hub for generating firmware for fpga however all the other task can be done from arduino ide. 

Now we will follow these steps to setup our arduino IDE for shrike. If you don't have arduino IDE already ,you can download it from [here](https://www.arduino.cc/en/software/) or if you are using linux(ubuntu)then just run 
```
sudo apt install arduino
```

### Step 1. Adding the board support for RP2350/RP2040

The Shrike has a on board RP2350/RP2040 has a host controller the Arduino IDE doesn't native support them however we can add the board support for the same. 
It is quit straight forward we need to add this URL 
```
https://github.com/earlephilhower/arduino-pico/releases/download/global/package_rp2040_index.json
``` 
in the addition board URL section of arduino IDE which you can find in File->Preferences.

<div align="center">

 ADD BOARD URL

</div>

If you already have another board URL just add a "," between the two URL's.

These board support had been created by [earlephilhower](https://github.com/earlephilhower) and you can check out github [repository](https://github.com/earlephilhower/arduino-pico) for more details.

After adding the URL go to Tools->Boards->Board Manager in the Arduino IDE. 
Then search for pico and the board from Earle F. Philhower. 

<div align="center">

 ADD BOARD

</div>
Perfect we have successfully add the board support for the RP2040/RP2350.

### Step 2. Adding the Little-FS Tool 

Now we need to add a Little-FS utility to bind a bin file (FPGA bitstream with code for Shrike). We can find the utility [here](https://github.com/earlephilhower/arduino-pico-littlefs-plugin/releases/) download the latest release ZIP. 

Now we need to unzip and copy it to the tools directory in Arduino directory.

In case of windows you will find the Arduino folder in C disk if you have not changed it during installation.
In case of linux it would be available in your home directory. 

The directory/ folder  should look like this `<home_dir>/Arduino/tools/PicoLittleFS/tool/picolittlefs.jar`

Now you will need to restart the Arduino IDE and you should see the Pico Little FS tool like this in your Tools menu.

For more details on the PicoLittleFS tool checkout this [repository](https://github.com/earlephilhower/arduino-pico-littlefs-plugin).

### Step 3. Installing the Shrike Library 

Now we need to add the Shrike Library in arduino to do so go to library manager in arduino IDE and search Shrike and install the Shrike library.

<div align="center">

 ADD SHRIKE lib

</div>

Choose the first one names as Shrike and not the shrike flash library.
We are almost done with the setup lets continue and blink en led on FPGA using the arduino IDE. 

### Step 4. Programming the FPGA from ArduinoIDE
Lets program out first bitstream to fpga using the arduino. We will be blinking an led.

StartArduino IDE and look for Shrike >- shrike_flash in the example section of IDE and then save it with a name of you choice and at a location of your choice. This will create a folder with the name, now in the folder/dir create a subfolder by name `data` keep the case and in mind. 

Any bitstream that needs to be uploaded to the board should be placed in the folder. 
We have already generated and hosted a bitstream to blink led [here](https://github.com/vicharak-in/shrike/blob/main/test/bitstreams/v1_4/led_blink.bin) save this bitstream to the data subfolder.

Checkout guide to learn how to generate your own fpga design [here](./generating_your_first_bitstream.md).

Onces you have done this go to arduino and hit compile your compilation should finish without error if error occurs don't we have s discord hope on there. 

If the compilation has been done without any error then it's time to connect the board in boot mode " PRESS THE BOOT BUTTON WHILE CONNECTING THE BOARD WITH PC" ( this should be done only the first time of setting up if arduino are if you have programmed the board with any other way last time).

And then hit upload on the board. 

You should see the beautiful blue led blinking on board.

Congratulation you have you arduino IDE and shrike ready to programmed using the Arduino infrastructure. 

>Credit and Gratitude  to [earlephilhower](https://github.com/earlephilhower/) to creating the board support for RP2040/RP2350 in ArduinoIDE and the little FS tool.

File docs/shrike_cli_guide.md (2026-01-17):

(shrike_cli_guide)=

# User guide to access and use shrike from your terminal(CLI)

If you are anything like our team at [vicharak](vicharak.in) and you don't want to move away from the terminal. We have got you cover here is a quick guide for accessing and using shrike from terminal (CLI). 

To do so we will be using mpremote feature of micro-python.

Before getting started with accessing the shrike over terminal you should upload the shrike uf2 board read first two steps from [this](./getting_started.md) guide to learn how to. 

Now we are assuming that you have done those two steps lets connect with shrike over terminal.

We will follow these steps 

### 1. Getting the Py-env and mpremote

Mpremote is a python package and we will have to use pip to install it thus we need to a py virtual env. (if you already have one use that).

Or to setup a python Env read [this](https://docs.python.org/3/library/venv.html) and then activate it . 

Now that your v-env is activated we will get mpremote in the env. To do so run this command 

```
    pip install mpremote 
```
if everything run's without error you have successfully got all the tools to access shrike over terminal however if you face issues then google it or ask in our discord. 

Now lets blink led from the terminal 

### 2. Blinking the CPU led 

To check out how mpremote works we will first blink the led connected to rp2040/rp2350 and then we will flash blink_led bitstream on fpga.

To blink a led on rp2040/rp2350 the python script looks like this save this as a test_led.py file on your pc.

```
from machine import Pin
import time

led = Pin(4, Pin.OUT)  # onboard LED on GPIO 25

while True:
led.toggle()   # switch state
time.sleep(0.5)
```
then we can run this file using the command 
```
    mpremote run test_led.py
```

if you have multiple shrike or rp2040 connected then you need to specify the port number of the board you want to programme something like 

```
    mpremote connect port:<port path> run test_led.py
```
you should see the led blinking on shrike.

You can also access the REPL on the rp2040 by running 

```
    mpremote 
```
now you can python one line at a time. 

### 3. Uploading the bitstream to the shrike.

To flash the fpga with bitstream we need to first upload it to the rp2040 to do that we need to simply run the cp command of mpremote. The bitstream file could be found [here](https://github.com/vicharak-in/shrike/tree/main/test/bitstreams/) get the one corresponding to your board version. 

```
    mpremote cp blink_led.bin : 
```
do not forget the : in the end . Now just run the cmd below to check if the file is copied or not
```
    mpremote ls 
```
lets flash that bitstream to the fpga now.

### 4. Flashing the fpga 

To flash the uploaded bitstream we need to execute this python script 

```
import shrike

#shrike.flash("<bitstream_name>.bin")
# in our case that is 

shrike.flash("blink_led.bin")
```
now you can run this cmd as mentioned in step 2 or you can open the repl and type the python script one by one.

Onces the fpga is flashed you should see the led connected to fpga blinking.

The mpremote has a lot more features as well you can check them all out in there guide [here](https://docs.micropython.org/en/latest/reference/mpremote.html#).

Will also suggest reading this [discussion](https://github.com/orgs/micropython/discussions/9096).

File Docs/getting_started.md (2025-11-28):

(getting_started)=

# Getting Started

In this getting started guide we will see how to blink an led on shrike both on fpga and RP2040.

You can program the microcontroller on Shrike-lite using two methods:<br>
&emsp;**1. Arduino (C/C++)**  
&emsp;**2. MicroPython using the UF2 bootloader**

Both are beginner-friendly, and you can switch between them anytime.  
Let’s follow the steps and get Shrike-lite up and running!

::::{tab-set}
:::{tab-item} ArduinoIDE

# Using it with ArduinoIDE

If you already know Arduino and love working with the Arduino IDE, you can continue using it with Shrike-lite. You do not have to switch to MicroPython unless you want to., 

We will follow these steps to setup our arduino IDE for shrike. If you don't have arduino IDE already ,you can download it from [here](https://www.arduino.cc/en/software/) or if you are using linux(ubuntu)then just run 
```
sudo apt install arduino
```

### Step 1. Adding the board support for RP2040/RP2350

The Shrike has a on board RP2040/RP2350 has a host controller the Arduino IDE doesn't native support them however we can add the board support for the same. 
It is quit straight forward we need to add this URL 
```
https://github.com/earlephilhower/arduino-pico/releases/download/global/package_rp2040_index.json
``` 
in the addition board URL section of arduino IDE which you can find in File->Preferences.

<div align="center">

 ADD BOARD URL

</div>

If you already have another board URL just add a "," between the two URL's.

These board support had been created by [earlephilhower](https://github.com/earlephilhower) and you can check out github [repository](https://github.com/earlephilhower/arduino-pico) for more details.

After adding the URL go to Tools->Boards->Board Manager in the Arduino IDE. 
Then search for pico and the board from Earle F. Philhower. 

<div align="center">

 ADD BOARD

</div>
Perfect we have successfully add the board support for the RP2040/RP2350.

As we discussed earlier, in shrike-lite the micro-controller (RP2040) is responsible for configuring the FPGA.  

To make this possible, we developed a simple mechanism: we store the FPGA bitstreams in the RP2040’s flash memory and retrieve them whenever we need to configure the FPGA.

### Step 2. Adding the LittleFS Tool

The LittleFS library in Arduino allows you to store, load, and update the bitstream in the flash memory through the microcontroller (RP2040).

We need to add a Little-FS utility to bind a bin file (FPGA bitstream with code for Shrike). We can find the utility [here](https://github.com/earlephilhower/arduino-pico-littlefs-plugin/releases/) download the latest release ZIP. 

We will unzip and copy it to the tools directory in Arduino directory.

In case of windows you will find the Arduino folder in C disk if you have not changed it during installation.
In case of linux it would be available in your home directory. 

The directory/ folder  should look like this `<home_dir>/Arduino/tools/PicoLittleFS/tool/picolittlefs.jar`

You will need to restart the Arduino IDE and you should see the Pico Little FS tool like this in your Tools menu.

For more details on the PicoLittleFS tool checkout this [repository](https://github.com/earlephilhower/arduino-pico-littlefs-plugin).

> [!NOTE]
> For Arduino IDE version 2.x.x please follow [this](https://randomnerdtutorials.com/arduino-ide-2-install-esp32-littlefs/) guide instead of step 2 to setup the Little FS tools and you can come back for step 3. 
> Littlefs tool for Arduino IDE 2 can be found [here](https://github.com/earlephilhower/arduino-littlefs-upload).

### Step 3. Installing the Shrike Library 

The Arduino library developed by Vicharak takes care of configuring the FPGA for you. You can install it directly from the Arduino IDE’s Library Manager, just search for **“Shrike”** and install the **Shrike** library.

<div align="center">

 ADD SHRIKE lib

</div>

Choose the first one names as Shrike and not the shrike flash library.
We are almost done with the setup lets continue and blink en led on FPGA using the arduino IDE. 

### Step 4. Programming the FPGA from ArduinoIDE
Lets program out first bitstream to fpga using the arduino. We will be blinking an led.

StartArduino IDE and look for Shrike >- shrike_flash in the example section of IDE and then save it with a name of you choice and at a location of your choice. This will create a folder with the name, now in the folder/dir create a subfolder by name `data` keep the case and in mind. 

Any bitstream that needs to be uploaded to the board should be placed in the folder. 
We have already generated and hosted a bitstream to blink led [here](https://github.com/vicharak-in/shrike-lite/blob/main/test/bitstreams/v1_4/led_blink.bin) save this bitstream to the data subfolder.

Checkout guide to learn how to generate your own fpga design [here](./generating_your_first_bitstream.md).

Onces you have done this go to arduino and hit compile your compilation should finish without error if error occurs don't we have s discord hope on there. 

If the compilation has been done without any error then it's time to connect the board in boot mode " PRESS THE BOOT BUTTON WHILE CONNECTING THE BOARD WITH PC" ( this should be done only the first time of setting up if arduino are if you have programmed the board with any other way last time).

In the tools section select the Board as Generic RP2040/RP2350 based on your board version and flash size as 4MB Sketch:2MB and FS:2MB and CPU Speed as 133Mhz. 

And then hit upload on the board. 

You should see the beautiful blue led blinking on board.

Congratulation you have you arduino IDE and shrike ready to programmed using the Arduino infrastructure. 

>Credit and Gratitude  to [earlephilhower](https://github.com/earlephilhower/) to creating the board support for RP2040/RP2350 in ArduinoIDE and the little FS tool. 

:::

:::{tab-item} Micro-Python

# Using it with Micro-python 

We have created custom UF2 for shrike this contains a shrike.py library that has custom function to flash fpga and few others. You can use the normal rpi micro python uf2 as well however the step's would be different. 

Now we will here safely assume that you will be using our uf2.

### 1. Uploading the shrike UF2

1. Download the uf2 corresponding to your board version from the shrike's [Github](https://github.com/vicharak-in/shrike-lite).
2. Hold the boot button on the board and connect it the your pc now shrike will show up as as storage device.
3. Copy the downloaded uf2 in storage device you can simply drag and drop in mostly all the devices. 
4. After the successful copying the storage device should disappear.

Check the video tutorial on how to upload the uf2 Shrike dev board(its a generic board video and uf2 will differ in our case) [here](https://www.youtube.com/watch?v=os4mv_8jWfU).

Congratulations you have successfully uploaded the uf2. 

### 2. Shrike Mass Storage Device 

Onces that you have copied the uf2 to the Shrike.  The board will disconnect momentary and so up as both a mass storage device and tty/ACM device now the mass storage is the part where you would need to save you bitstream (read step 3). 

The default device ID for mass storage device is `5221-0000` this could be changed as per your choice. 
For windows simply right click and rename for changing the name in linux read [this](https://superuser.com/questions/223527/renaming-a-fat16-volume). 

### 3. Get the bitstream(.bin) for led blink 

To program a FPGA you will require  bitstream file this is much like a firmware for MCU's we will see how to generate these but for now we have uploaded the bitstream required for led_bin you can download them the corresponding to your board's version [here](https://github.com/vicharak-in/shrike-lite/tree/main/test/bitstreams). 

Now that you have both uf2 and bin file settled up lets move forward and upload the bitstream to board.

### 4. Getting the Thonny IDE 

The bitstream can be uploaded on the shrike using one of these two ways 
   1. Using a GUI Based-IDE (Thonny)
   2. Using Command line interface (CLI)

In this guide we will use Thonny however guide to programme using CLI can be found [here](./shrike_cli_guide.md).

Now we will need to get thonny on our pc. Installation is quite straight forward You can download it from [here](https://thonny.org/). 

Now that we have got all the required tools set-ed up let blink some leds.

Open thonny and connect the board to the laptop (do not press boot button this time). And do these two things 
   1. Connect the board from the bottom right corner of Thonny IDE.
   2. Go to file view mode in the thonny to see the rp2040 as a file system.

### 5. Flashing the bitstream 

The bitstream needs to be copied to the Shrike Mass storage part this is a simple copy process same way as copying a file to a USB drive.

Or you can use this way -- 
You should in thonny see both the your pc and rp2040 file's on the left windows now we have to transfer the led_blink.bin file to the rp2040. 
To do so find the file on your system then right click and upload.

Now we will have to flash this file to the fpga to do so we will use the function 

```
    shrike.flash("<your_bitstream_name>.bin")
```

> [!NOTE]
> The bitstream file that you need to copy will be named as "FPGA_bitstream_MCU.bin" found in ffpga -> build -> bitstream folder in your project directory.  
> If you copy any other file present in the bitstream folder the fpga wont be programmed.
> You are free to change the name of this file however you please.

in thonny open a new python file and write this python script 
```
    import shrike
    shrike.flash("blink_led.bin")
```

Save this file to your board (RP2040) and run it. (to run this file on board boot up just name it as main.py)

:::
::::

If everything has been done correctly you should see led blinking on the board.

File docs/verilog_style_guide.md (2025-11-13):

(verilog_style_guide)=

# Verilog Style Guide for Shrike 

The renesas go configure software is a little  different from the vivado or Quartus Prime if you have used them before you will have to take care of these few things while design verilog for the same. 

Just read the log below to know about it.  

## Synthesis attributes 
Yosys used for synthesizing verilog for renesas forge fpga on shrike requires a few synthesis attributes to properly synthesis the design.
These attribute's are related to module hierarchy input output ports and clk;

The main attributes are 

 1. (* top *) -- This is identifier for top module, synthesizer will consider this modules as top module. 

 2. (* iopad_external_pin, clkbuf_inhibit *) -- This should be used for the clk signal so that the yosys creates a clk buffer for this signals path. Use this in only top module. 

 3. (* iopad_external_pin *) -- This needs to be used for every signal that needs to be mapped to the gpio. This the yosys will know not to optimize it or change its name. Only use this for top level io's not in every module.

 An example of all of these used in a i2c top  

 ```
(* top *) module  i2c_blink #( parameter I2C_SLAVE_ADR = 7'h32
		  ) ( 
		(* iopad_external_pin, clkbuf_inhibit *) input i_clk,
		(* iopad_external_pin *) input i_rst,
		(* iopad_external_pin *) input i_scl,
		(* iopad_external_pin *) input i_sda,
		(* iopad_external_pin *) output o_sda,
		(* iopad_external_pin *) output o_led,
		  
		  // ouput enable signal 
		(* iopad_external_pin *) output o_sda_oe,
		(* iopad_external_pin *) output o_clk_en,
		(* iopad_external_pin *) output o_led_en );
 ```

## Output Enable 

The GPIO core of renesas forge fpga requires a select signal for the io mux to select any pin as input or output.
That is every output requires a output enable associated with it and this oe pin should be assigned to 1 whenever we wish to use that pin as output in cases where that pin is not bidirectional and will always be one then enable can be permanently assigned as well.



In case of dedicated input signal you don't need enable the io's as they are by default set to input mode.

## INOUT 

The IDE does not directly support use of INOUT signal type like vivado and other software.
So now the question arises how do to create a bidirectional signal.

We will understand that with a example. Lets say you want to assign a signal named sda as bidirectional then we will to make to separate signal in the completer design they could be named anything but for simplicity lets name them 

```
    input i_sda;
    output o_sda;
    output o_sda_oe;
```

and we will need a third select signal for the mux to switch between input or output . So whenever you require the pin to be output the o_sda_oe signal should be driven high and the corresponding output values should be assigned to o_sda. And for using it as input the o_sda_oe should be driven to low and the input value can be latched from the i_sda.



## clock enable 

The fpga has a internal oscillator connected to the logic fabric and it gives out 50 Mhz clock.

However top module of our design need to have a clock_enable signal for enabling in general cases this signal will always be one. 
Thus this is just a output signal assigned to one in the top module of the design.

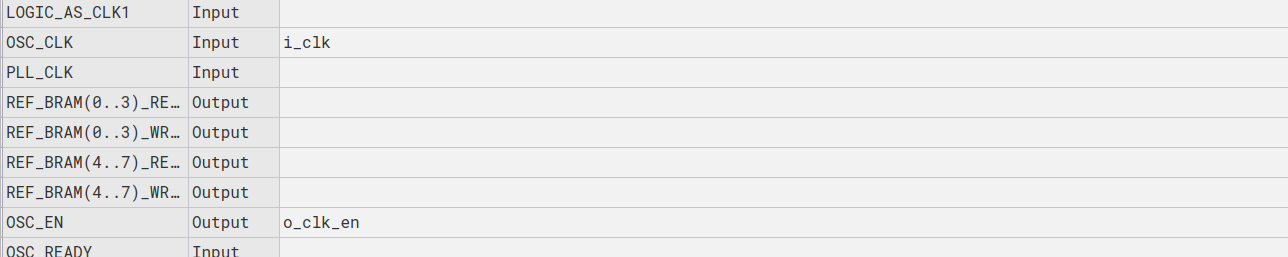
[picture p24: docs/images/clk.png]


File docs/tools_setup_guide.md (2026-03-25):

(tools_setup_guide)=

# Setting Up the tools for Shrike

The shrike  features Reneasas Forge FPGA SLG47910 1120 Luts FPGA and RP2040/RP2350 microcontroller from Raspberry Pi.

 To work with Shrike you will need these 2 software.

   1. Go Configure Software Hub (For Fpga Development)
   2. Thonny IDE (For MCU).

We will install these software on you host machine (computer) one by one.

### 1. Setting Up the Go Configure Software Hub 

Go configure software hub is a free to use tool from renesas however you would need to create a account and login on there website .

Follow these step to get the software.

 1. Open the Go Configure Software Hub page on browser of you choice. The page is linked [here](https://www.renesas.com/en/software-tool/go-configure-software-hub).
   If this link is not working then google search the keywords " renesas go configure hub " and open the first link. You should land here. 

    <div align="center">
    
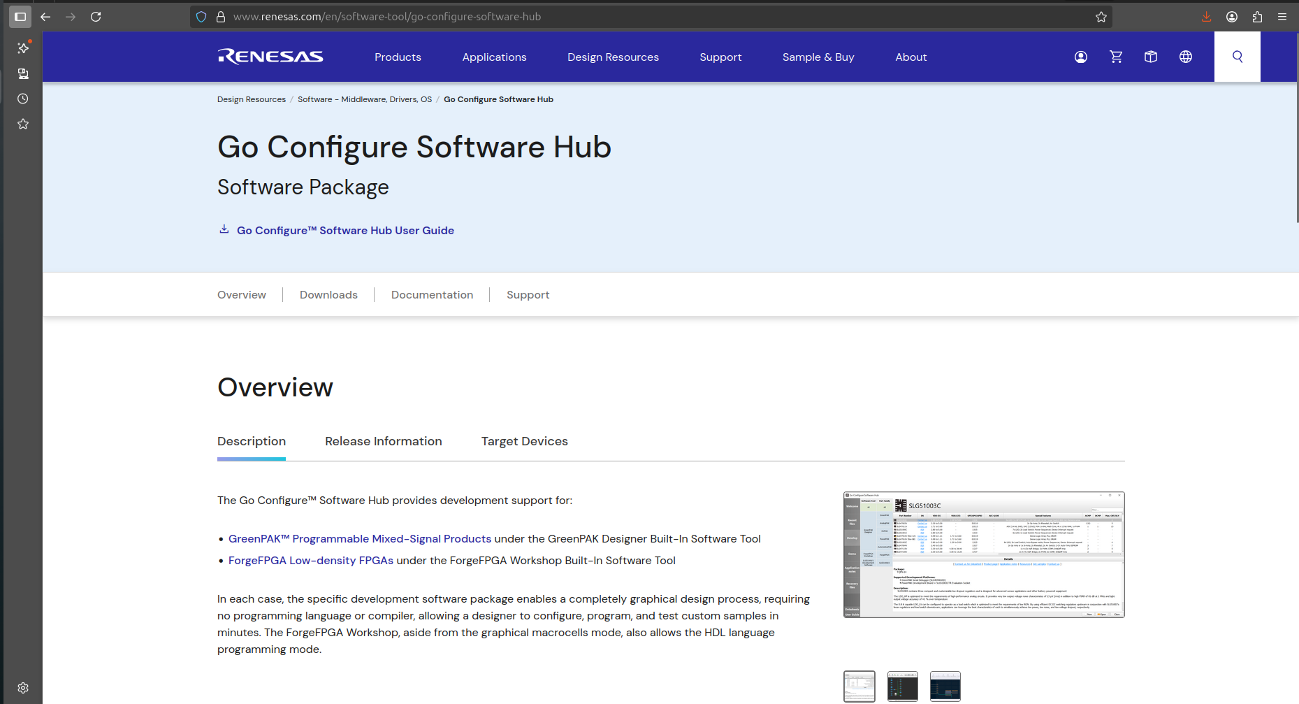
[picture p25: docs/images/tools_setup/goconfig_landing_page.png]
     
    
    </div>

 2. Navigate on the page and click on the link respective to your operating software. 
   
     <div align="center">
    
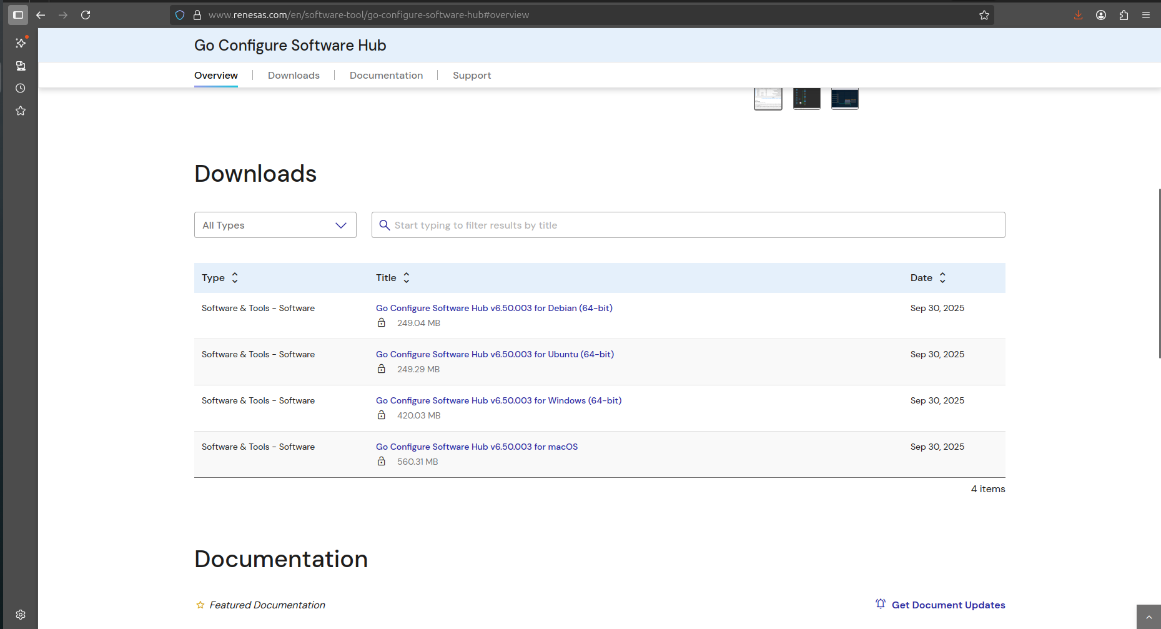
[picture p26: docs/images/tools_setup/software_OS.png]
Go Configure Software Hub
     
    
    </div>

 3. Now it will be asked for you to login or Register. We will have to Register click on the Register button.

    <div align="center">
    
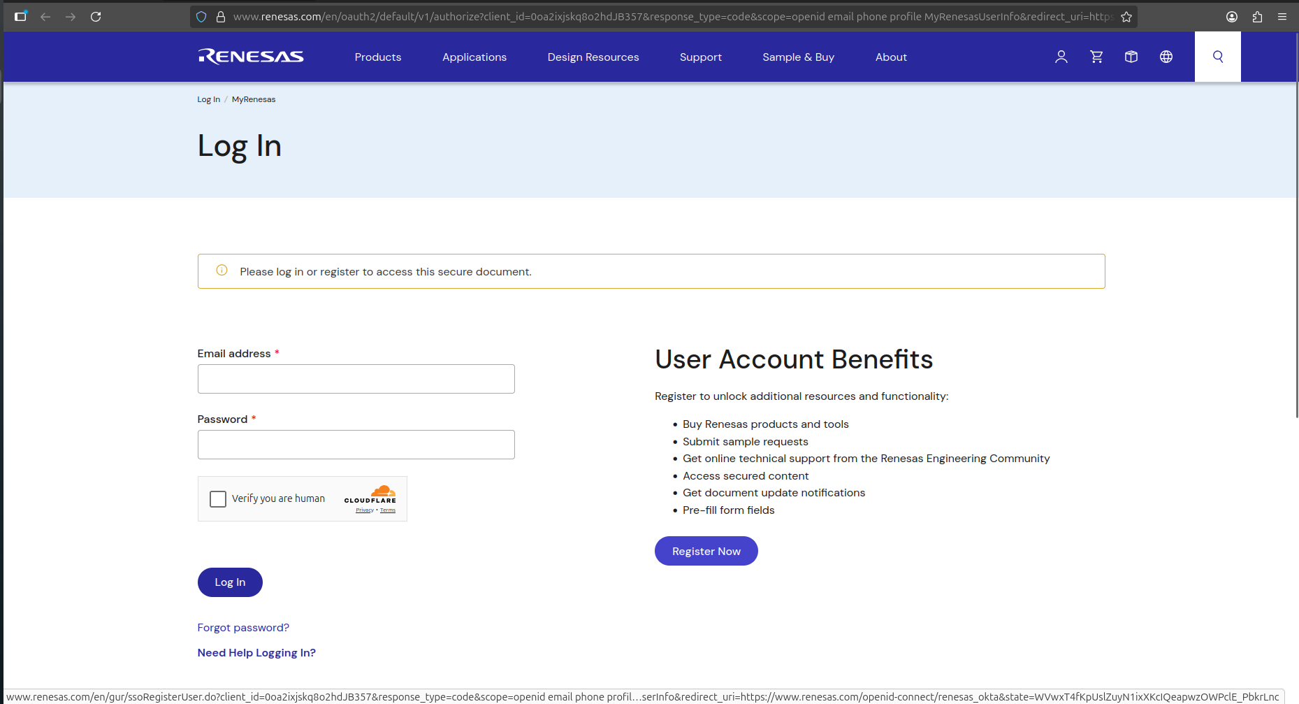
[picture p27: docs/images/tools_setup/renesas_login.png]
     
    
    </div>

 4. Fill all the details here and there would be a email verification and after that your account is good to go.

    <div align="center">
    
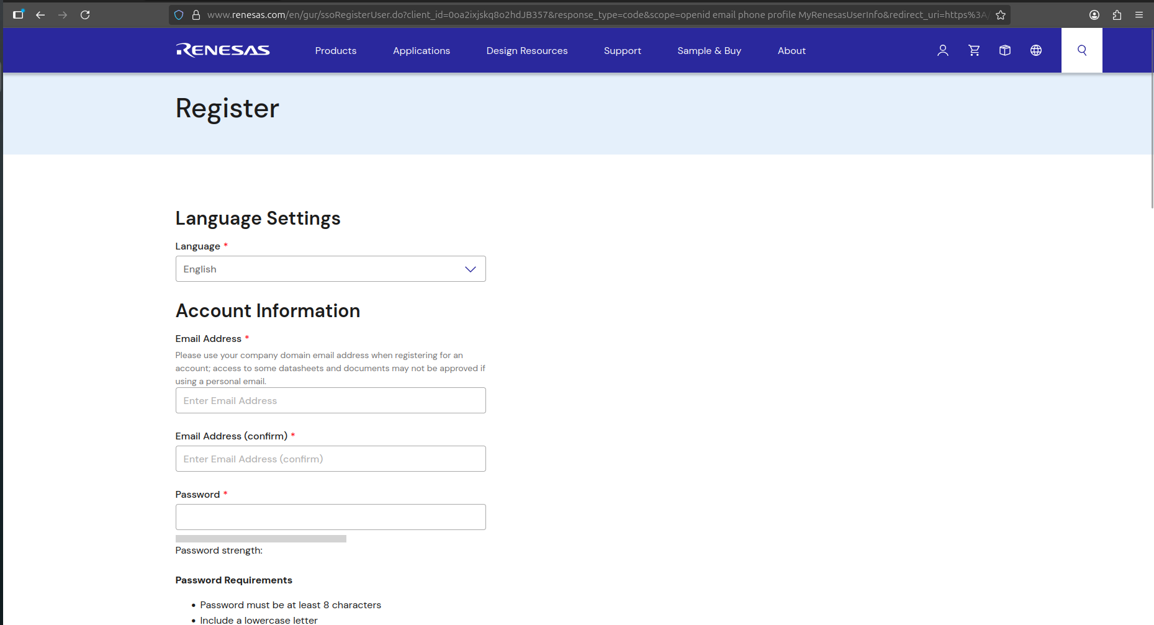
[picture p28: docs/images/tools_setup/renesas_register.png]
     
    
    </div>

 5. Now to this the software page again and click the software link however this time login in with the generated credentials and you the software should start getting downloading if not click on the link onces again. 

 6. Now install the software on my computer.

Congratulations you are one step near to FPGA Development. 

### 2. Setting up Thonny IDE 

To work with RP2350/RP2040/ESP32-S3 side we will need thonny IDE it's officially recommended by the Raspberry pi. 

Follow these steps get Thonny on you computer. 

 1. Visit the offical website linked [here](https://thonny.org/) or just search "thonny" and open first link on search engine. 

    <div align="center">
    
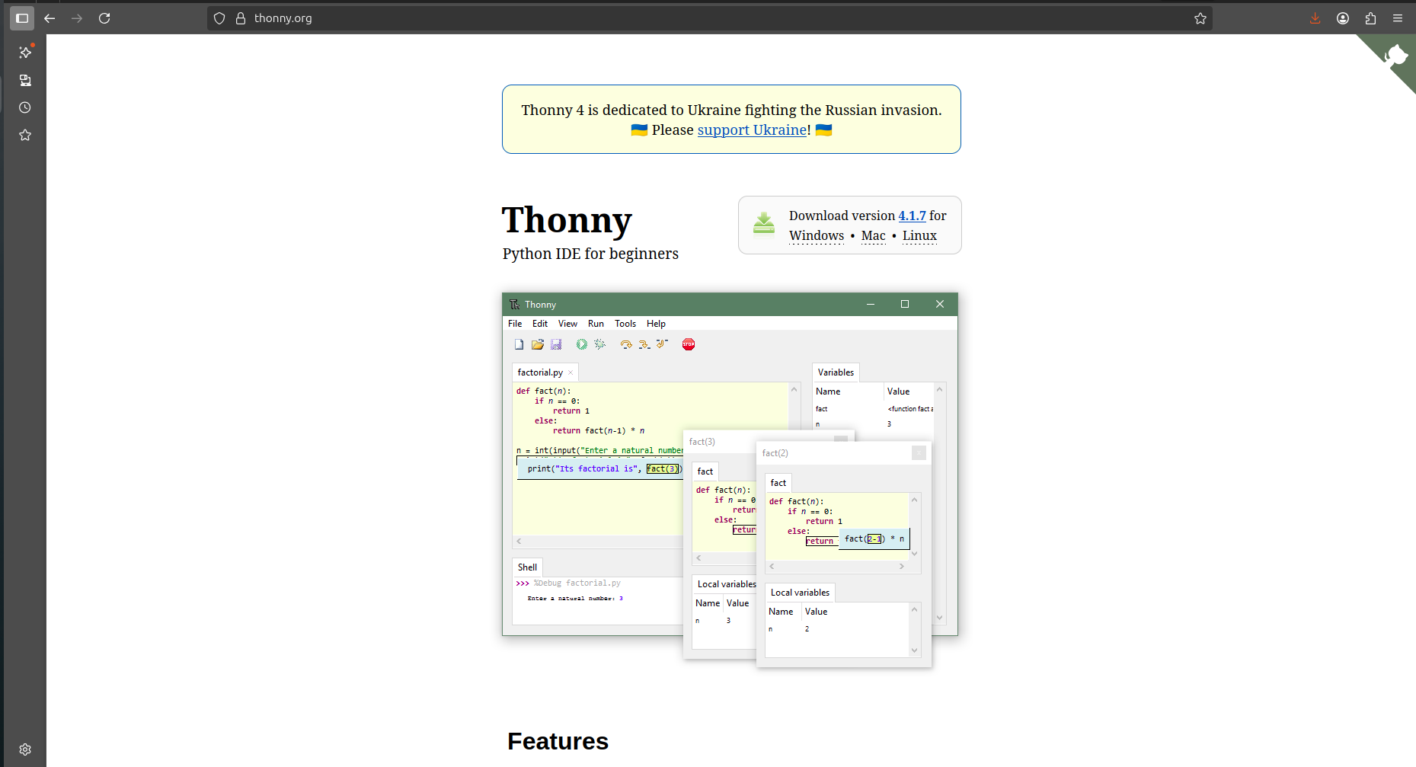
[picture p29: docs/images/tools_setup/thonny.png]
     
    
    </div>

 2. Download the thonny for your OS. 

Note : if you are on Debian, Raspbian, Ubuntu, Mint just Run `sudo apt install thonny` and you will be good to go. 

Congratulations you now have all the tools that you require for developing with shrike.

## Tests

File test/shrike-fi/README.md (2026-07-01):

# GPIO and PSRAM Test Script for Shrike-Fi

This script is used to verify the functionality of the GPIO pins on the Shrike Fi, check PSRAM detection, and determine the available PSRAM size.

## Setup & Execution
### Install Python3 Environment and serial screen tool (Required). If both are already Install then skip.
1. Install Python3 and pip
```bash 
sudo apt update
sudo apt install python3 python3-pip python3-venv -y
```
2. Install pipx (Recommended for tools)
```bash 
sudo apt install pipx -y
pipx ensurepath
```
3. Install ESP Flash Tool
``` bash
pipx install esptool
```
4. Install Pyserial
``` bash 
pip3 install pyserial
```
5. Install screen tool
```bash 
sudo apt install screen  
```

### Cloning the Repository

Clone the repository using the following command:
```bash
git clone https://github.com/vicharak-in/shrike.git
```
Explanation:
This command downloads the project files from the remote Git repository to your local system.

### Nevigate the project directory 
``` bash
cd shrike/test/shrike-fi/
```
### Repository Contents

After cloning, ensure the following essential files and folder are present in the project directory and their functions.

1. ``` flash_test.sh ```
- Flashes firmware to multiple Shrike-Fi (ESP32-S3) boards
- Performs an LED blink test to verify GPIO functionality and checks whether PSRAM is connected to the board.
- Reads .bin file and converts it to byte data
- read data from PC over UART.
- Supports FPGA flashing through ESP32-S3
- Handles multiple boards in a single run

2. ``` test_firmware.bin ```
- Initializes the ESP32-S3 at startup

3. ``` bootloder.bin ```
- Initializes the ESP32-S3 at startup

4. ``` partition-table.bin```
- Defines memory layout (flash partitions)

5. ``` bin_streamer.py ```
- Reads .bin file data from the PC and sends it over serial (UART) to all active ports.

### Follow the below steps to run the script on a Linux system terminal:

1. Make the Script Executable
```bash
chmod +x flash_test.sh
```
Explanation:
The chmod +x command adds execute permission to the script file, allowing it to be run as a program.

2. Allow Port permissions 
```bash 
sudo usermod -aG dialout $USER
newgrp dialout
```

3. Run the Script
```bash
./flash_test.sh
```
"After the setup only run ``` ./flash_tesh.sh ``` command only to Run the script." 

**Important:**
Start serial logging only if ```PSRAM``` is connected.
4. To start the screen log 
```bash 
sudo screen /dev/ttyACM0 115200  
```
**Important:**
* In the above command, replace `/dev/ttyACM0` with the port of your connected device. 
* If multiple ports are connected, open a new terminal window for each port. 
* If no logs are displayed, press the **Reset** button on the Shrike-Fi board to restart the device. The logs will then be displayed from the beginning.

5. To exit the session, press `Ctrl + A`, then type `:quit`. Alternatively, you can disconnect the Shrike-Fi board's USB cable.

## After Run the Script successfully
Open serial_flash_tool folder using command ```cd serial_flash_tool``` and **python file** and **blink_all.bin** in the folder then run Command.

```bash
python3 bin_streamer.py blink_all.bin 
```
Wait until all .bin file (bytes) are fully send on UART; only after the entire transfer is complete FPGA flashing process begin.

**Check that the generated logs match the expected output shown in the Images folder.**

**This script can be used on boards with or without PSRAM.**

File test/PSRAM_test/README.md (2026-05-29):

# PSRAM_test (Shrike-fi)

**Difficulty:** Beginner  
**Uses MCU:** Yes  
**External Hardware:** None

## Overview

This example verifies whether PSRAM is detected on the Shrike-fi (ESP32-S3) board.  
You will learn how to enable PSRAM in Arduino IDE, check availability using `psramFound()`, and print total PSRAM size using `ESP.getPsramSize()`.

## Compatibility

| Board | Firmware | Status |
|---|---|---|
| Shrike-Lite (RP2040) | `firmware/arduino-ide/` |Does not Support |
| Shrike (RP2350) | `firmware/arduino-ide/` |Does not support |
| Shrike-fi (ESP32-S3) | `firmware/arduino-ide/` | Tested |

## Hardware Setup

No external hardware required.

## Quick Start

1. Connect your Shrike-fi board via USB.    
2. Open `PSRAM_test.ino` in Arduino IDE.
3. In **Tools > Board**, select **ESP32S3 Dev Module**.
4. In **Tools > Port**, select the connected device port.
5. In **Tools > PSRAM**, select **QSPI PSRAM** (if not already enabled).
6. Upload the sketch.
7. Open Serial Monitor at `115200` baud.
8. Expected result: PSRAM detection status and size are printed.

### Firmware (Arduino)

1. Open `PSRAM_test.ino` in Arduino IDE.
2. Select **ESP32S3 Dev Module**.
3. Enable **QSPI PSRAM** in **Tools > PSRAM**.
4. Upload to Shrike-fi.

## How It Works

The sketch initializes serial communication at `115200` baud, then calls `psramFound()` to check if external PSRAM is available.  
If found, it reads and prints the PSRAM size in bytes using `ESP.getPsramSize()`. This confirms both detection and usable memory capacity.

## Expected Output

If PSRAM is available:

```text
PSRAM Found
Size of PSRAM: <number> bytes
```

If PSRAM is not available:

```text
PSRAM NOT Found
```

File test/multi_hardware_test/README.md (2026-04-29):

# Test Bed for shrike hardware

### Follow these steps to use 

1. Clone the Shrike-lite Project 
```
git clone https://github.com/vicharak-in/shrike-lite.git
```

2. Change directory to the hardware_test dir in test dir

```
cd shrike-lite/test/multi_hardware_test
```

3. Download the MicroPython UF2 file:
```
wget https://github.com/vicharak-in/shrike/releases/download/v1.0.0/shrike-lite-micropython.uf2
```

4. Execute the setup file 

```
sudo chmod +x setup.sh
sudo ./setup.sh
```

5. Execute the test file 
```
sudo chmod +x multi_shrike_test.sh
sudo ./multi_shrike_test.sh
```

6. Connect all the boards at the same time, and you're ready to go.

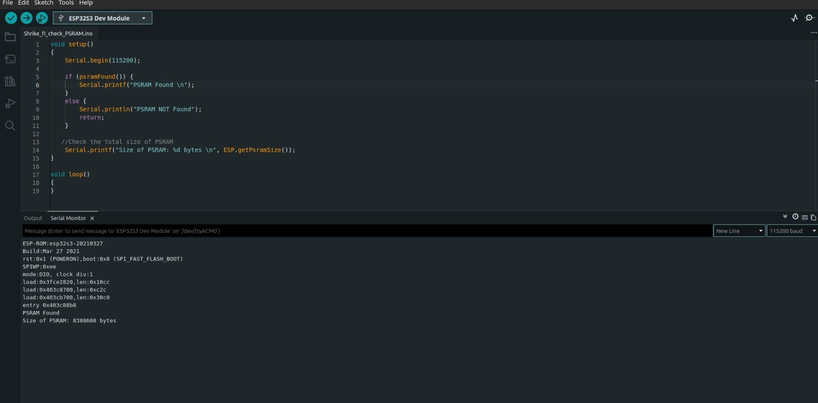
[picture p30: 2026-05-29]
test/PSRAM_test/images/output.jpeg

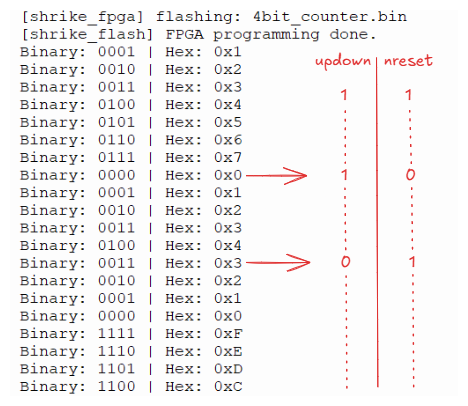
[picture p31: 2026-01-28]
examples/counter_4bit/media/Result.png

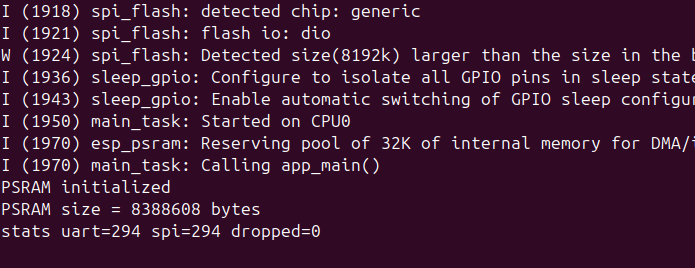
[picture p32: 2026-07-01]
test/shrike-fi/Images/PSRM found.png

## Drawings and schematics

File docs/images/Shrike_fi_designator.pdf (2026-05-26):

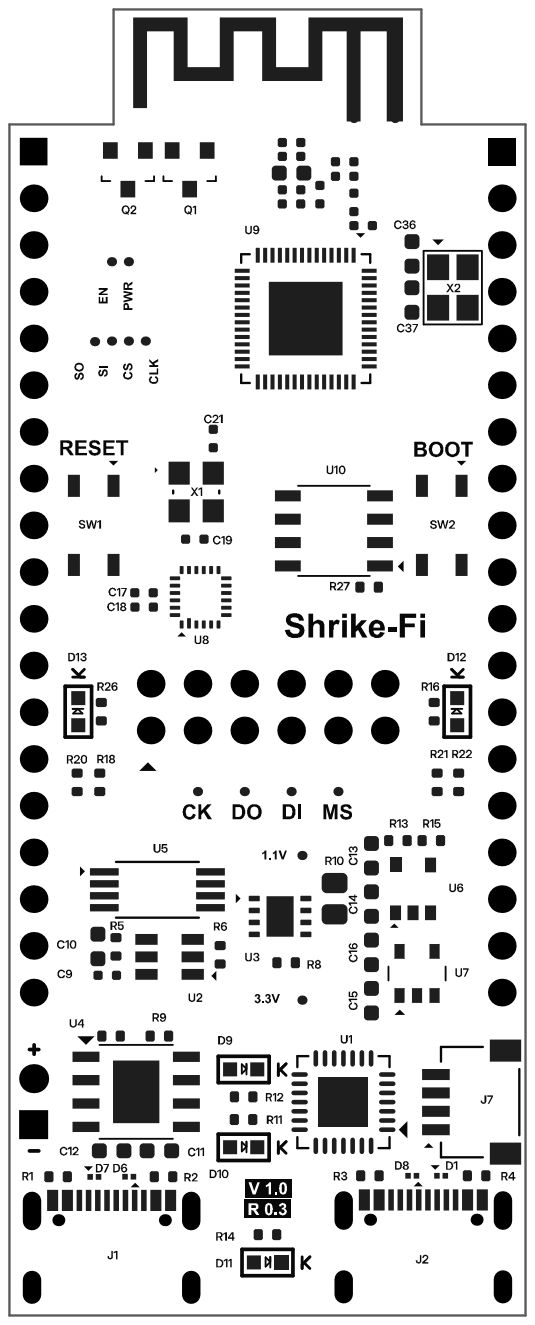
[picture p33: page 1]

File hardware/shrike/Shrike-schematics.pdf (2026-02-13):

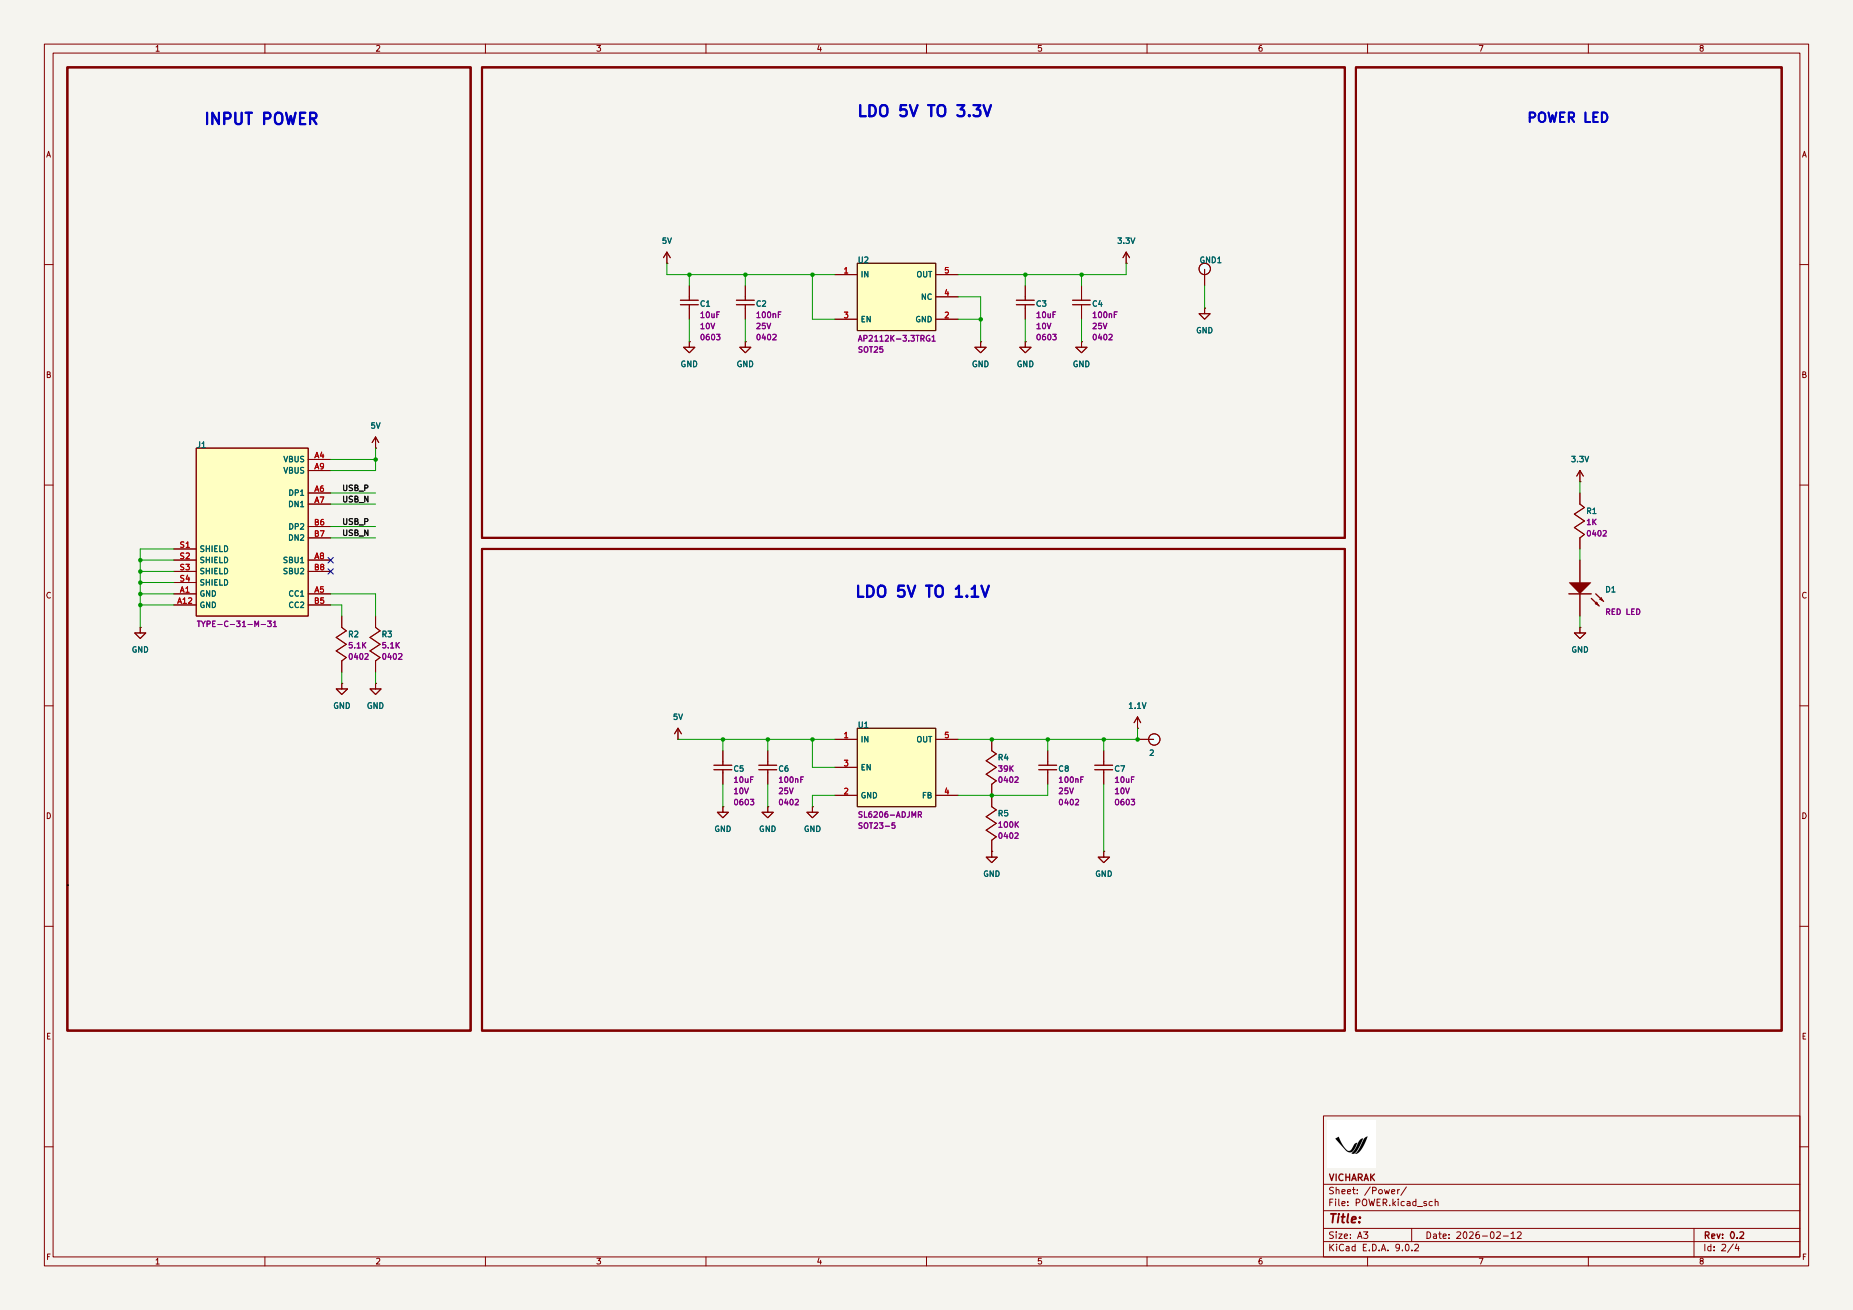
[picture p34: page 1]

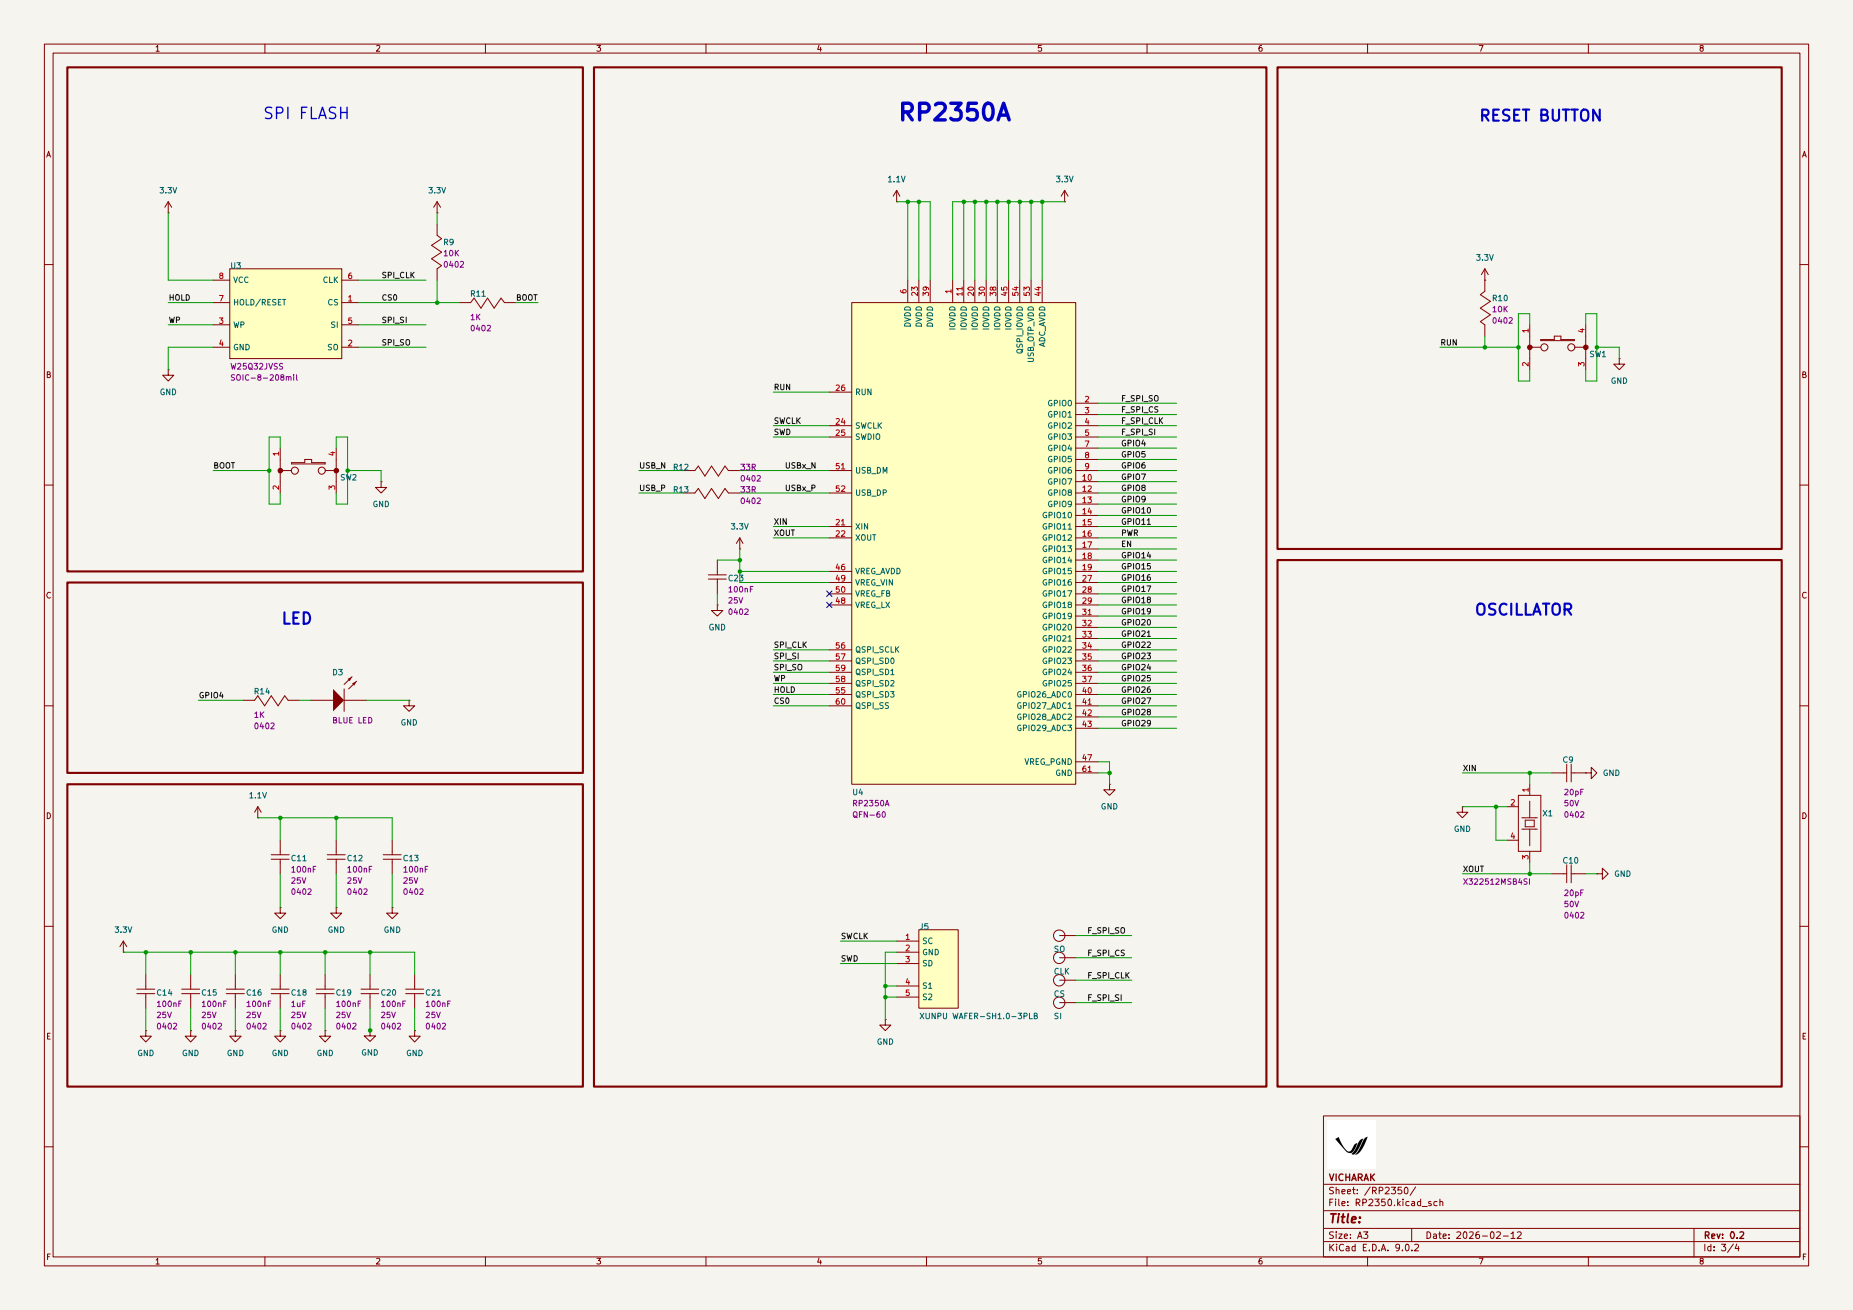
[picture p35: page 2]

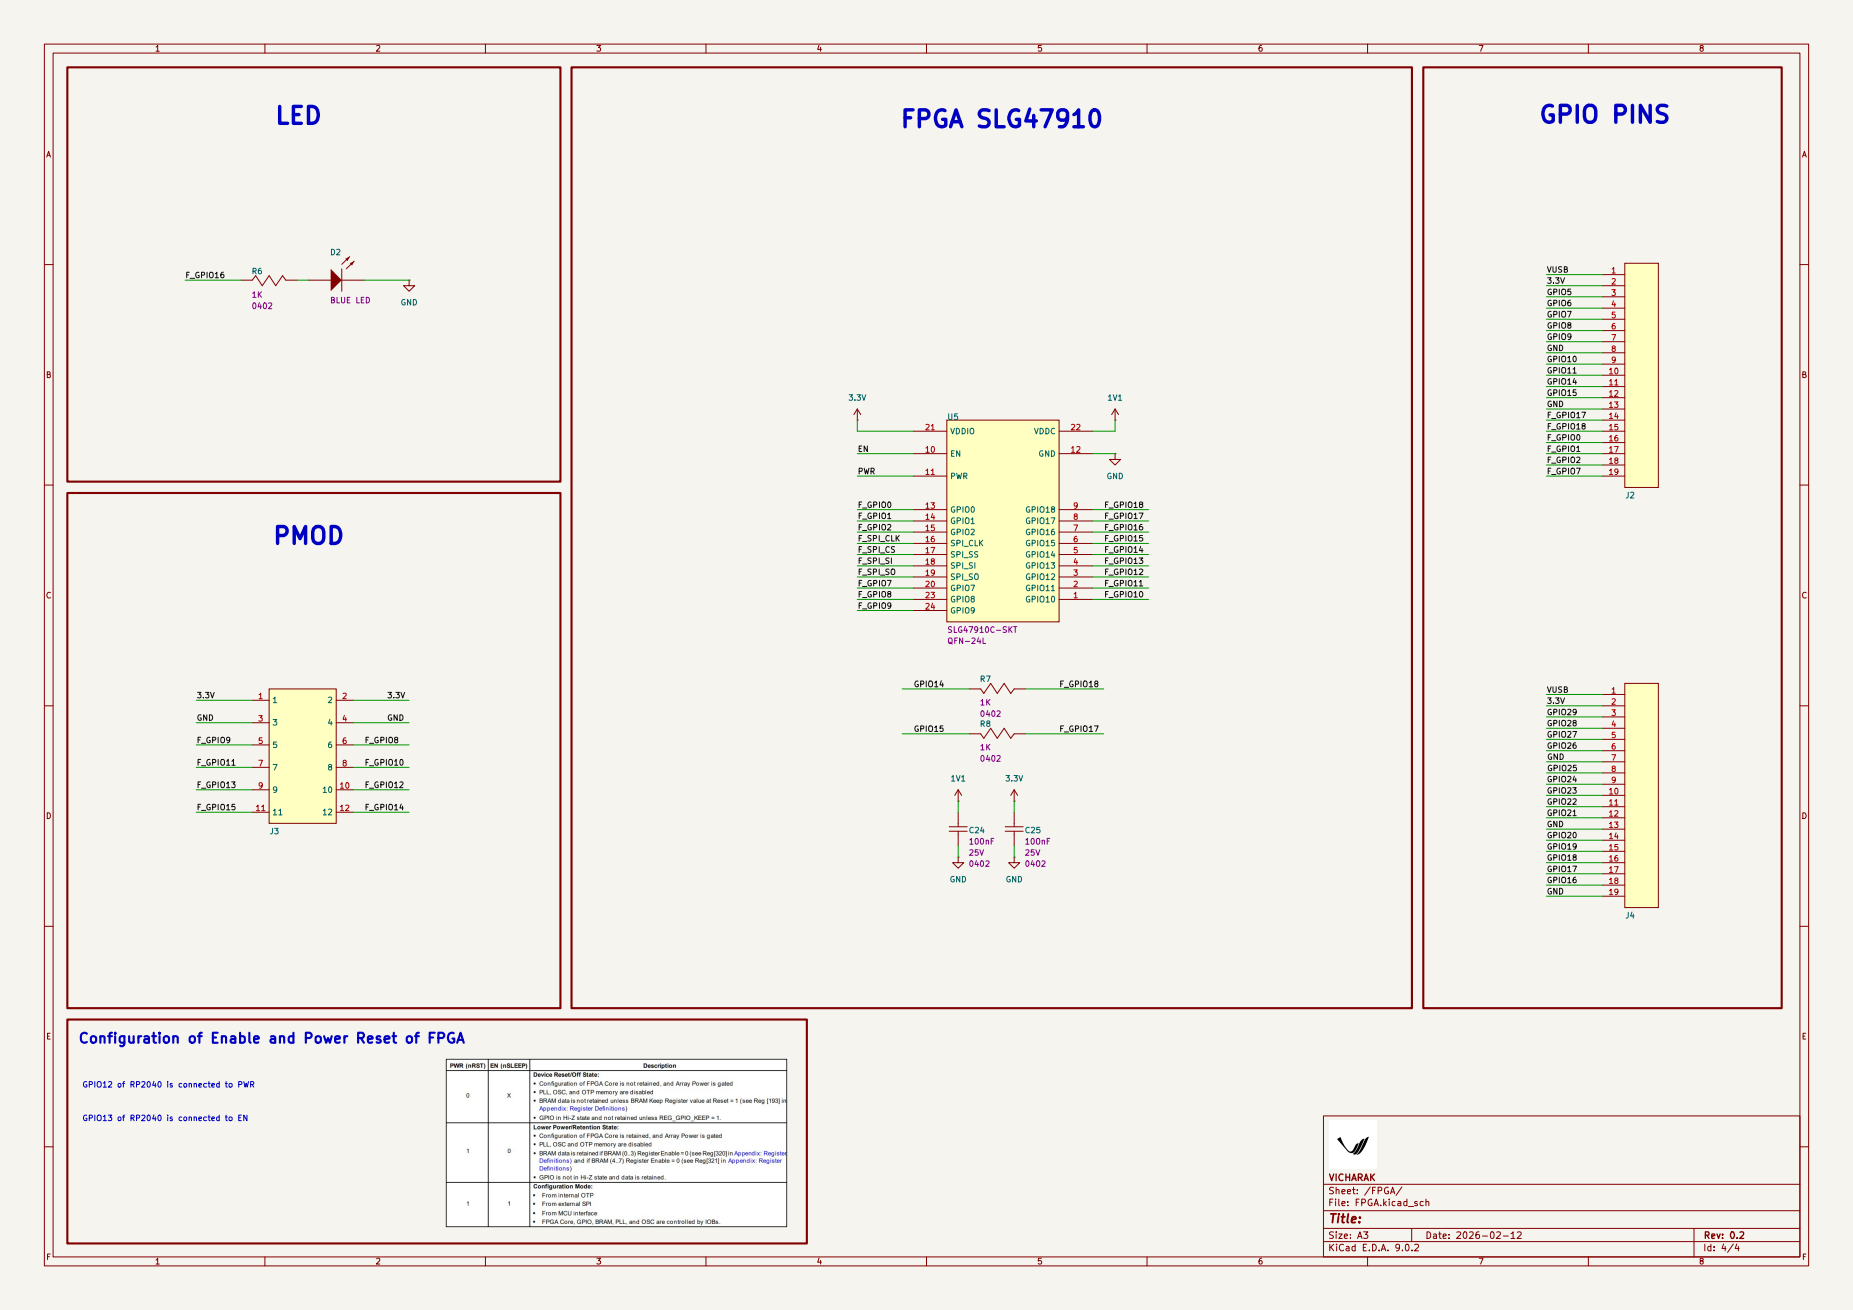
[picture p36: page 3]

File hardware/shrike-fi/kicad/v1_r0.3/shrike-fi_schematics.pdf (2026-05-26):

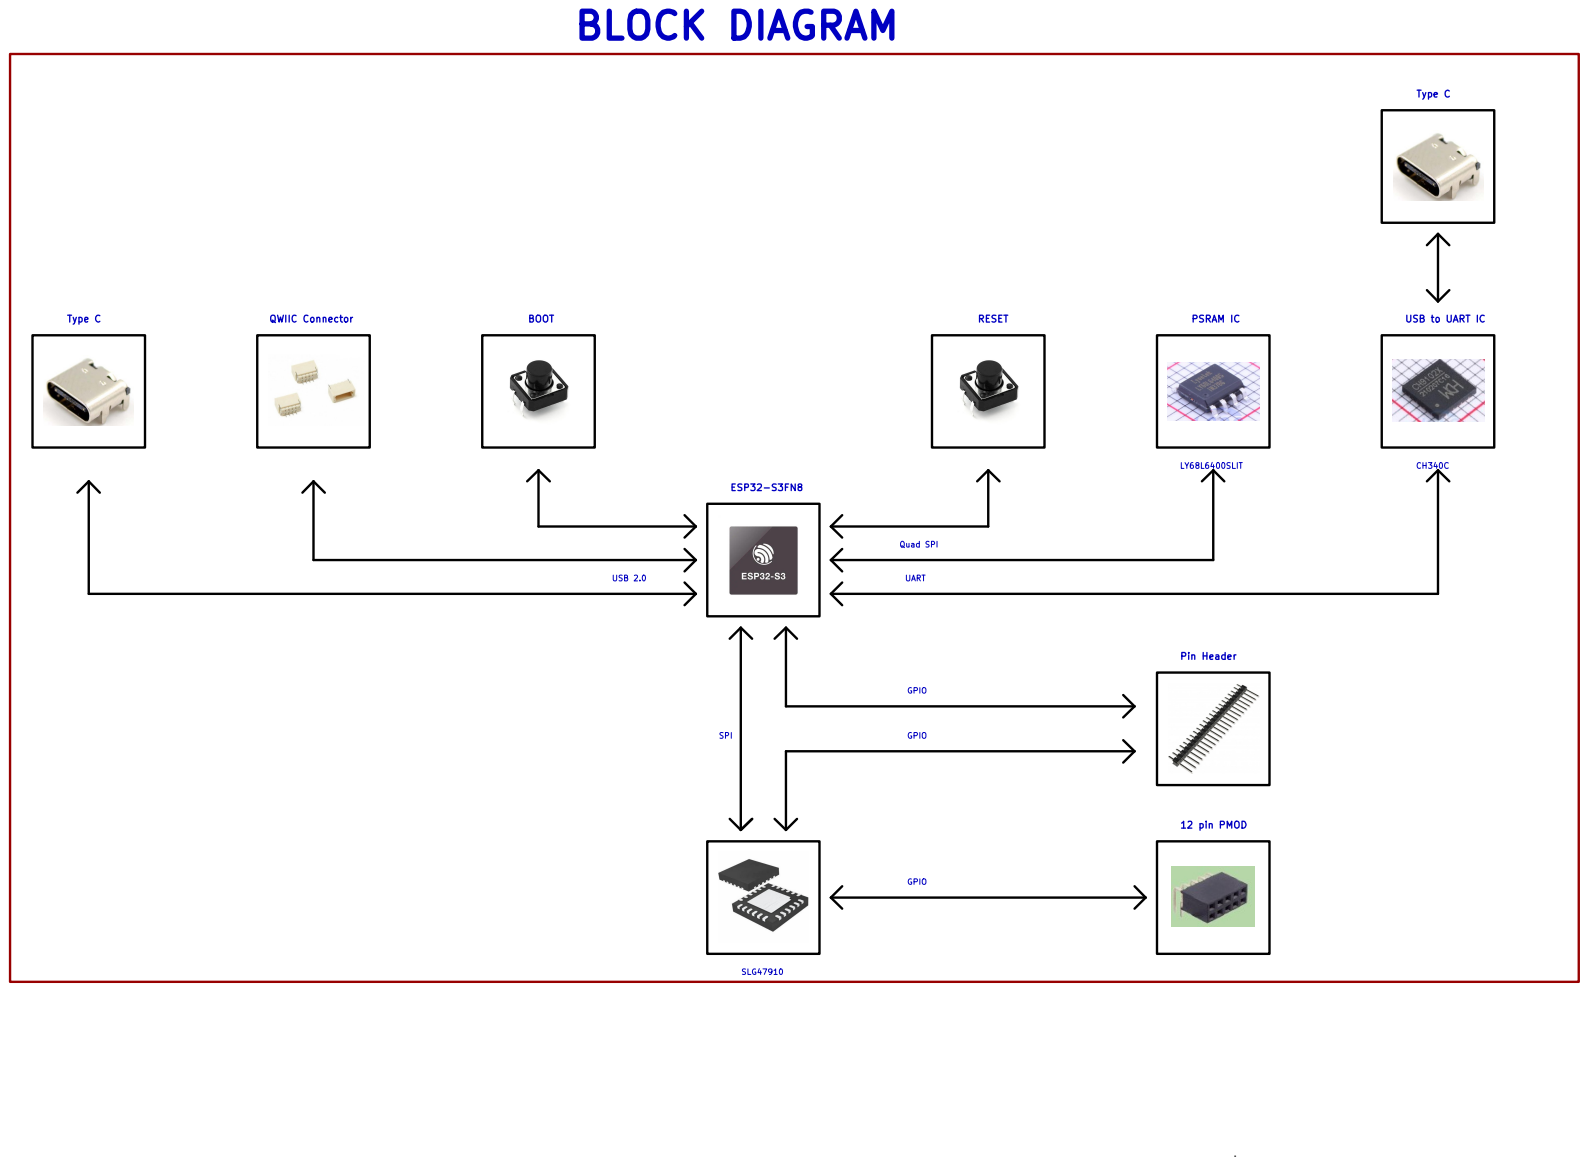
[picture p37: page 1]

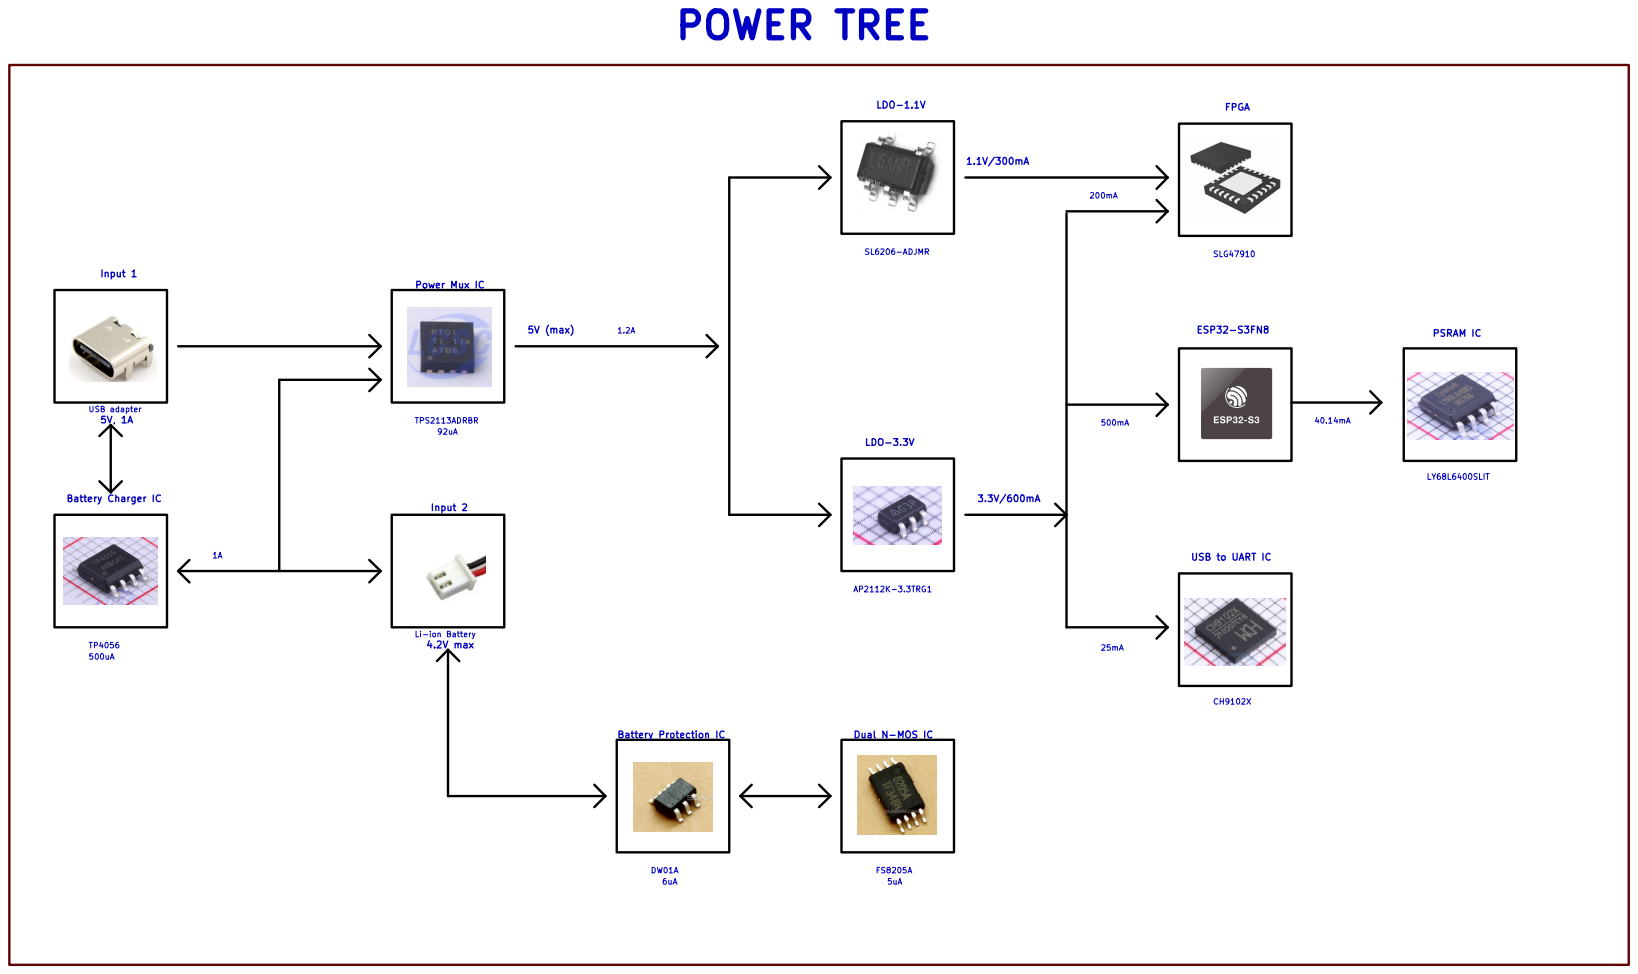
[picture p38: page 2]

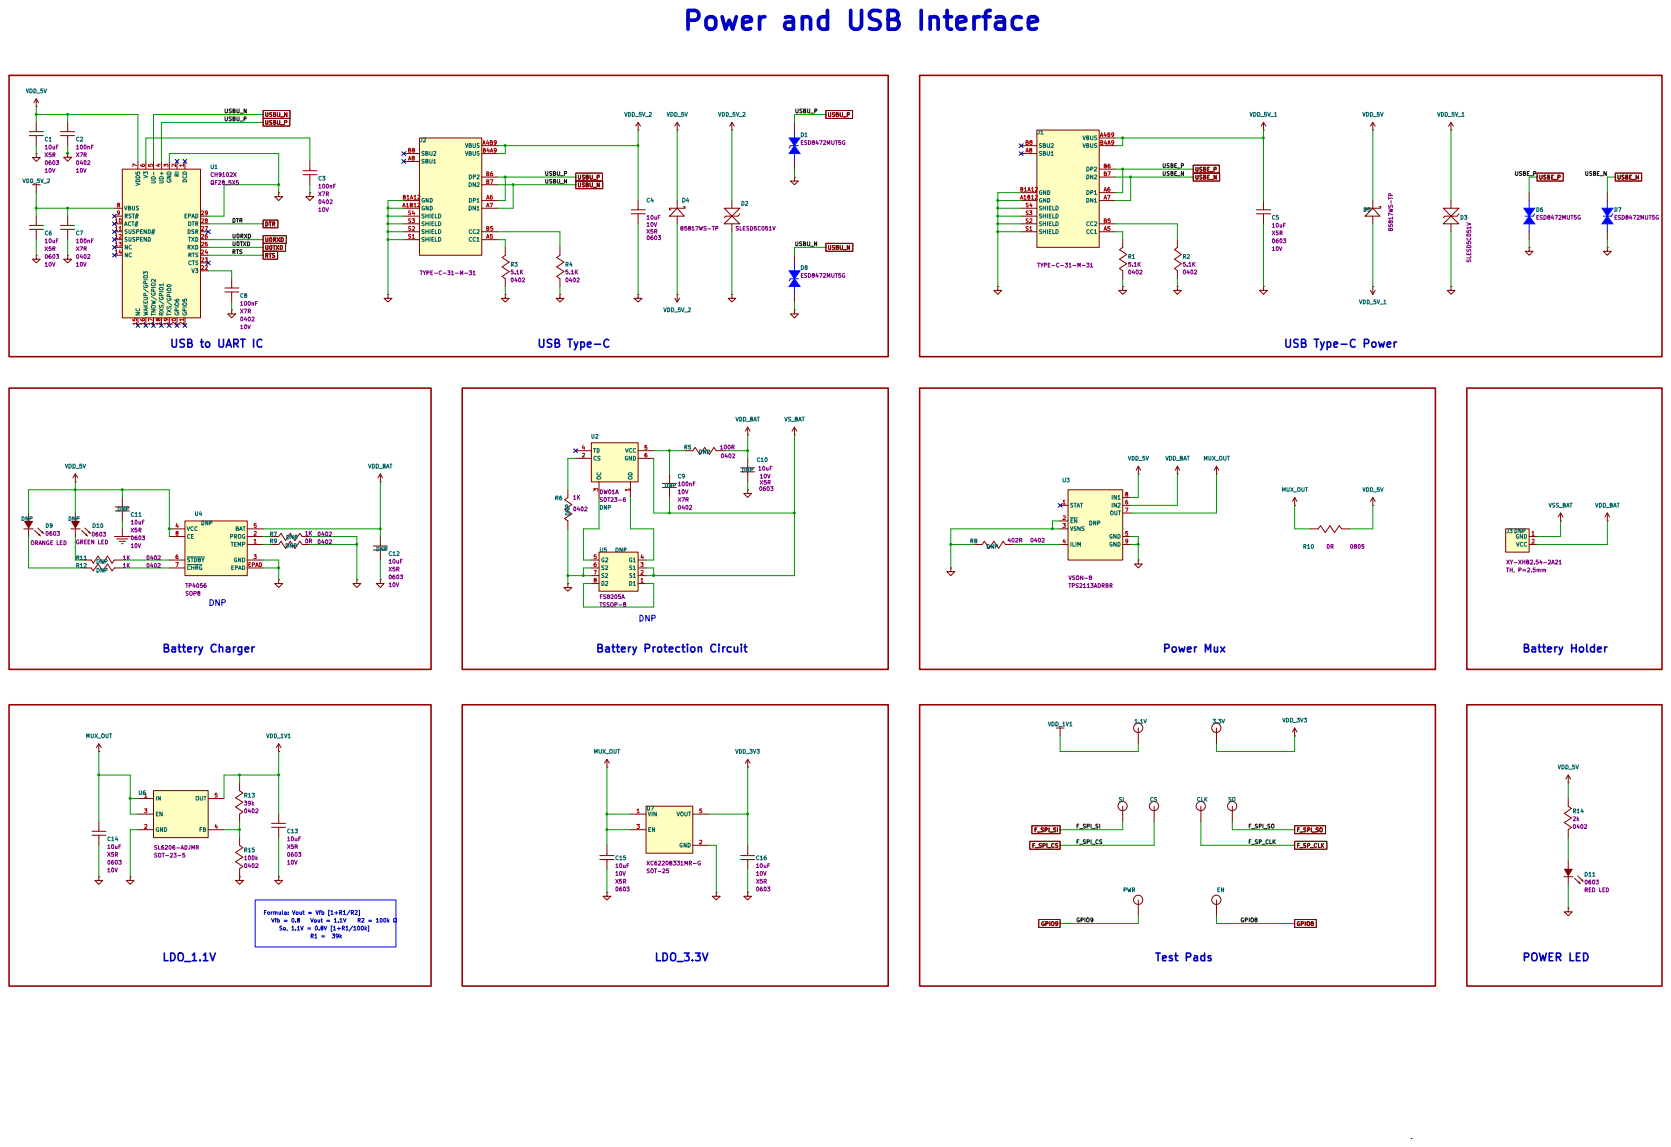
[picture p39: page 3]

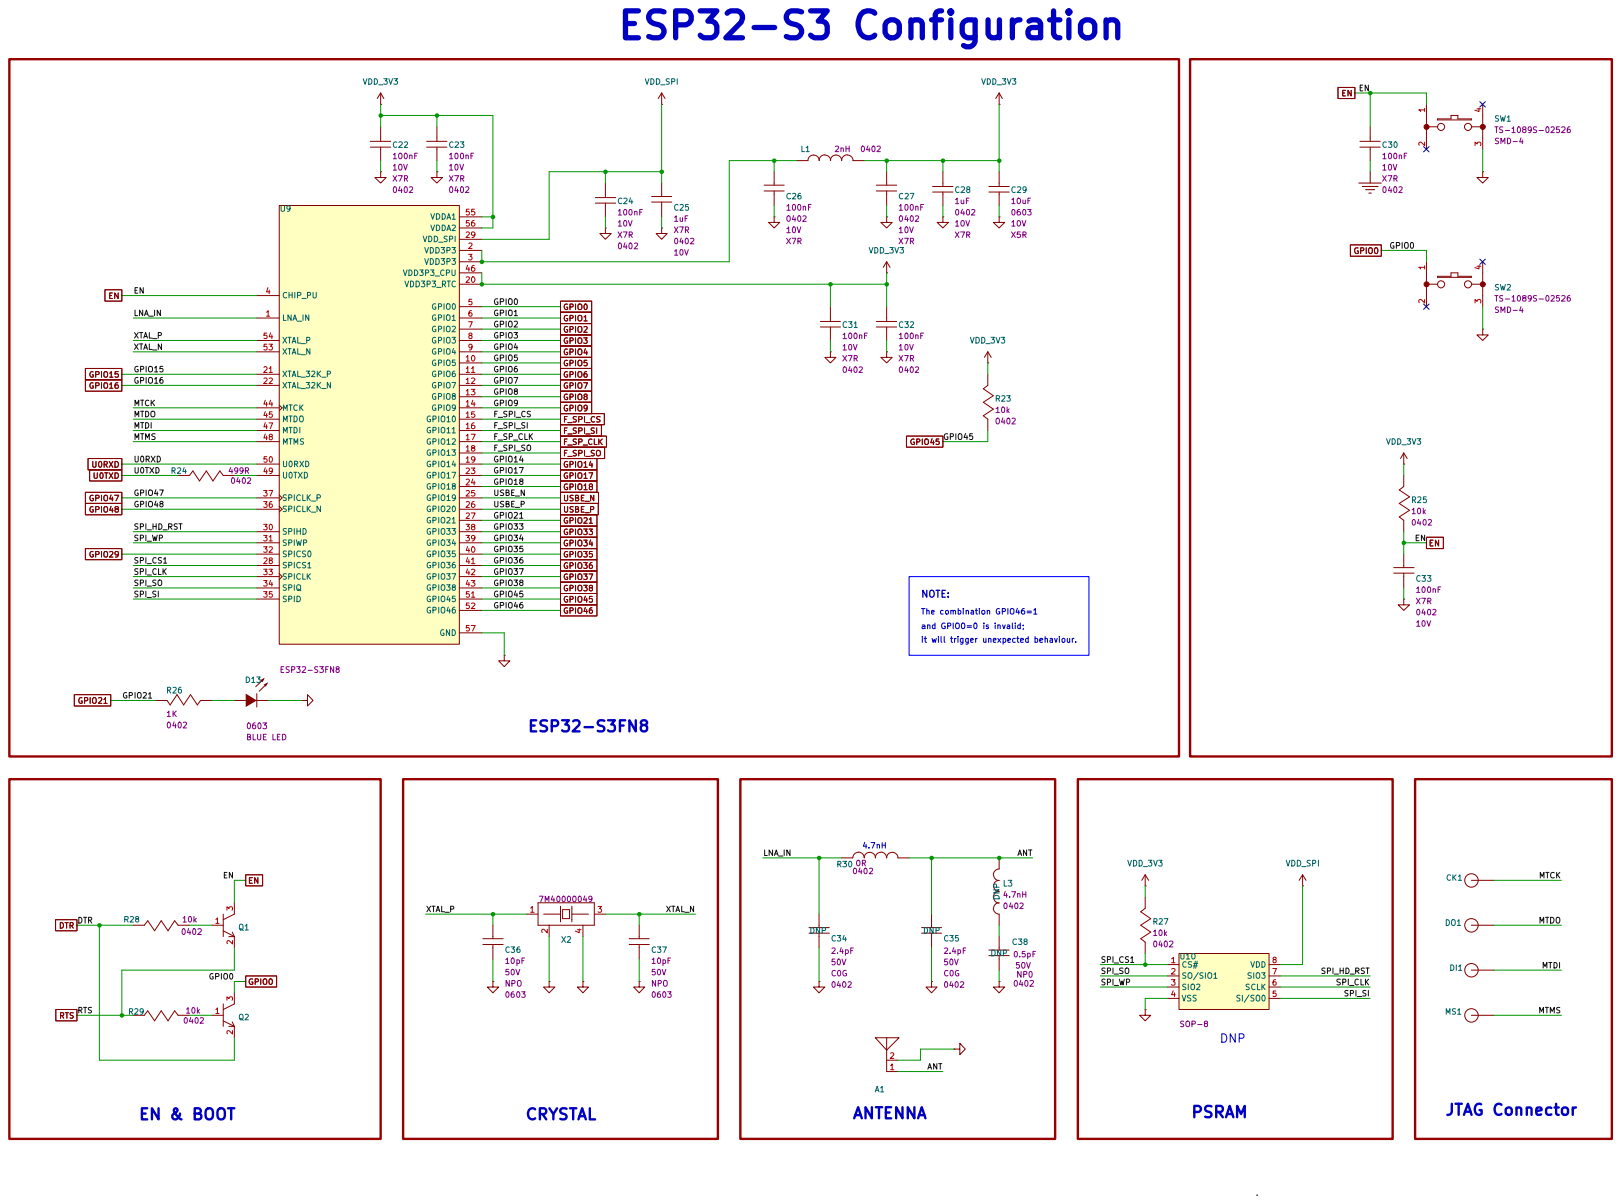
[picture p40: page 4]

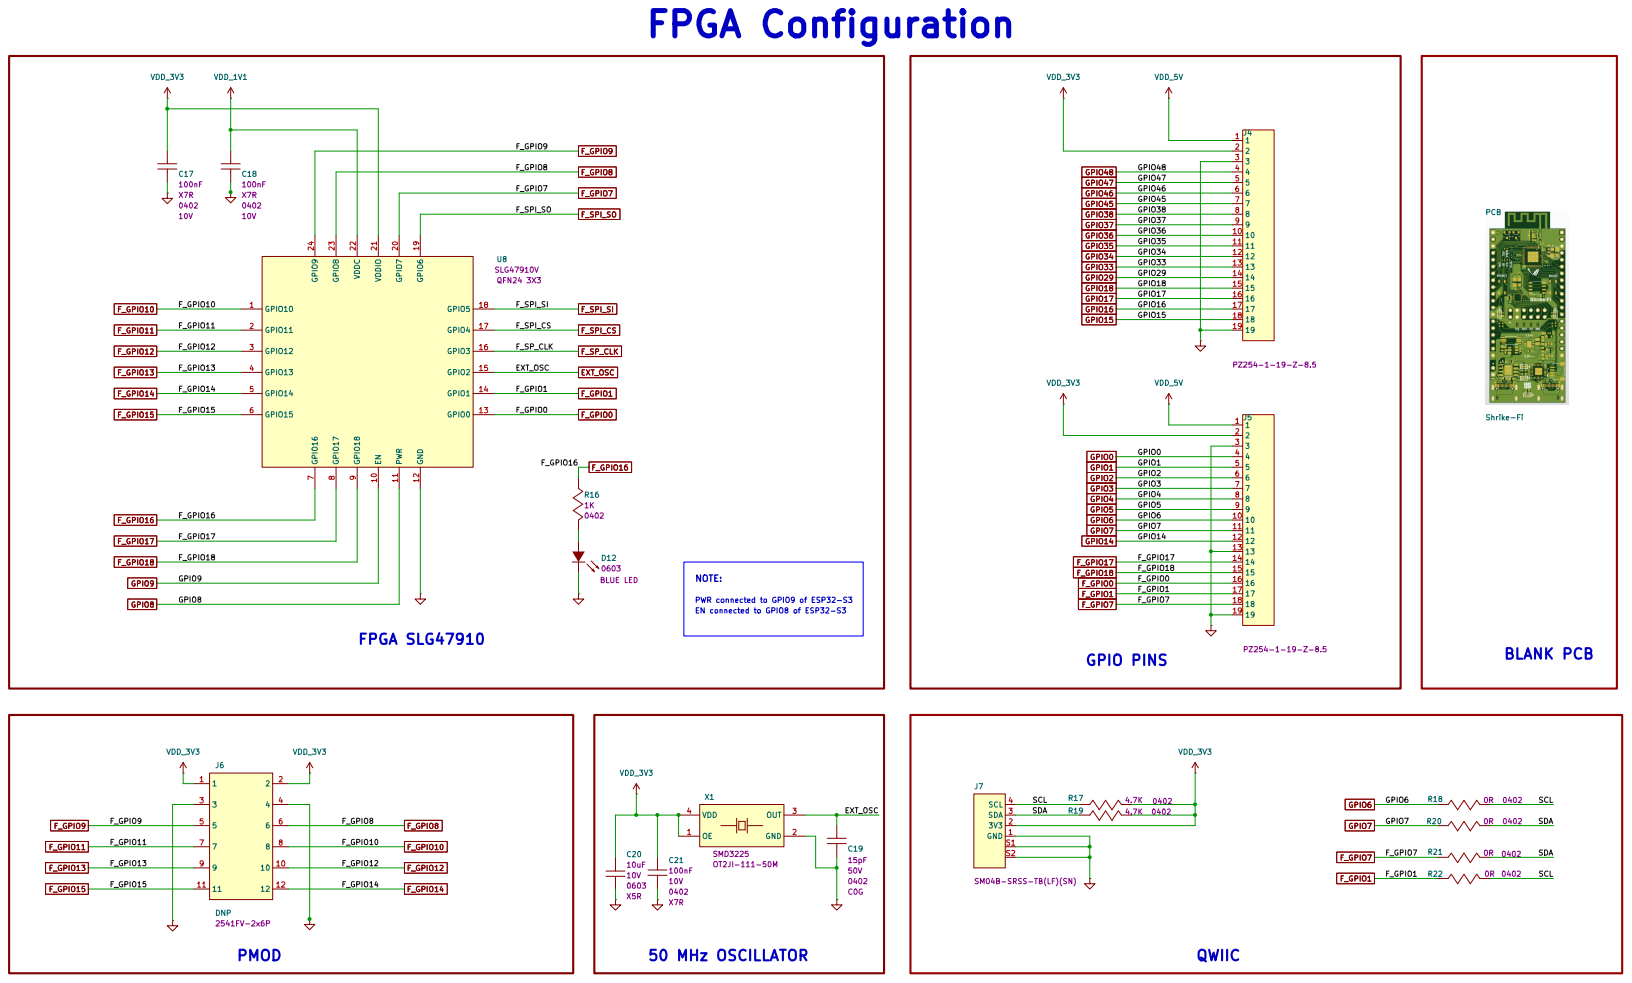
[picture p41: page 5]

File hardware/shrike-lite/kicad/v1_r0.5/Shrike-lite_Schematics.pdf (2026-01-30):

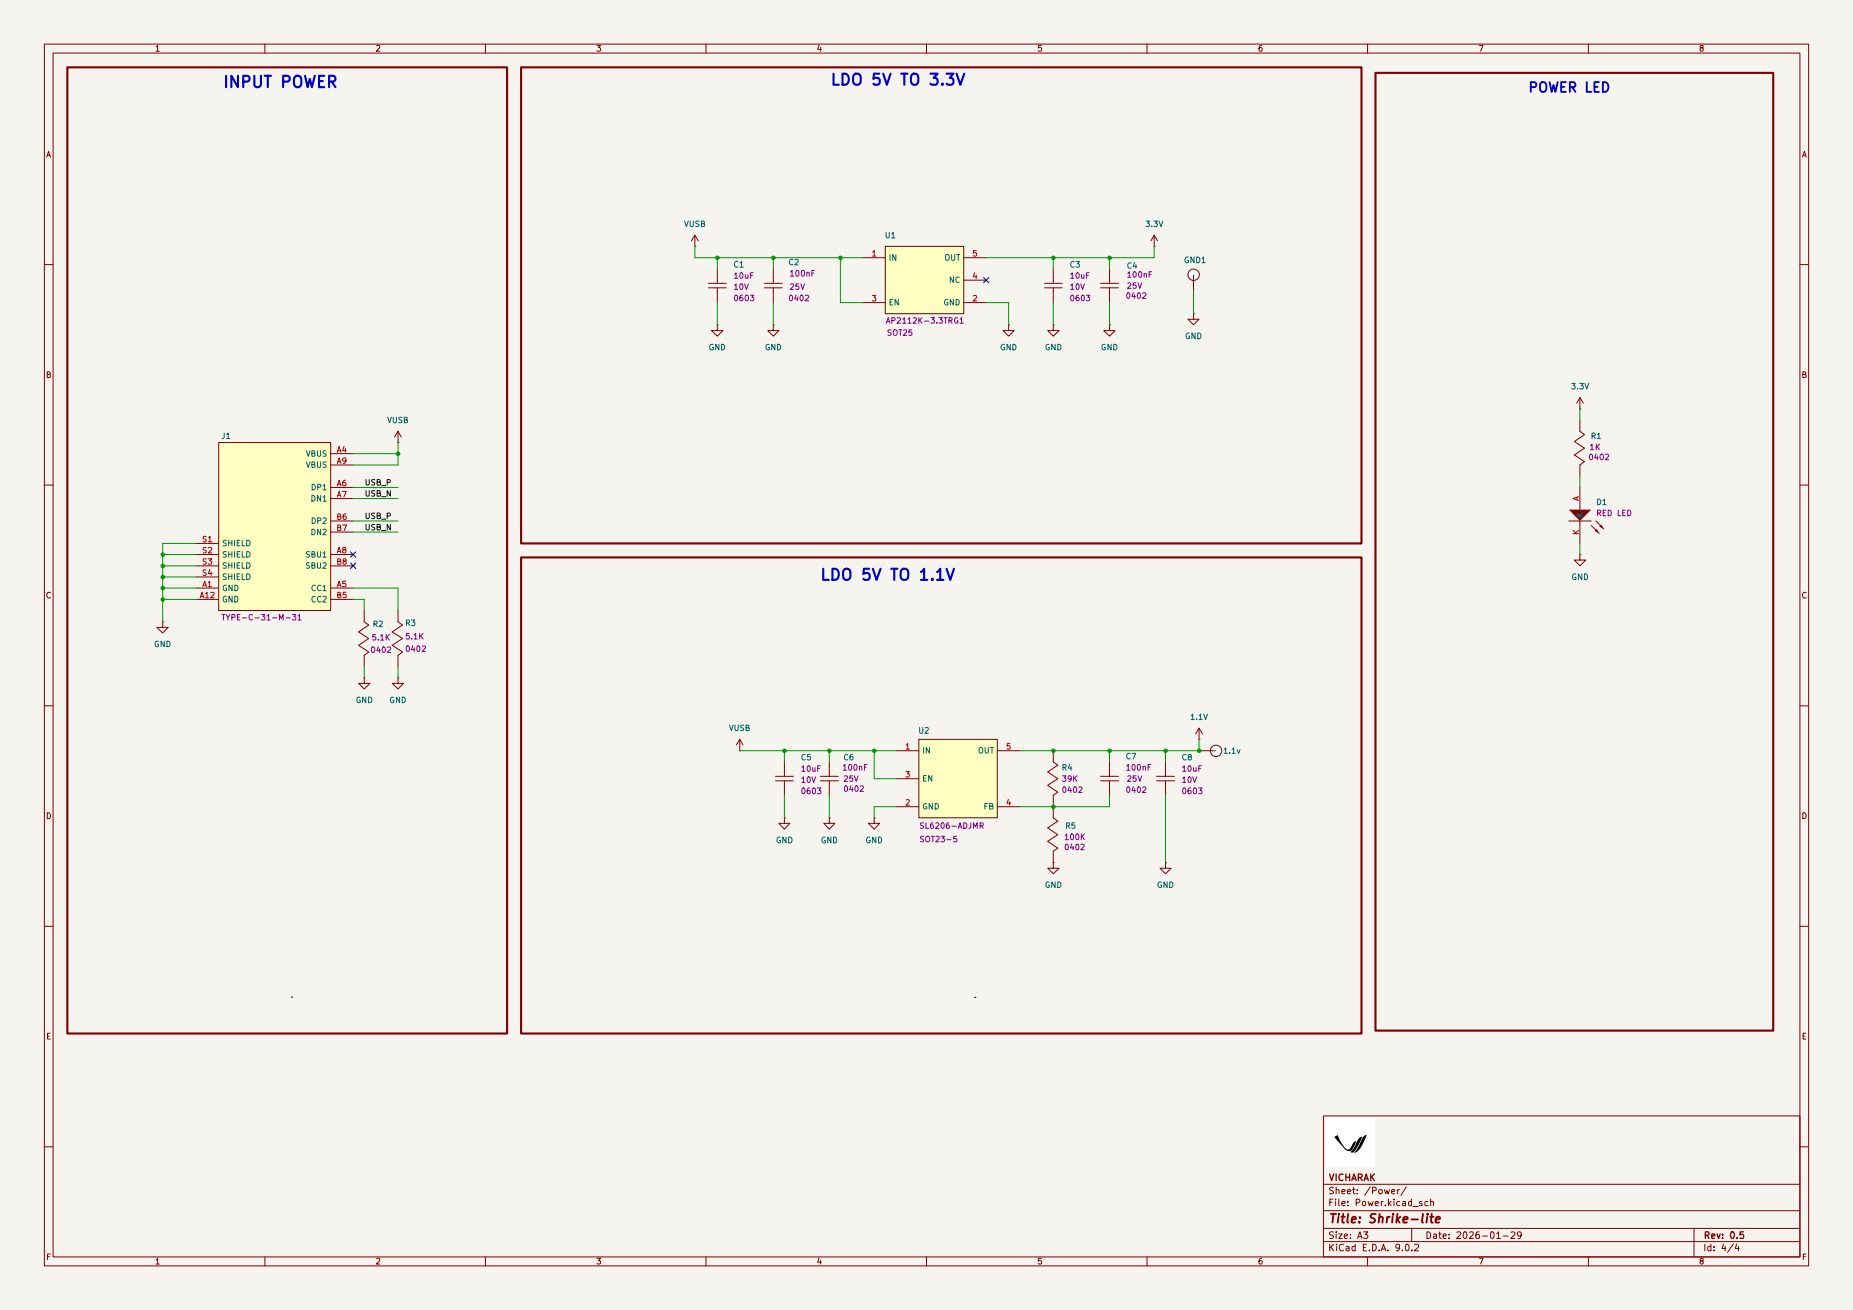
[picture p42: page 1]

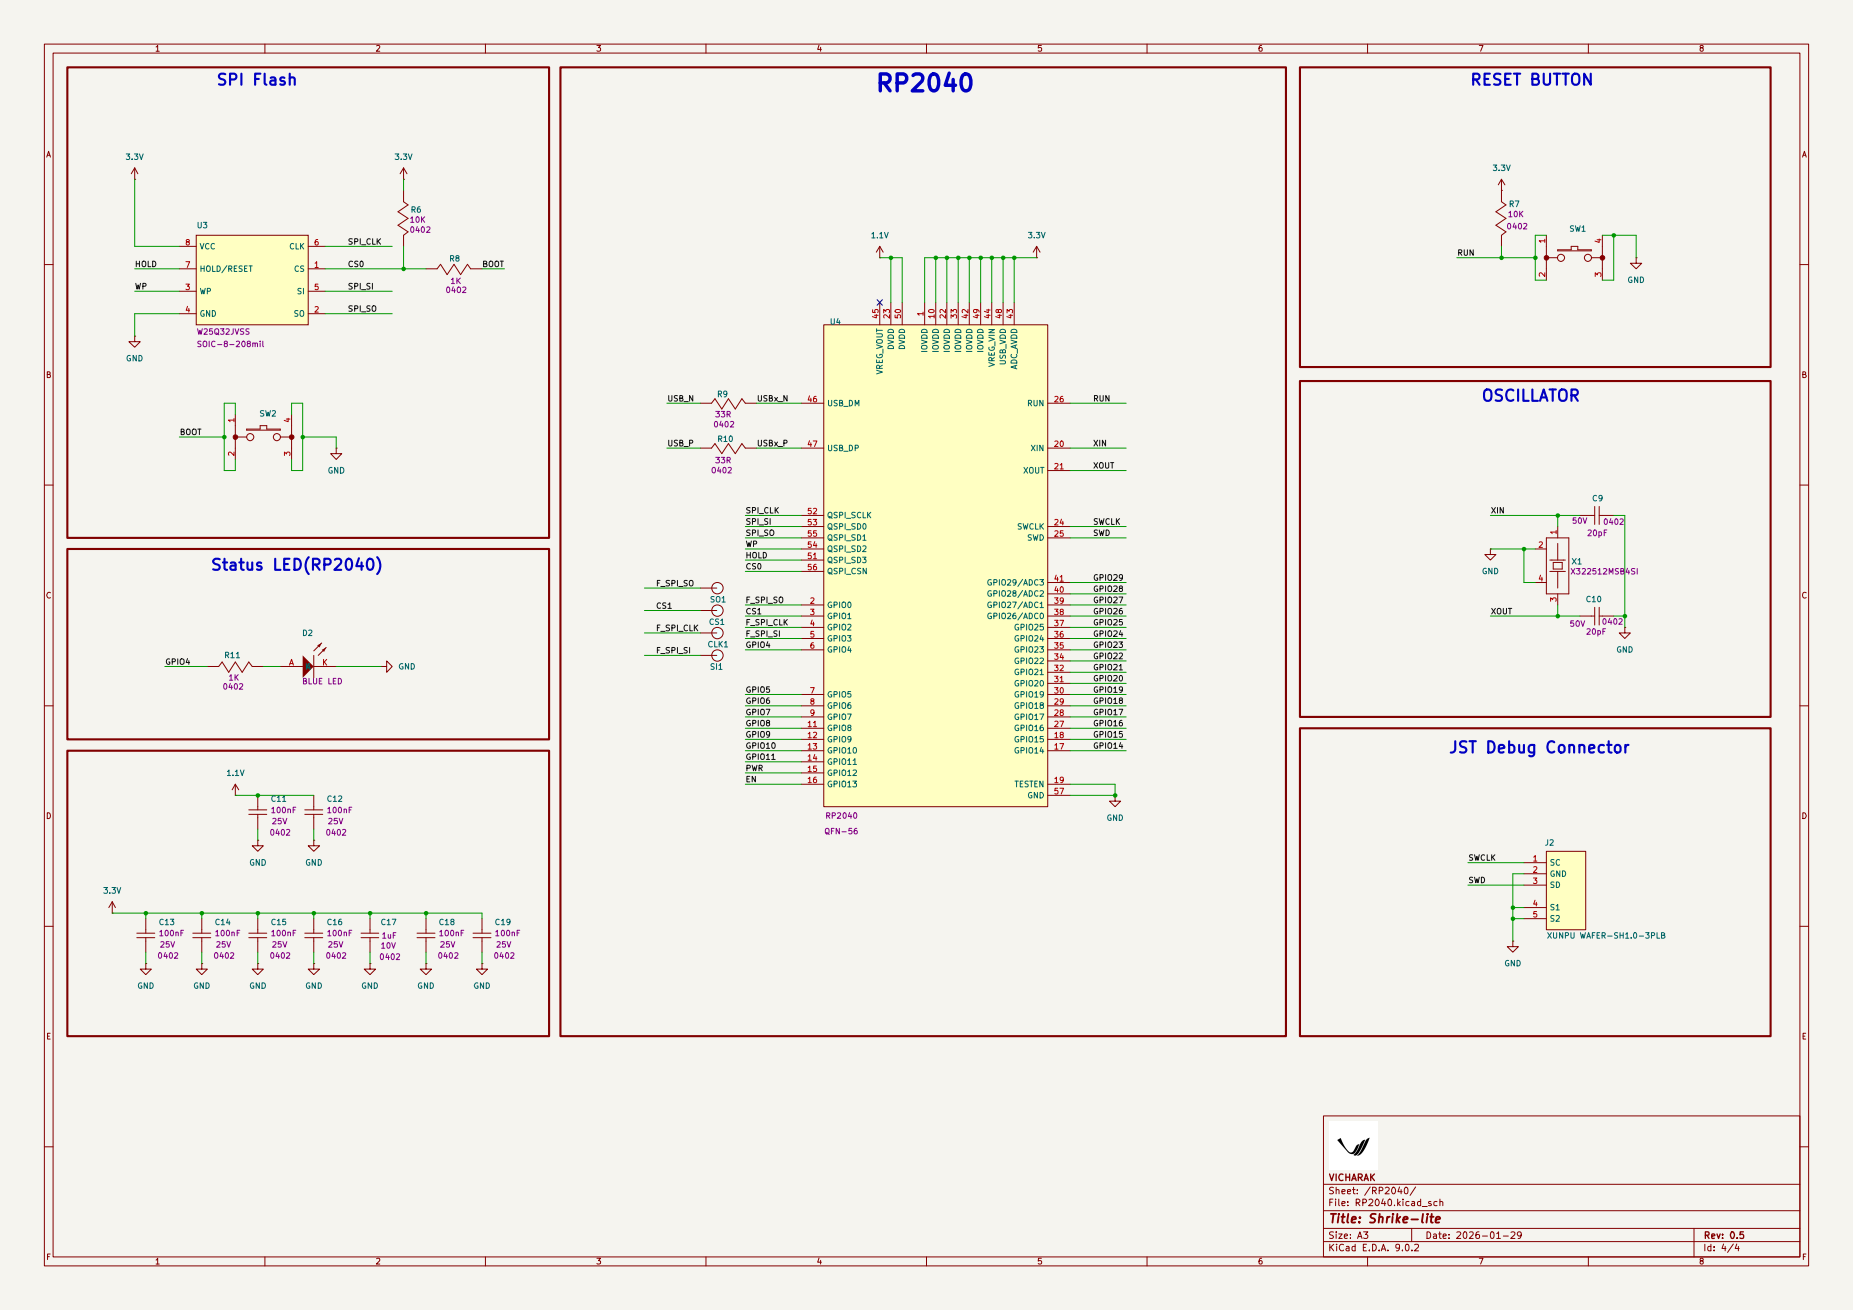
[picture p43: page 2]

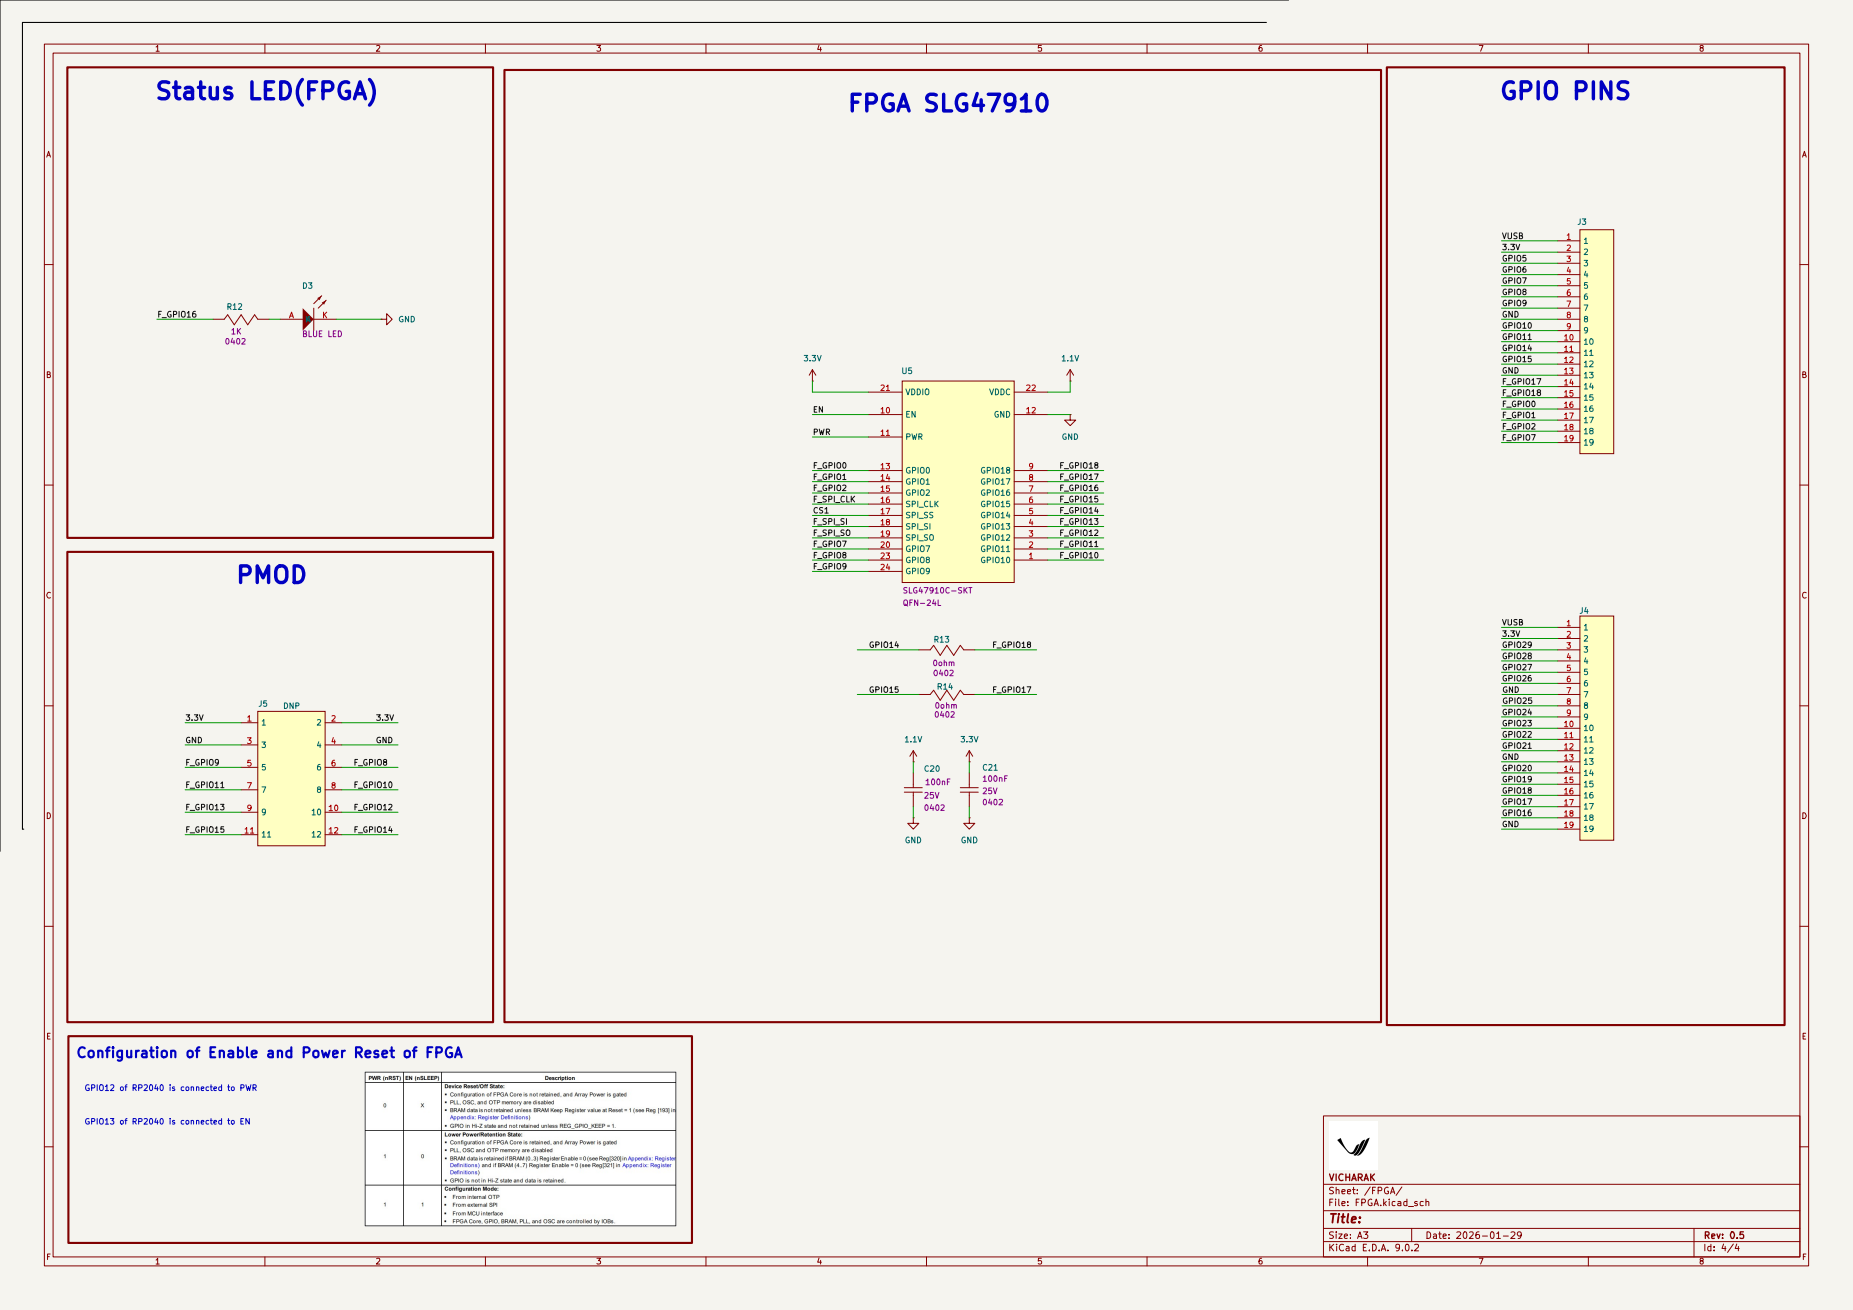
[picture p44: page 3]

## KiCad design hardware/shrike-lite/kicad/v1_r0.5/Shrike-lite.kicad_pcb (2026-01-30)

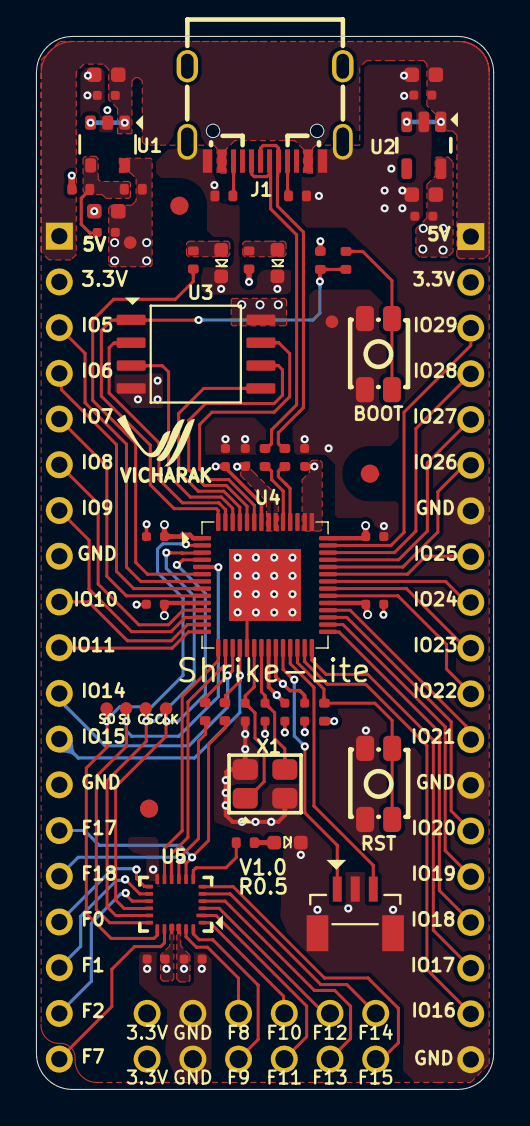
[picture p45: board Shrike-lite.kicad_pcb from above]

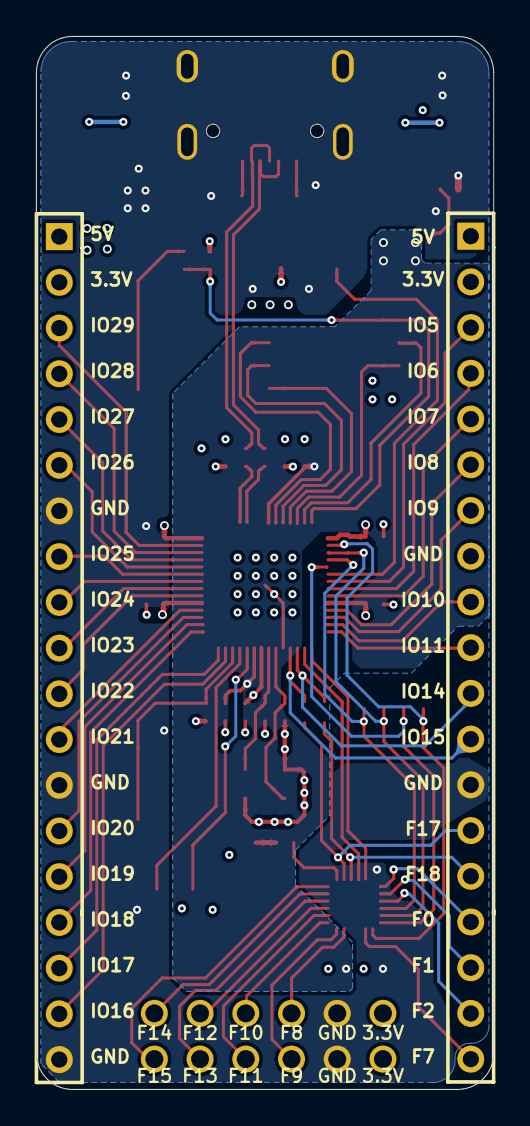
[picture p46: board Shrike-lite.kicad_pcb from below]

Board: 4 copper layers, 25.4 x 58.5 mm, 57 parts (2 on the bottom side), 71 nets.

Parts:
2: TP
C1, C3, C5, C8: 100nF 10V; Cap_0603
C2, C4, C6, C7, C9, C10, C11, C12, C13, C14, C15, C16, C17, C18, C19, C20, C21: Cap_0402
CLK: TP
CS: TP
D1: LED1; LED_0603
D2, D3: LED_0603
GND1: TP
J1: Type-C
J2, J4: Header 19X1_2.54MM; 1X19_HEADER
J3: DNP; 2X6_HEADER
J5: XUNPU WAFER-SH1.0-3PLB
R1: RES_0402_5; Res_0402
R2, R3, R4, R5, R6, R7, R8, R9, R10, R11, R12, R13, R14: Res_0402
SI: TP
SO: TP
SW1: SW PUSHBUTTON; SW_MICRO PUSH BUTTON 4 PAD
SW2: SW PUSHBUTTON; Switch
U1: SOT23-5
U2: SOT25
U3: SOIC-8
U4: RP2040; QFN_56
U5: QFN_24
X1: CRYSTAL_3225

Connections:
1.1V: 2.1, C7.2, C8.2, C11.1, C12.1, C20.1, R4.1, U1.5, U4.23, U4.50, U5.22
3.3V: C3.2, C4.2, C13.1, C14.1, C15.1, C16.1, C17.1, C18.1, C19.1, C21.1, J2.2, J3.1, J3.2, J4.2, R1.1, R9.1, R10.2, U2.5, U3.8, U4.1, U4.10, U4.22, U4.33, U4.42, U4.43, U4.44, U4.48, U4.49, U5.21
BOOT: R11.2, SW2.1, SW2.2
CS0: R9.2, R11.1, U3.1, U4.56
CS1: CS.1, U4.3, U5.17
EN: U4.16, U5.10
F_GPIO0: J2.16, U5.13
F_GPIO1: J2.17, U5.14
F_GPIO2: J2.18, U5.15
F_GPIO7: J2.19, U5.20
F_GPIO8: J3.6, U5.23
F_GPIO9: J3.5, U5.24
F_GPIO10: J3.8, U5.1
F_GPIO11: J3.7, U5.2
F_GPIO12: J3.10, U5.3
F_GPIO13: J3.9, U5.4
F_GPIO14: J3.12, U5.5
F_GPIO15: J3.11, U5.6
F_GPIO16: R6.1, U5.7
F_GPIO17: J2.14, R8.2, U5.8
F_GPIO18: J2.15, R7.2, U5.9
F_SPI_CLK: CLK.1, U4.4, U5.16
F_SPI_SI: SI.1, U4.5, U5.18
F_SPI_SO: SO.1, U4.2, U5.19
GND: C1.1, C2.1, C3.1, C4.1, C5.1, C6.1, C8.1, C9.2, C10.2, C11.2, C12.2, C13.2, C14.2, C15.2, C16.2, C17.2, C18.2, C19.2, C20.2, C21.2, D1.K, D2.K, D3.K, GND1.1, J1.A1, J1.A12, J1.S1, J1.S2, J1.S3, J1.S4, J2.8, J2.13, J3.3, J3.4, J4.7, J4.13, J4.19, J5.2, J5.4, J5.5, R2.2, R3.2, R5.2, SW1.3, SW1.4, SW2.3, SW2.4, U1.2, U2.2, U3.4, U4.19, U4.57, U5.12, X1.2, X1.4
GPIO4: R14.1, U4.6
GPIO5: J2.3, U4.7
GPIO6: J2.4, U4.8
GPIO7: J2.5, U4.9
GPIO8: J2.6, U4.11
GPIO9: J2.7, U4.12
GPIO10: J2.9, U4.13
GPIO11: J2.10, U4.14
GPIO14: J2.11, R7.1, U4.17
GPIO15: J2.12, R8.1, U4.18
GPIO16: J4.18, U4.27
GPIO17: J4.17, U4.28
GPIO18: J4.16, U4.29
GPIO19: J4.15, U4.30
GPIO20: J4.14, U4.31
GPIO21: J4.12, U4.32
GPIO22: J4.11, U4.34
GPIO23: J4.10, U4.35
GPIO24: J4.9, U4.36
GPIO25: J4.8, U4.37
GPIO26: J4.6, U4.38
GPIO27: J4.5, U4.39
GPIO28: J4.4, U4.40
GPIO29: J4.3, U4.41
HOLD: U3.7, U4.51
NetC7_1: C7.1, R4.2, R5.1, U1.4
NetD1_A: D1.A, R1.2
NetD2_A: D2.A, R6.2
NetD3_A: D3.A, R14.2
NetJ1_A5: J1.A5, R3.1
NetJ1_B5: J1.B5, R2.1
PWR: U4.15, U5.11
RUN: R10.1, SW1.1, SW1.2, U4.26
SPI_CLK: U3.6, U4.52
SPI_SI: U3.5, U4.53
SPI_SO: U3.2, U4.55
SWCLK: J5.1, U4.24
SWD: J5.3, U4.25
USB_N: J1.A7, J1.B7, R12.1
USB_P: J1.A6, J1.B6, R13.1
USBx_N: R12.2, U4.46
USBx_P: R13.2, U4.47
VUSB: C1.2, C2.2, C5.2, C6.2, J1.A4, J1.A9, J2.1, J4.1, U1.1, U1.3, U2.1, U2.3
WP: U3.3, U4.54
XIN: C9.1, U4.20, X1.1
XOUT: C10.1, U4.21, X1.3

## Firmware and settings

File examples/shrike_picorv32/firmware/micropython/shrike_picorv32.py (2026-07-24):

# =============================================================================
# shrike_picorv32.py
# Project  : shrike_picorv32  (runtime-programmable RV32I core)
# Board    : Shrike-lite (RP2040) / Shrike (RP2350)
# Firmware : MicroPython (Shrike custom UF2)
# Licence  : GPL-2.0
#
# Flashes the PicoRV32 bitstream, then streams a 32-word RV32I program into the
# FPGA over SPI and runs it -- no re-synthesis, no new bitstream. The CPU writes
# its final result to a memory-mapped GPIO latch (store to 0x40000000); the low
# 2 bits drive FPGA GPIO17/18, hardwired to RP2040 GPIO15/14, read back by the MCU.
#
# RV32I CONFORMANCE SUITE
#   This file holds several themed <=32-word programs (TESTS below). Each is
#   self-checking and latches:
#       3 = PASS   (every instruction it tests behaved correctly)
#       1 = FAIL   (it ran but computed a wrong value)
#       0 = DEAD   (the CPU never reached the store: trap / illegal / hang;
#                   the latch is cleared to 0 on every reload)
#   Together the programs cover the complete RV32I base ISA (37 instructions).
#   Select which one runs by uncommenting exactly one ACTIVE = ... line.
#
#   Each program was machine-generated from RV32I assembly and validated two
#   ways: (a) it returns 3 on a correct core, and (b) injecting a fault into any
#   instruction it tests makes it stop returning 3, so a passing result confirms
#   those instructions are correct.
#
# SPI load protocol (the bootloader FSM in shrike_picorv32_top.v):
#   0xA0          enter load (halt CPU, reset write pointer)
#   <128 bytes>   program image, 32 words x 4 bytes, little-endian
#   0xA2          run (release the CPU)
#   0xA3          halt (re-arm before loading a new program)
#
# Expected output (with ACTIVE = "regalu"):
#   Flashing PicoRV32 bitstream to FPGA...
#   [shrike_flash] FPGA programming done.
#   regalu: testing add sub sll srl sra and or xor slt sltu
#   result = 3 -> PASS
# =============================================================================

import sys
import time
import shrike
from machine import Pin, SPI

# -- Platform configuration ---------------------------------------------------
# SPI:    RP2040 SPI0 wired to the FPGA SPI load pins (same as stack_processor).
# Result: FPGA GPIO17/18 -> RP2040 GPIO15/14 via PCB 0-ohm resistors.
# Shrike-fi (ESP32-S3) trace map is untested; add an esp32 branch once verified.

if sys.platform == 'rp2':
    CONFIG = {
        'platform':  'RP2040/RP2350',
        'spi_id':    0,
        'sck':       2,    # RP2040 GPIO2  -> FPGA spi_sck
        'mosi':      3,    # RP2040 GPIO3  -> FPGA spi_mosi
        'miso':      0,    # RP2040 GPIO0  (unused; FPGA does not drive MISO)
        'cs':        1,    # RP2040 GPIO1  -> FPGA spi_ss_n
        'bit0_pin':  15,   # RP2040 GPIO15 <- FPGA GPIO17 (result bit 0)
        'bit1_pin':  14,   # RP2040 GPIO14 <- FPGA GPIO18 (result bit 1)
        'bitstream': 'shrike_picorv32.bin',
    }
else:
    raise RuntimeError(
        "Unsupported platform: {}. Supported: 'rp2'.".format(sys.platform)
    )

NOP        = 0x00000013
PASS_VALUE = 3

# =============================================================================
# RV32I CONFORMANCE PROGRAMS  (each <=32 words; latches 3 on PASS / 1 / 0)
# -----------------------------------------------------------------------------
# A `# li t2,<expected>` line holds a precomputed checksum the program compares
# its accumulated result against; the arithmetic programs sum every operation's
# result so a wrong answer in any single instruction shifts the total and fails.
# =============================================================================

# --- register-register ALU: add sub sll srl sra and or xor slt sltu ----------
PROG_REGALU = [
    0x00C00293,  # li   t0,12
    0x00300E13,  # li   t3,3
    0xFF400F13,  # li   t5,-12
    0x01C28333,  # add  t1,t0,t3   (=15, seeds the sum)
    0x41C28EB3,  # sub  t4,t0,t3   (=9)
    0x01D30333,  # add  t1,t1,t4
    0x01C29EB3,  # sll  t4,t0,t3   (=96)
    0x01D30333,  # add  t1,t1,t4
    0x01C2DEB3,  # srl  t4,t0,t3   (=1)
    0x01D30333,  # add  t1,t1,t4
    0x01C2EEB3,  # or   t4,t0,t3   (=15)
    0x01D30333,  # add  t1,t1,t4
    0x01C2CEB3,  # xor  t4,t0,t3   (=15)
    0x01D30333,  # add  t1,t1,t4
    0x01C2FEB3,  # and  t4,t0,t3   (=0)
    0x01D30333,  # add  t1,t1,t4
    0x01CF2EB3,  # slt  t4,t5,t3   (=1, signed -12<3)
    0x01D30333,  # add  t1,t1,t4
    0x01CF3EB3,  # sltu t4,t5,t3   (=0, unsigned huge<3)
    0x01D30333,  # add  t1,t1,t4
    0x41CF5EB3,  # sra  t4,t5,t3   (=-2, arithmetic -12>>3)
    0x01D30333,  # add  t1,t1,t4
    0x09600393,  # li   t2,150     (expected sum)
    0x00100513,  # li   a0,1       (fail marker)
    0x00731463,  # bne  t1,t2,STORE
    0x00300513,  # li   a0,3       (pass marker)
    0x400004B7,  # lui  s1,0x40000000
    0x00A4A023,  # sw   a0,0(s1)
    0x0000006F,  # j    .          (halt)
]

# --- register-immediate + upper: addi slli srli srai andi ori xori -----------
#                                 slti sltiu lui auipc
PROG_IMMALU = [
    0x00D00293,  # li   t0,13
    0xFF300F13,  # li   t5,-13
    0x00528313,  # addi t1,t0,5    (=18, seeds the sum)
    0x00229E93,  # slli t4,t0,2    (=52)
    0x01D30333,  # add  t1,t1,t4
    0x0022DE93,  # srli t4,t0,2    (=3)
    0x01D30333,  # add  t1,t1,t4
    0x402F5E93,  # srai t4,t5,2    (=-4, arithmetic)
    0x01D30333,  # add  t1,t1,t4
    0x0062FE93,  # andi t4,t0,6    (=4)
    0x01D30333,  # add  t1,t1,t4
    0x0022EE93,  # ori  t4,t0,2    (=15)
    0x01D30333,  # add  t1,t1,t4
    0x0062CE93,  # xori t4,t0,6    (=11)
    0x01D30333,  # add  t1,t1,t4
    0x000F2E93,  # slti t4,t5,0    (=1, signed -13<0)
    0x01D30333,  # add  t1,t1,t4
    0x001F3E93,  # sltiu t4,t5,1   (=0, unsigned huge<1)
    0x01D30333,  # add  t1,t1,t4
    0x00001EB7,  # lui  t4,1       (=0x1000)
    0x00CEDE93,  # srli t4,t4,12   (=1, recover the upper immediate)
    0x01D30333,  # add  t1,t1,t4
    0x00000E97,  # auipc t4,0      (=PC of this instruction)
    0x01D30333,  # add  t1,t1,t4
    0x0BD00393,  # li   t2,189     (expected sum: 101 + PC(=88))
    0x00100513,  # li   a0,1       (fail marker)
    0x00731463,  # bne  t1,t2,STORE
    0x00300513,  # li   a0,3       (pass marker)
    0x400004B7,  # lui  s1,0x40000000
    0x00A4A023,  # sw   a0,0(s1)
    0x0000006F,  # j    .          (halt)
]

# --- branches (each tested BOTH taken and not-taken): beq bne blt bge --------
#                                                      bltu bgeu
PROG_BRANCH = [
    0x00500293,  # li   t0,5
    0x00500E13,  # li   t3,5
    0x00700E93,  # li   t4,7
    0xFFD00F13,  # li   t5,-3
    0x01C28463,  # beq  t0,t3,+8     (must take: 5==5)
    0x04C0006F,  # j    FAIL
    0x05D28463,  # beq  t0,t4,FAIL   (must NOT take: 5==7)
    0x01D29463,  # bne  t0,t4,+8     (must take: 5!=7)
    0x0400006F,  # j    FAIL
    0x03C29E63,  # bne  t0,t3,FAIL   (must NOT take: 5!=5)
    0x005F4463,  # blt  t5,t0,+8     (must take: -3<5 signed)
    0x0340006F,  # j    FAIL
    0x03E2C863,  # blt  t0,t5,FAIL   (must NOT take: 5<-3)
    0x01C2D463,  # bge  t0,t3,+8     (must take: 5>=5)
    0x0280006F,  # j    FAIL
    0x025F5263,  # bge  t5,t0,FAIL   (must NOT take: -3>=5)
    0x01D2E463,  # bltu t0,t4,+8     (must take: 5<7 unsigned)
    0x01C0006F,  # j    FAIL
    0x005F6C63,  # bltu t5,t0,FAIL   (must NOT take: huge<5)
    0x005F7463,  # bgeu t5,t0,+8     (must take: huge>=5 unsigned)
    0x0100006F,  # j    FAIL
    0x01D2F663,  # bgeu t0,t4,FAIL   (must NOT take: 5>=7)
    0x00300513,  # li   a0,3         (every branch behaved)
    0x0080006F,  # j    STORE
    0x00100513,  # FAIL: li a0,1
    0x400004B7,  # lui  s1,0x40000000
    0x00A4A023,  # sw   a0,0(s1)
    0x0000006F,  # j    .            (halt)
]

# --- jumps (control transfer AND link register): jal jalr --------------------
PROG_JUMPS = [
    0x008000EF,  # jal  ra,JT        (ra = PC+4)
    0x00100093,  # addi ra,zero,1    (poison link; must be skipped)
    0x00400393,  # JT: li t2,4       (expected jal link)
    0x02709063,  # bne  ra,t2,FAIL
    0x00000297,  # auipc t0,0        (t0 = &this)
    0x00C280E7,  # jalr ra,t0,12     (ra = PC+4; jump to TGT)
    0x00100093,  # addi ra,zero,1    (poison link; must be skipped)
    0x01800393,  # TGT: li t2,24     (expected jalr link)
    0x00709663,  # bne  ra,t2,FAIL
    0x00300513,  # li   a0,3
    0x0080006F,  # j    STORE
    0x00100513,  # FAIL: li a0,1
    0x400004B7,  # lui  s1,0x40000000
    0x00A4A023,  # sw   a0,0(s1)
    0x0000006F,  # j    .            (halt)
]

# --- loads (all widths + sign/zero extension): lw lh lhu lb lbu --------------
PROG_LOADS = [
    0x05802303,  # lw   t1,(Dw)      -> 3
    0x00300393,  # li   t2,3
    0x04731063,  # bne  t1,t2,FAIL
    0x05C04303,  # lbu  t1,(D80)     -> 128 (zero-extended)
    0x08000393,  # li   t2,128
    0x02731A63,  # bne  t1,t2,FAIL
    0x05C00303,  # lb   t1,(D80)     -> -128 (sign-extended)
    0xF8000393,  # li   t2,-128
    0x02731463,  # bne  t1,t2,FAIL
    0x06005303,  # lhu  t1,(D8000)   -> 0x8000 (zero-extended)
    0x00F35313,  # srli t1,t1,15     -> 1  (proves the top bit was zero-filled)
    0x00100393,  # li   t2,1
    0x00731C63,  # bne  t1,t2,FAIL
    0x06401303,  # lh   t1,(Dh)      -> -2048 (sign-extended)
    0x80000393,  # li   t2,-2048
    0x00731663,  # bne  t1,t2,FAIL
    0x00300513,  # li   a0,3
    0x0080006F,  # j    STORE
    0x00100513,  # FAIL: li a0,1
    0x400004B7,  # lui  s1,0x40000000
    0x00A4A023,  # sw   a0,0(s1)
    0x0000006F,  # j    .            (halt)
    0x00000003,  # Dw:    .word 0x00000003
    0x00000080,  # D80:   .word 0x00000080
    0x00008000,  # D8000: .word 0x00008000
    0xFFFFF800,  # Dh:    .word 0xFFFFF800
]

# --- stores (each latches the result through the GPIO write path) ------------
# Only the GPIO latch is observable (no data RAM), so each store width is tested
# as the SOLE store of the value 3: PASS(3) if it executes, DEAD(0) if it traps.
PROG_STORE_SW = [
    0x00300513,  # li   a0,3
    0x400004B7,  # lui  s1,0x40000000
    0x00A4A023,  # sw   a0,0(s1)
    0x0000006F,  # j    .            (halt)
]
PROG_STORE_SH = [
    0x00300513,  # li   a0,3
    0x400004B7,  # lui  s1,0x40000000
    0x00A49023,  # sh   a0,0(s1)
    0x0000006F,  # j    .            (halt)
]
PROG_STORE_SB = [
    0x00300513,  # li   a0,3
    0x400004B7,  # lui  s1,0x40000000
    0x00A48023,  # sb   a0,0(s1)
    0x0000006F,  # j    .            (halt)
]

# name -> (instructions it covers, program words). Union = full RV32I base ISA.
TESTS = {
    "regalu":   ("add sub sll srl sra and or xor slt sltu",                     PROG_REGALU),
    "immalu":   ("addi slli srli srai andi ori xori slti sltiu lui auipc",      PROG_IMMALU),
    "branch":   ("beq bne blt bge bltu bgeu",                                   PROG_BRANCH),
    "jumps":    ("jal jalr",                                                    PROG_JUMPS),
    "loads":    ("lw lh lhu lb lbu",                                            PROG_LOADS),
    "store_sw": ("sw",                                                          PROG_STORE_SW),
    "store_sh": ("sh",                                                          PROG_STORE_SH),
    "store_sb": ("sb",                                                          PROG_STORE_SB),
}

# -- Pick ONE program to run (uncomment exactly one) --------------------------
ACTIVE = "regalu"
# ACTIVE = "immalu"
# ACTIVE = "branch"
# ACTIVE = "jumps"
# ACTIVE = "loads"
# ACTIVE = "store_sw"
# ACTIVE = "store_sh"
# ACTIVE = "store_sb"

# -- SPI bootloader helpers ---------------------------------------------------
spi = SPI(CONFIG['spi_id'],
          baudrate=1_000_000, polarity=0, phase=0,
          bits=8, firstbit=SPI.MSB,
          sck=Pin(CONFIG['sck']), mosi=Pin(CONFIG['mosi']), miso=Pin(CONFIG['miso']))
cs = Pin(CONFIG['cs'], Pin.OUT, value=1)


def spi_cmd(byte):
    """Send one byte as its own chip-select frame (one bootloader FSM step)."""
    cs.value(0)
    spi.write(bytes([byte & 0xFF]))
    cs.value(1)


def load_and_run(words):
    """Stream <=32 words into the FPGA instruction RAM and start the CPU."""
    image = (list(words) + [NOP] * 32)[:32]   # pad/truncate to exactly 32 words
    spi_cmd(0xA3)                              # halt + re-arm
    spi_cmd(0xA0)                              # enter load
    for w in image:                            # 128 little-endian bytes
        spi_cmd(w)
        spi_cmd(w >> 8)
        spi_cmd(w >> 16)
        spi_cmd(w >> 24)
    spi_cmd(0xA2)                              # run


def flash_bitstream():
    """Load the FPGA bitstream and let the fabric settle. Call once at start."""
    shrike.flash(CONFIG['bitstream'])
    time.sleep(1)


def read_result(settle=0.3):
    """Sample the 2-bit CPU result latch (FPGA GPIO17/18 -> RP2040 GPIO15/14).

    Returns 0..3. A program stores 3 for PASS; 1 means it ran but computed a
    wrong value; 0 means the CPU never reached its result store (trap / hang) --
    the latch clears on every reload."""
    time.sleep(settle)                         # the CPU finishes in microseconds
    bit0 = Pin(CONFIG['bit0_pin'], Pin.IN).value()
    bit1 = Pin(CONFIG['bit1_pin'], Pin.IN).value()
    return (bit1 << 1) | bit0


# -- Flash, load the ACTIVE program, run, report ------------------------------
# Copy bitstream/shrike_picorv32.bin to the board filesystem before running.
# Running this file directly executes the ACTIVE program; importing it just
# exposes the helpers + TESTS (so other scripts can drive the board).

if __name__ == '__main__':
    covers, program = TESTS[ACTIVE]

    print("Flashing PicoRV32 bitstream to FPGA...")
    flash_bitstream()

    print("{}: testing {}".format(ACTIVE, covers))
    load_and_run(program)

    result = read_result(settle=0.5)
    if result == PASS_VALUE:
        print("result = {} -> PASS  (verified: {})".format(result, covers))
    elif result == 0:
        print("result = 0 -> DEAD  (CPU never stored a result: trap / hang?)")
    else:
        print("result = {} -> FAIL  (ran but a tested instruction is wrong)".format(result))

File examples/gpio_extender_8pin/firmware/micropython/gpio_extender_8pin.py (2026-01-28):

from machine import Pin, SPI
import time

# --- Hardware Configuration ---
# Based on your confirmed mapping
sck_pin  = Pin(2)
mosi_pin = Pin(3)
miso_pin = Pin(0)
ss_pin   = Pin(1, Pin.OUT, value=1)
rst_pin  = Pin(14, Pin.OUT, value=1)

# Probe pin to read physical FPGA output
probe = Pin(15, Pin.IN) 

# SPI0 Initialization (CPOL=0, CPHA=0)
spi = SPI(0, baudrate=1_000_000, sck=sck_pin, mosi=mosi_pin, miso=miso_pin)

# --- Register Addresses (From Verilog Case Statement) ---
ADDR_DIR_LOW  = 0x1 # gpio_dir_reg[3:0]
ADDR_DIR_HIGH = 0x2 # gpio_dir_reg[7:4]
ADDR_OUT_LOW  = 0x3 # gpio_out_reg[3:0]
ADDR_OUT_HIGH = 0x4 # gpio_out_reg[7:4]

def send_cmd(addr, data):
    """Sends command and returns the current physical state of the 8 GPIOs"""
    packet = (addr << 4) | (data & 0x0F)
    ss_pin.value(0)
    # The MISO return value reflects i_gpio_pins
    read_byte = spi.read(1, packet)[0]
    ss_pin.value(1)
    return read_byte

def reset_fpga():
    print("Action: Resetting FPGA Core...")
    rst_pin.value(0)
    time.sleep(0.1)
    rst_pin.value(1) # De-assertion synchronized internally
    time.sleep(0.1)

# --- Test Suite ---
def run_tests():
    reset_fpga()
    
    # TEST 1: Default State Verification
    # On reset, all pins should be Inputs (High-Z)
    initial_state = send_cmd(0x0, 0x0)
    print(f"Test 1: Reset State - Read: {bin(initial_state)} (Expected: All Inputs)")

    # TEST 2: Lower Nibble Output Drive
    print("\nTest 2: Lower Nibble (Pins 20, 23, 24, 1) Drive Test")
    send_cmd(ADDR_DIR_LOW, 0x0) # Set lower 4 bits to Output (0)
    print("Action: Connect Jumper from RP2040 GPIO 15 to FPGA Pin 20 (Bit 0)")
    
    for val in [0x1, 0x2, 0x4, 0x8]: # Walking 1s
        send_cmd(ADDR_OUT_LOW, val)
        time.sleep(0.1)
        # Physical check on Bit 0 (only if val is 0x1)
        if val == 0x1:
            print(f" - Bit 0 High Check: {'PASS' if probe.value() == 1 else 'FAIL'}")
        send_cmd(ADDR_OUT_LOW, 0x0) # Clear
        time.sleep(0.1)

    # TEST 3: Upper Nibble Independent Drive
    print("\nTest 3: Upper Nibble (Pins 2, 3, 4, 5) Drive Test")
    send_cmd(ADDR_DIR_HIGH, 0x0) # Set upper 4 bits to Output (0)
    print("Action: Move Jumper to FPGA Pin 2 (Bit 4)")
    
    send_cmd(ADDR_OUT_HIGH, 0x1) # Set Bit 4 High
    time.sleep(0.1)
    print(f" - Bit 4 High Check: {'PASS' if probe.value() == 1 else 'FAIL'}")
    
    # TEST 4: Persistence Check
    # Ensure writing upper nibble didn't overwrite lower nibble output state
    send_cmd(ADDR_OUT_LOW, 0x1) # Bit 0 High
    send_cmd(ADDR_OUT_HIGH, 0x8) # Bit 7 High
    # Both should now be high in the readback
    current_read = send_cmd(0x0, 0x0)
    print(f"Test 4: Persistence Read - {bin(current_read)} (Should see bits 0 and 7 High)")

    # TEST 5: Input Mode (Tristate) Verification
    print("\nTest 5: Tristate/Input Mode Check")
    send_cmd(ADDR_DIR_LOW, 0xF) # Set Lower to Input (1)
    print("Action: Connect FPGA Pin 20 to 3.3V")
    time.sleep(2) # Give user time to connect
    input_read = send_cmd(0x0, 0x0)
    print(f" - Pin 20 (Bit 0) High Input Detection: {'PASS' if (input_read & 0x01) else 'FAIL'}")

run_tests()

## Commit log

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2025-11-17 Removed Arduino from list
2025-11-20 feat(examples) : Add the Debouncer Example. This example is used to debounce any switch or button coming into the FPGA. Does not allow the output of the switch to change unless the switch is steady f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
2025-11-25 update the arduino guide for v 2.x.x and introduce tabs
2025-11-28 docs : add flash info and update arduino guide
2025-12-03 feat(debouncer): Add support for multi debouncer instances and update README
    - Split the design into two modules:
    a single-channel debouncer module and a top module that instantiates
    multiple debouncer instances using a generate loop.
    - Added the NUM_PORTS parameter for scalable multi-instance support.
    - Updated the README to reflect the new design flow and testing workflow.
2025-12-04 (feat) debouncer: Add sketch for debouncer
    Adds Arduino IDE sketch for debouncer example on ShrikeLite.
    RP2040 receives debounced pin status from FPGA for its operations.
    [RP2040]<---------[FPGA]<----------[Button]
    (i/p: GPIO2) (i/p GPIO0(F0))
    (o/p GPIO3)
2025-12-04 feat(ultrasonic): Add initial support for multi ultrasonic instances example
    - Adds the initial support for ultrasonic example.
    - This example has ultrasonic_sensor module, that will generate
    the trig pulse and recevies the echo.Based on the time,
    calculates the time and detects whether the object is in
    the range or not.
    - The top module instantiates multiple ultrasonic instances
    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
2025-12-09 [Fix] Docs: Correct pinout for Shrike-lite (#16)
    Maps Shrike-lite pinout as per RP2040
    SPI0 CSn | UART1 RX | I2C0 SCL <- IO5 ◦ ◦ IO29 -> SPI1 CSn | UART0 RX | I2C0 SCL
    SPI0 SCK | | I2C1 SDA <- IO6 ◦ ◦ IO28 -> SPI1 RX | UART0 TX | I2C0 SDA
    SPI0 TX | | I2C1 SCL <- IO7 ◦ ◦ IO27 -> SPI1 TX | | I2C1 SCL
    SPI1 RX | UART1 TX | I2C0 SDA <- IO8 ◦ ◦ IO26 -> SPI1 SCK | | I2C1 SDA
    SPI1 CSn | UART1 RX | I2C0 SCL <- IO9 ◦ ◦ GND
    GND ◦ ◦ IO25 -> SPI1 CSn | UART1 RX | I2C0 SCL
    SPI1 SCK | | I2C1 SDA <- IO10 ◦ ◦ IO24 ->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
2025-12-10 Added uart_sum example (Add two 8-bit numbers on FPGA and return result via UART) (#23)
    * Added uart_sum example
2025-12-11 add spi loopback and led controller example
2025-12-19 Add Stack Processor (SPI-Controlled) example
2026-01-06 add shrike-ctl utility : flasher utility for fpga from host PC (#21)
    * add shrike-ctl utility
    -Raised the serial transfer chunk size from 64 bytes to the full .bin size.
    -Transfer time results (file size: 46,408 bytes):
    -64-byte chunks → ~10.7 seconds
    -full-file chunk(46,408-byte) → ~3.5 seconds
2026-01-22 Make a New Example of a 8-pin and 14-pin FPGA GPIO Extentder
2026-01-26 4-Bit Up/Down Counter 🧮
2026-01-30 hardware: add pcb layout for shrike-lite
    [FPGA.kicad_sch, Power.kicad_sch, RP2040.kicad_sch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]
2026-02-13 hardware:add schematics file for Shrike(rp2350)
2026-02-17 fix : fix reset style in i2c_led example
    [i2c_led.py]
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2026-03-20 (feat) uart_sum: Add Arduino sketch for uart_sum example
    - Adds an Arduino IDE sketch for the uart_sum example on Shrike
    - RP2040 sends two bytes over UART to the FPGA
    - FPGA computes the sum and sends the result back to RP2040
    UART Connections :
    [RP2040] <---------> [FPGA]
    Tx (GPIO0) ----------> Rx (GPIO6)
    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
2026-03-21 docs(readme): update reference URLs for debouncer and ultrasonic examples
    Update outdated reference links in README files for debouncer and ultrasonic examples.
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2026-04-19 example : Morse code encoder and blinker (#53)
    add example morse code encoder and blinker
2026-05-22 examples:n make spi_loopback_led code platform agnostic
    This code can work on Shrike lite and Shrike Fi both.
    There is no need to change the code whatsoever while
    using it on either boards.
2026-05-23 readme : Correct PSRAM capacity in README
    Updated PSRAM capacity from 'Upto 16 MB' to 'Upto 8 MB'.
2026-05-25 feat(quadrature_decoder): Add initial support for quadrature decoder example
    Adds the initial support for quadrature decoder example.
    - This example implements a complete quadrature decoder inside FPGA using
    encoder A/B signals.
    - The FPGA detects forward and reverse transitions, calculates signed position,
    rotational speed and angular displacement based on CPR.
    - UART packetizer module sends decoded position, speed, angle and direction
    data to RP2040.
    - UART TX module serializes packet data and transmits it over FPGA UART output.
    - Adds Arduino IDE sketch for quadrature decoder example on ShrikeLite.
    - RP2040 receives UART packets from FPGA and decodes: Signed position,
    Signed speed, Angle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
    [quadrature_decoder.ino]
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2026-05-27 Fix PSRAM_test folder upload
    [PSRAM_test.ino]
2026-05-29 utils : add arduino suport for shrike-fi wifi flash util (#69)
    feat: added new example fpga flash over wifi using Arduino IDE
2026-05-30 example : update spi_loopback example readme (#64)
    * updated spi_status
    * updated pin assignment for shrike fi
    * Update pin mapping table for ESP32 S3
    ---------
2026-06-02 fix: shrike_picorv32 full RV32I core (read-latency, branches, 32 registers)
    [shrike_picorv32.py]
2026-06-02 feat: shrike_picorv32 runtime-programmable over SPI (BRAM imem, 4-slice regfile)
2026-06-15 feat: add usb_to_spi example
    USB-to-SPI bridge for Shrike-Lite: PC USB -> RP2040 (SPI master) -> FPGA
    -> external SPI slave (Arduino Uno). The FPGA is an SPI target on the
    RP2040 link and an SPI master on free GPIOs to the external device.
    Includes Verilog (top, spi_target, spi_master), MicroPython firmware,
    Arduino slave sketch, pre-built bitstream, images, and README.
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2026-06-24 Merge pull request #95 from Deagle2/feat/led-reaction-timer
    feat: led reaction timer
2026-07-01 Merge pull request #92 from keshav191106/feat/spi-to-uart
    feat: added spi to uart bridge example
2026-07-02 Merge pull request #97 from vineet-hub7/feat/add-spi-to-usb-bridge
    feat: add spi to usb bridge example
2026-07-08 Merge pull request #105 from keshav191106/feat/i2c-to-spi
    added I2C to SPI protocol bridge example
2026-07-11 Move PSRAM_test from examples/ to test/
    It's Shrike-fi hardware validation, example — it belongs
    next to test/shrike-fi/.
2026-07-24 Merge pull request #116 from spr4bhu/fix-shrike-picorv32
    fix: shrike_picorv32 BRAM port/clock pinning and 25 MHz PLL clock
    [shrike_picorv32.py]
2026-07-25 Merge pull request #120 from vineet-hub7/add-spi-to-i2c-bridge
    Add SPI-to-I2C bridge example to protocol_translator
2026-07-25 Merge pull request #119 from vineet-hub7/add-uart-to-i2c-bridge
    Add UART-to-I2C bridge example to protocol_translator
2026-07-25 Merge pull request #118 from vineet-hub7/add-i2c-to-uart-bridge
    Add I2C-to-UART bridge example to protocol_translator
